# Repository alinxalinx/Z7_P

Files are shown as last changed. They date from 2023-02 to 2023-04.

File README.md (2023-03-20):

# Xilinx Zynq Ultrascale+ MPSoC Series Development Board Z7_P
## Introduction to Development Board
The entire structure of the development board is designed based on our consistent core board+extension board pattern. Core board and expansion board
High speed inter board connectors are used for connection. The backplane extends a variety of peripheral interfaces for the core board, including 1 channel FMC_ LPC, 1-way M.2 SSD interface, 1-way mini_ DP interface, 2-way SFP optical fiber interface, 4 USB 3.0 interfaces, 2-way Gigabit Ethernet interface, 1-way HDMI
Input, 1-way HDMI output, 2-way UART interface, 1-way PCIEX8 gold finger, 2-way CAN bus interface, 2-way
RS485 interface, 1-way MIPI interface, some key LEDs.
## Key Features
1. One PCIe 3.0 x8 (pl) with a rate of 8Gbps
2. 1-way M.2 interface, PCIEx1 (ps), speed 6Gbps
3. 1-channel DP output interface, mini DP (ps), maximum support 4kx2k@30fps Output
4. 4-way USB 3.0 interface, USB (ps), speed 5.0Gbps, flat USB interface (USB Type A)
5. One channel of HDMI2.0 input interface and one channel of HDMI2.0 output interface are both at the pl end, with the highest 4kx2k@60fps output
6. 2-way Gigabit Ethernet interface, jl2121, 1-way ps, 1-way pl, rgmii interface
7. 2-way SFP optical fiber interface (pl), with a speed of 12.5Gb/s
8. 1 Micro SD card holder (ps)
9. 1-way mipi interface (pl), 15PIN FPC connector, 2 lane data, 1 pair of clocks
10. 1 FMC LPC expansion port
11. 2-way CAN communication interface (ps)
12. 2-way 485 communication interface (PL)
13. One RTC real-time clock, 32.768KHz passive clock (ps)
14. EEPROM and temperature sensor, one EEROM 4Kbit (2x256x8bit) (ps), one LM75 temperature chip (ps), with an accuracy of 0.5 degrees
15. Four LED lights, one Done indicator light, one power supply, one PL control, and one PS control
16. One reset button reset, two user buttons
17. One 4-digit dial switch, and the board supports four startup modes
18. Size 200mm x 106.65mm
19. Power supply 12v/3A

# Z7_P Demo Project
## Description
This is vivado factory demo project for ALINX board.
## Requirement
* Vivado 2020.1
* Z7_P Development Board
## Create Vivado Project
* Download recent release ZIP archive.
* Create new project folder.
* Extract the download ZIP to the new project folder.

There are two methods to create vivado project as below:
### Create Vivado Project in Vivado tcl console
1. Open Vivado software and switch to "**auto_create_project**" path with **cd** command and **Enter**
```
cd \<archive extracted location\>/vivado/auto_create_project
```
2. Type **source ./create_project.tcl** and **Enter**
```
source ./create_project.tcl
```

### Create Vivado Project using bat
1. In "**auto_create_project**" folder, there is "**create_project.bat**", open it in edit mode, and change to your own vivado software installation path. Save and close.
```
CALL E:\XilinxVitis\Vivado\2020.1\bin\vivado.bat -mode batch -source create_project.tcl
PAUSE
```
2. Double click bat file in Windows environment

For more information, please post on the [ALINX Website] (https://www.alinx.com/en).

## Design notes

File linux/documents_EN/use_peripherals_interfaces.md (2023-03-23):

[Back to Home](../)
## Use the interfaces and peripherals on the development board in LINUX
---
-These interfaces and peripherals are available on the Z7-P development boards :\
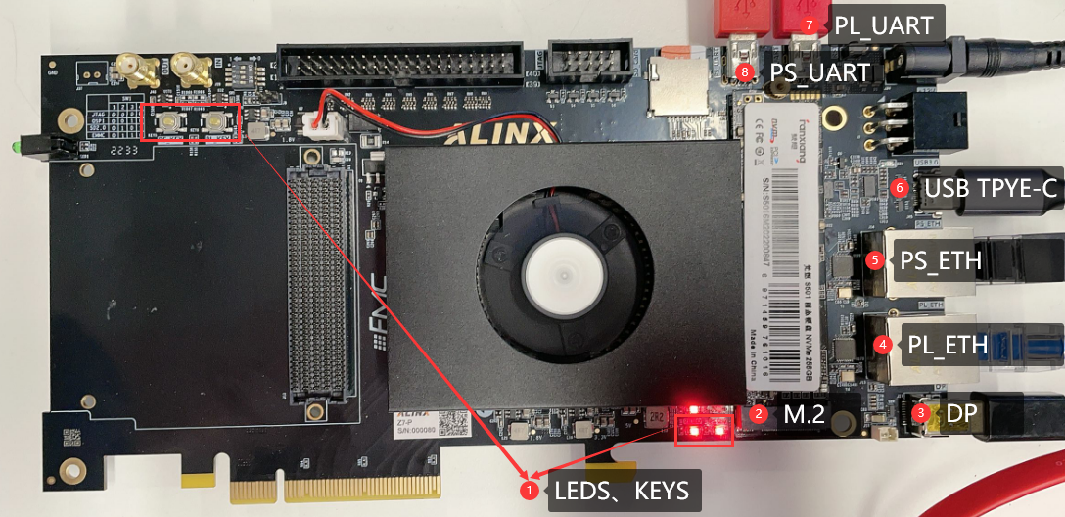
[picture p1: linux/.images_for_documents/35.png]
\
①LEDS、KEYS\
②M.2\
③DP\
④PL_ETH\
⑤PS_ETH\
⑥USB TYPE-C\
⑦PL_UART\
⑧PS_UART\
⑨EMMC(Not visible in the image)\
⑩EEPROM(Not visible in the image)\
⑪QSPI FLASH(Not visible in the image)\
⑫RTC(Not visible in the image)\
⑬LM75(Not visible in the image)\
PS : In the Linux system on the development board created earlier, I integrated some scripts in Path *~/shells_for_testing_peripheral_devices/* to test these interfaces and peripherals. You can also refer to these scripts to use these interfaces and peripherals :\
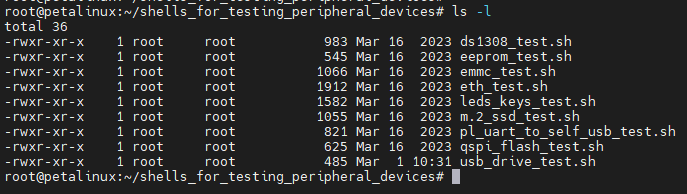
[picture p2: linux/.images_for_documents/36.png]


---
### ①LEDS、KEYS
#### 1.1LEDs and KEYs on the development board
In addition to the POWER light and the RESET button, there are two sets of LEDs and KEY on the development board, namely, the LED and KEY on the PS side and the LED and KEY on the PL side :\
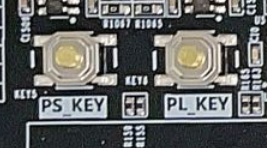
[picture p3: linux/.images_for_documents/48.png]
\
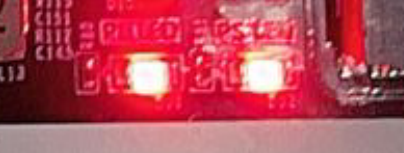
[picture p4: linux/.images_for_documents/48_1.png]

#### 1.2How to use LEDs and KEYs in Linux
Using LEDs and KEYs is actually configuring and using GPIO. In Linux, you only need to know the GPIO number to use the corresponding IO port. The GPIO number of PS_LED is 377, the GPIO number of PS_KEY is 373, the GPIO number of PL_LED is 507, and the GPIO number of PL_KEY is 510.\
The IO corresponding to an LED needs to be configured for output. Taking a PS_LED as an example, the steps to use GPIO output are as follows :
```
#Export the corresponding port
echo 377 >> /sys/class/gpio/export
#Set this port as output
echo out >> /sys/class/gpio/gpio377/direction
#Make this port output high level to turn on the LED
echo 1 >> /sys/class/gpio/gpio377/value
#Make this port output low level to turn off the LED
echo 0 >> /sys/class/gpio/gpio377/value
```
The IO corresponding to KEY needs to be configured as output. Taking PL_KEY as an example, the steps to use GPIO input are as follows :
```
#Export the corresponding port
echo 510 >> /sys/class/gpio/export
#Set this port as input
echo in >> /sys/class/gpio/gpio510/direction
#Read the current level state of this IO
cat /sys/class/gpio/gpio510/value
```

#### 1.3Use the built-in scripts to test LEDs and KEYs
Run the *~/shells_for_testing_peripheral_devices/* script in *leds_keys_test.sh* (*ps: Press **ctrl+c** to exit the script.*). Then you can use PS_KEY to control the turning on and off of the PS_LED, and PL_KEY to control the turning on and off of the PS_LED :\


---
### ②M.2
#### 2.1What is M.2
M.2 is a high-speed, low-power interface for connecting external devices, such as solid-state hard disk, NVMe devices, etc.\
M.2 Interface consists of PCI Express (PCIe) and SATA (Serial ATA) protocols, which can be used for data transmission, storage and communication. PCIe protocol provides faster transmission speed and more bandwidth, while SATA protocol is more suitable for low-power and high-capacity storage devices.
#### 2.2Use M.2 interface in the system
Take SSD equipment as an example, connect SSD on the M.2 interface of the development board (please do not operate with power) :\
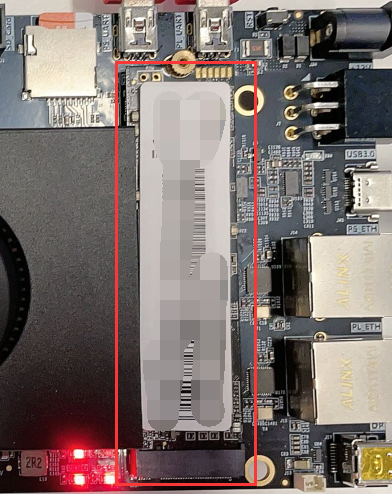
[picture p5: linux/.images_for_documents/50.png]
\
Then start the development board and log in to Linux. If you can find */dev/nvme0n1*, it means that the SSD has been successfully recognized.\
If this SSD has been partitioned, you can also find the device operation files corresponding to partitions like */dev/nvme0n1p1*, */dev/nvme0n1p2* and so on.\
If the SSD does not have a partition or the file system format of the partition is not supported by the Linux system, you can use the **fdisk** tool to allocate the partition, use the **mkfs** tool to set the file system formart, and use the **mount** command to mount it.
For example, the following command will delete the first partition of  */dev/nvme0n1*  and create a new partition, then format the partition into ext4 and mount it to */run/media/nvme0n1p1* :\
```
#Unmount partition
umount /dev/nvme0n1p1
#Delete a partition of /dev/nvme0n1 and create a new partition
echo "d

n
p
1

w
" | fdisk /dev/nvme0n1
#Format the /dev/nvme0n1p1 partition into ext4
echo "y

" | mkfs.ext4 /dev/nvme0n1p1
#mount /dev/nvme0n1p1 on /run/media/nvme0n1p1
mount /dev/nvme0n1p1 /run/media/nvme0n1p1
```
After mounting, you can operate on files in the mounted path, and these files will eventually be saved in the SSD.
#### 2.3Use the built-in script in Linux to test M.2 SSD
Run the *m.2_ssd_test.sh*  script in *~/shells_for_testing_peripheral_devices/* :\
\
Different information will be printed according to the usage of your SSD, but as long as the M.2 interface and SSD are intact, \"*ssd read write OK* \" will be output.

---
### ③DP
#### 3.1What is DP
DP (DisplayPort) interface is a digital video and audio interface standard used to connect computers, televisions, monitors, audio and other equipment. It is an open standard developed by Video Electronics Standards Association (VESA).\
There are two physical interfaces of DP interface, one is the standard DP interface in rectangular shape, and the other is the Mini DP interface in circular shape. The Mini DP interface is used on our development board.
#### 3.2Using DP in Linux
Connect DP to the display, and you can see the desktop of Macthbox after the system is started :\
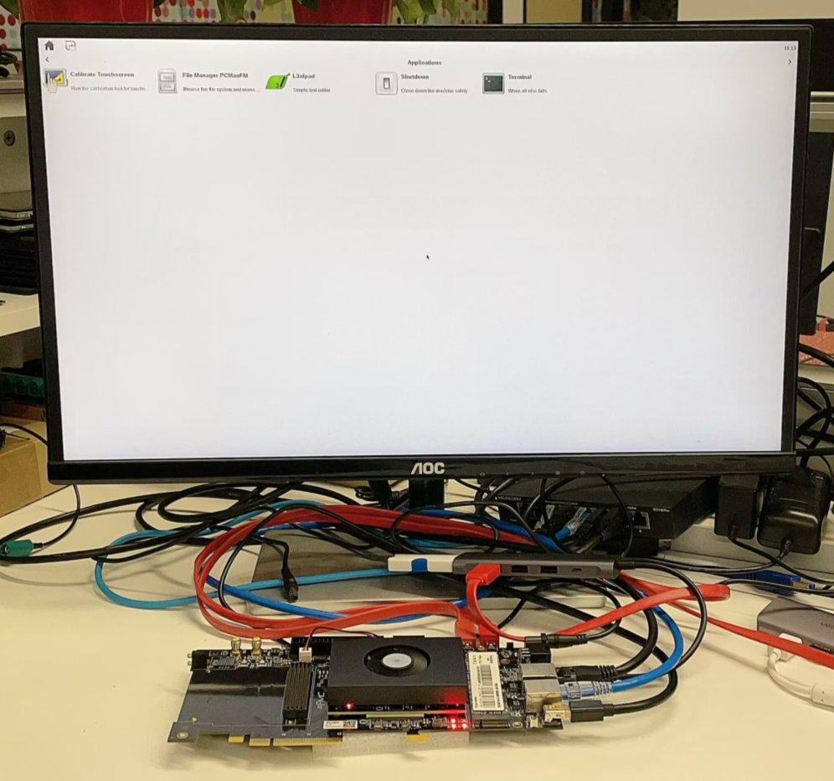
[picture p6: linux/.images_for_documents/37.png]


---
### ④PL_ETH
**See ⑤PS_ETH**。

---
### ⑤PS_ETH
#### 5.1What is ETH
In the Linux operating system, \"ETH\" usually refers to the network interface device, which is the hardware device used to communicate between the computer and the network. In Linux, you can use the *ifconfig* command to manage and configure network interface devices. The development board and other network devices can be connected in the same network through the ETH interface for data transmission.\
In the Ethernet protocol, each device is assigned a unique MAC address for identification and communication in the network. When computers send data through network interface devices, they will be encapsulated in Ethernet frames and routed and transmitted using MAC addresses.\
The PS_ETH on the development board is the ETH on the PS side, and the PS_ETH is the ETH on the PL side implemented by IP, but their use methods are the same in the system.
#### 5.2Using ETH in Linux
Connect PS_ETH and PL_ETH (such as through network router or network switch) to the LAN :\
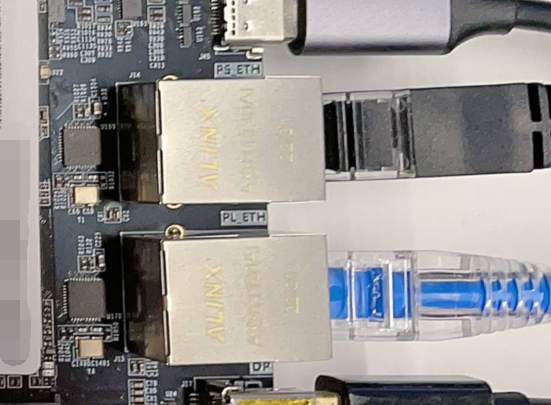
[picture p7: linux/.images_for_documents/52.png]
\
Then power on the development board, log in to the system, and use *ifconfig* to view the current ETH status :\
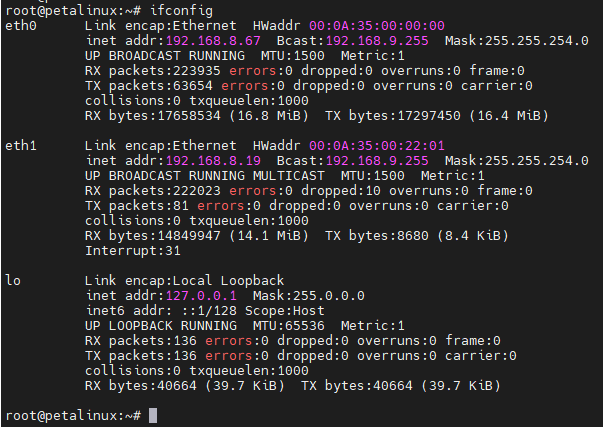
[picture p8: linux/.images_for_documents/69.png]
\
If your router or switch supports DHCP, both eth0 and eth1 will be automatically connected and be assigned an IP address.\
If no IP address is assigned, you need to use the following command to assign it manually, for example :\
`ifconfig eth0 192.168.8.67`\
The *ifconfig* command can also be used to set the subnet mask; If the MAC address needs to be modified, */etc/network/interfaces* needs to be modified; If you want to set the gateway, you need to use command **route**; If you need to modify DNS, you need to modify */etc/resolv.conf*. The relevant configuration will not be detailed, generally, as long as you connect to the LAN through the network cable, you can use eth0 directly after the system is powered on.\
If you want to use eth1, you need to set the default gateway of eth1. The address of the gateway depends on your LAN. If your eth1 and eth0 are connected to the same segment of the same LAN, you can refer to the settings of eth0, for example :
```
#Use route to view the gateway of eth0 first
route
#Set the default gateway of eth1 to be the same as eth0. For example the above route command shows that the default gateway of eth0 is 192.168.8.1
route add default gw 192.168.8.1 eth1
#Use the route command to check and confirm the default gateway of eth1
route
```
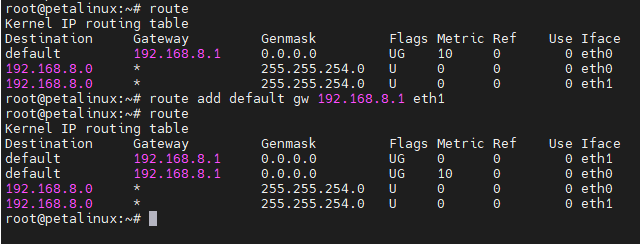
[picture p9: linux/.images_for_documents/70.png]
\
You can use the **ping** command to test the network connection and disconnection, set the number of pings through the **-c** parameter, and select the network interface through the **-I**(uppercase i) parameter :\
`ping -c 1 -I eth1 www.baidu.com`\
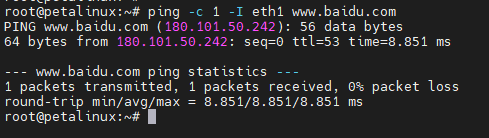
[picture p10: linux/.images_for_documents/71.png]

#### 5.3Use the built-in script in Linux to test ETH
Run the *eth_test.sh*  script in *~/shells_for_testing_peripheral_devices/*. This script can be followed by a parameter, that is, the address you want to ping. For example, here I ping www.baidu.com. If no parameter is added, the default is ping *www.google.com* :\
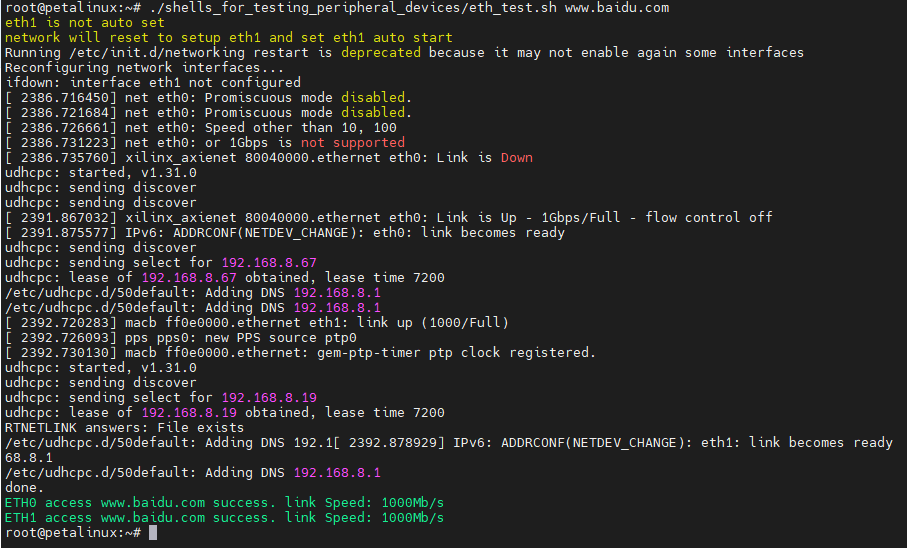
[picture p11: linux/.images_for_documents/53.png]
\
Finally, the result of the ping and the speed of the network interface link will be print.

---
### ⑥USB TYPE-C
#### 6.1What is USB
USB is the abbreviation of Universal Serial Bus. It is a universal data transmission standard used to connect computers or other devices with other devices, including printers, keyboards, mice, scanners, digital cameras, mobile devices and other external devices.\
With the continuous development of technology, the version of USB is also constantly updated. USB 1.0 is the earliest version and the transmission speed is very slow, but with the introduction of USB 2.0, the transmission speed has been significantly improved. USB 3.0 and USB 3.1 are faster versions, providing higher transmission speed and more power. At the same time, USB can also support different data transmission protocols, including HID (human interface device), audio, video and storage devices.\
Our development board has a USB TYPE-C interface that can be connected to a HUB with a TYPE-C interface. Of course, it also connects to other TYPE-C interface devices.\
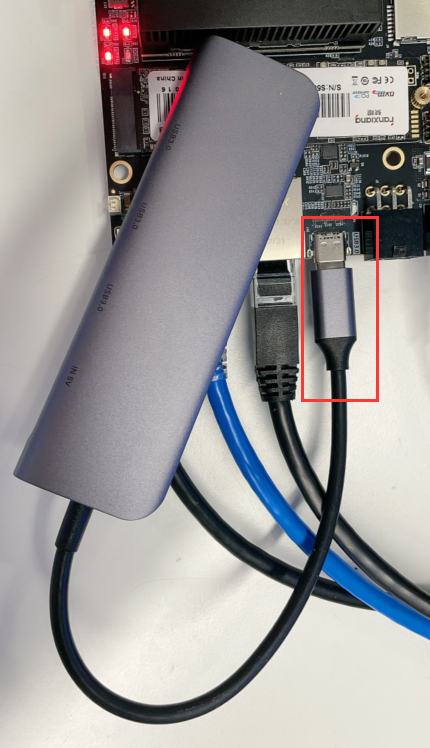
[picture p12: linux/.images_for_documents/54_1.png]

#### 6.2Using USB on Linux systems
In fact, common USB devices can be used directly on this system. For example, the mouse and keyboard can be used directly with the desktop. If you use the storage tools such as USB flash disk, you need to pay attention to the partition and file system format. You can refer to the partition and format method of SSD in **②M.2**. After the USB flash disk is connected to the system, the device operation files are generally */dev/sda1*, */dev/sda2*, etc.
#### 6.3Use the built-in script in Linux to test USB Drive
Run the *usb_drive_test.sh*  script in *~/shells_for_testing_peripheral_devices/* ( *ps：This system does not support the NTFS file system, so the USB flash drive of the NTFS partition cannot be used directly* ) :\


---
### ⑦PL_UART
#### 7.1What isPL_UART
PL_UART is different from PS_UART is the UART interface of the FPGA (also called PL) in the ZYNQMP chip.
#### 7.2Using PL_UART in Linux
Connect the PL_UART to the PC(***The driver of CP210x needs to be installed on the PC*** ).\
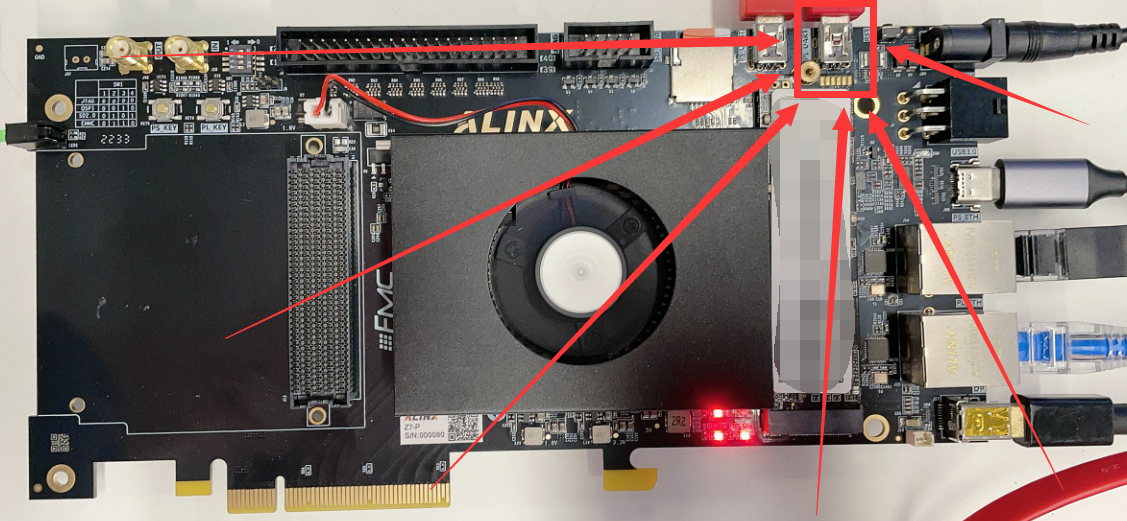
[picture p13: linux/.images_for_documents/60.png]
\
Open the serial port tool, select the corresponding COM, and set the baud rate to 115200 :\
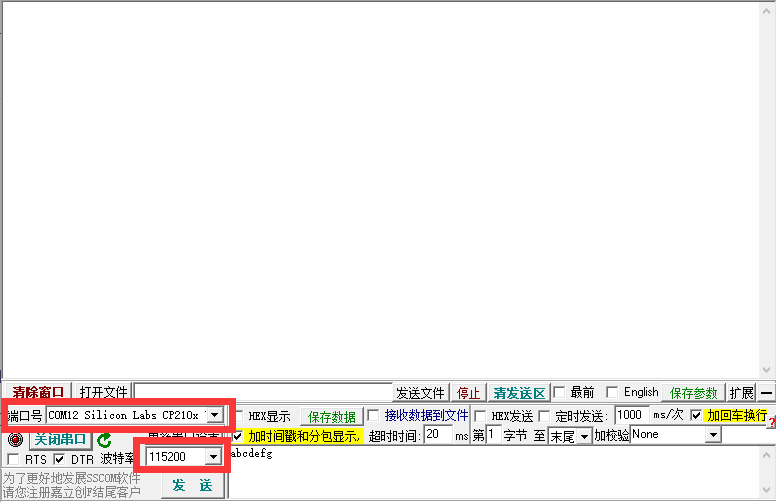
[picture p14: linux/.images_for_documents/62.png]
\
**The number of COM depends on your PC. If your PS_UART and PL_UART are all connected to PC, you can see at least two COM suffixes with *Silicon Labs CP210x USB to UART Bridge* :**\
\
In the Linux system of the development board, the PL_UART device is */dev/ttyPS3*, and the default baud rate is 9600. You can use this command to set the baud rate.\
`stty -F /dev/ttyPS3 ispeed 115200 ospeed 115200 cs8`\
We set it to 115200 corresponding to the setting of the serial port tool, and then use the following command to print the data received by UART :\
`cat /dev/ttyPS3`\
\
Then send some data in the serial port tool, and you can see that the system has received these data :\
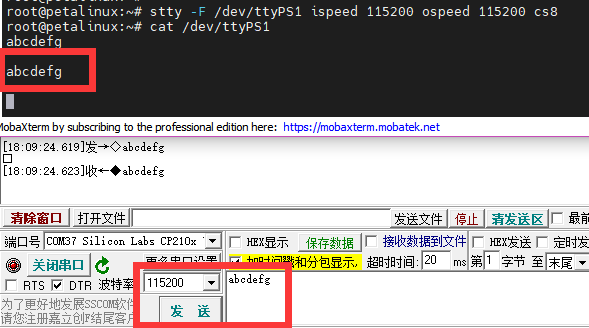
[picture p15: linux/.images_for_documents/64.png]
\
Press *ctrl c* on the keyboard to exit the *cat /dev/ttyPS3* command, and then use the following command to send data \"*PL_UART test*\" to the PC through PL_UART. The serial port tool can receive data:\
`echo "PL_UART test" > /dev/ttyPS3`\
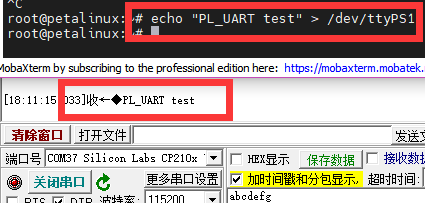
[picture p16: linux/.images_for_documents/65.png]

#### 7.3Use the built-in script in Linux to test PL_UART
Connect the PL_UART to any USB port on the development board :\
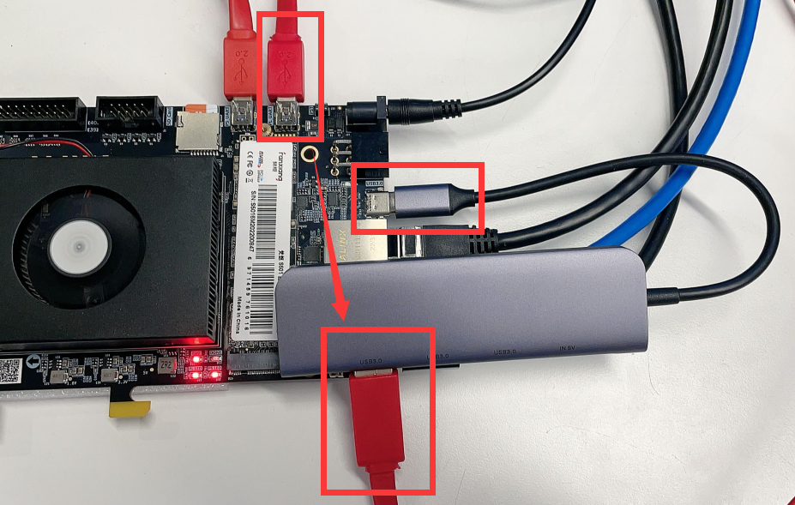
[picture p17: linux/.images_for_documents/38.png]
\
Run the *pl_uart_to_self_usb_test.sh*  script in *~/shells_for_testing_peripheral_devices/* :\
\
Output \"*pl uart to self usb test OK* \" indicates that the UART is intact(ps: this script also verifies that the USB interface is intact).

---
### ⑧PS_UART
#### 8.1What is PS_UART
UART is a communication protocol, which is called "Universal Asynchronous Receiver/Transmitter". It is a serial communication protocol that can be used to transmit data between microcontrollers, sensors, computer peripheral devices, communication devices, etc.\
UART uses two signal lines for data transmission: one is the data line (TX), which is responsible for sending data; The other is the receiving line (RX), which is responsible for receiving data. UART communication uses asynchronous transmission mode, that is, the clock signals of both sides of the communication are not synchronized, and the start bit, stop bit and parity bit need to be added in the data transmission to ensure the correctness of the data.\
The main advantages of UART are simple, flexible and widely used. Because it is a general protocol that can communicate between different devices, it is widely used in embedded systems and communication fields.\
PS_ UART is the UART interface of ARM end (also called PS end) in ZYNQMP chip.
#### 8.2Using PS_UART in Linux
PS_UART is used as the default terminal console for Linux in our system. Connect PS_UART to the PC(***The driver of CP210x needs to be installed on the PC***) :\
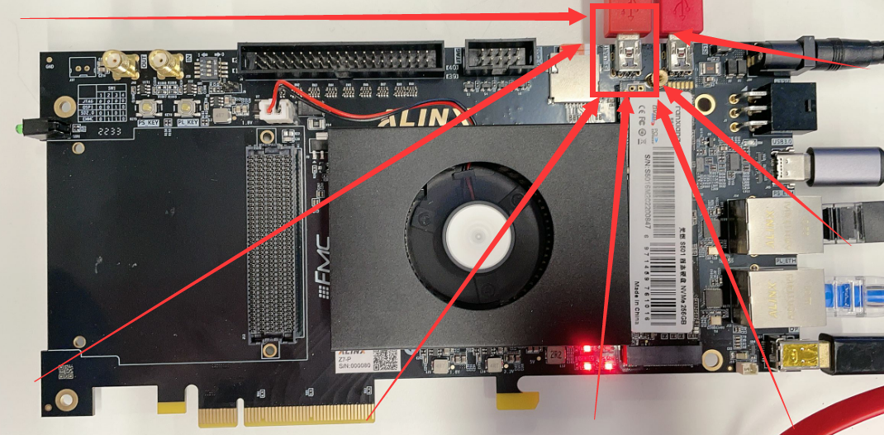
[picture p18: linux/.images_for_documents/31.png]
\
Open the corresponding COM with the serial port tool, set the baud rate to 115200, close the flow control, and click the OK button :\
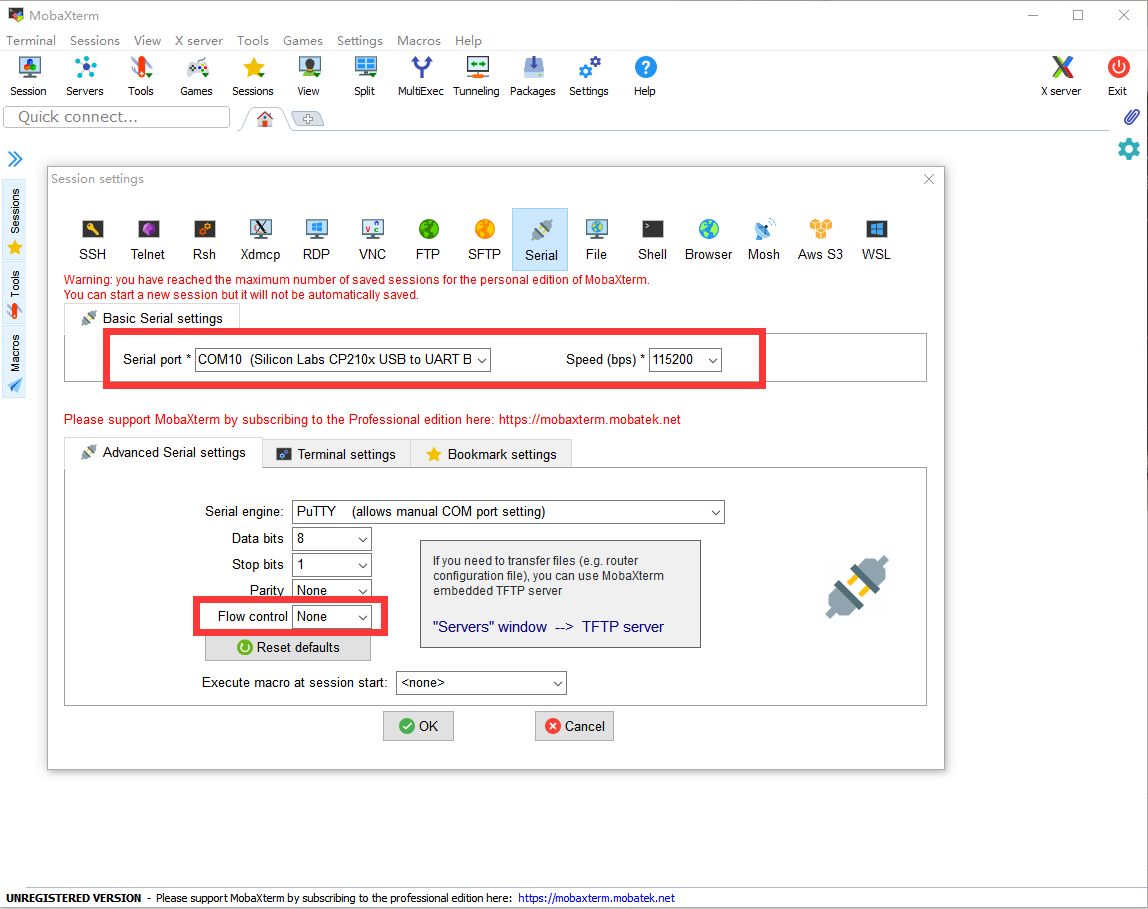
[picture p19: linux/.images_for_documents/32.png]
\
After starting the development board, you can see the print information in the serial port tool :\
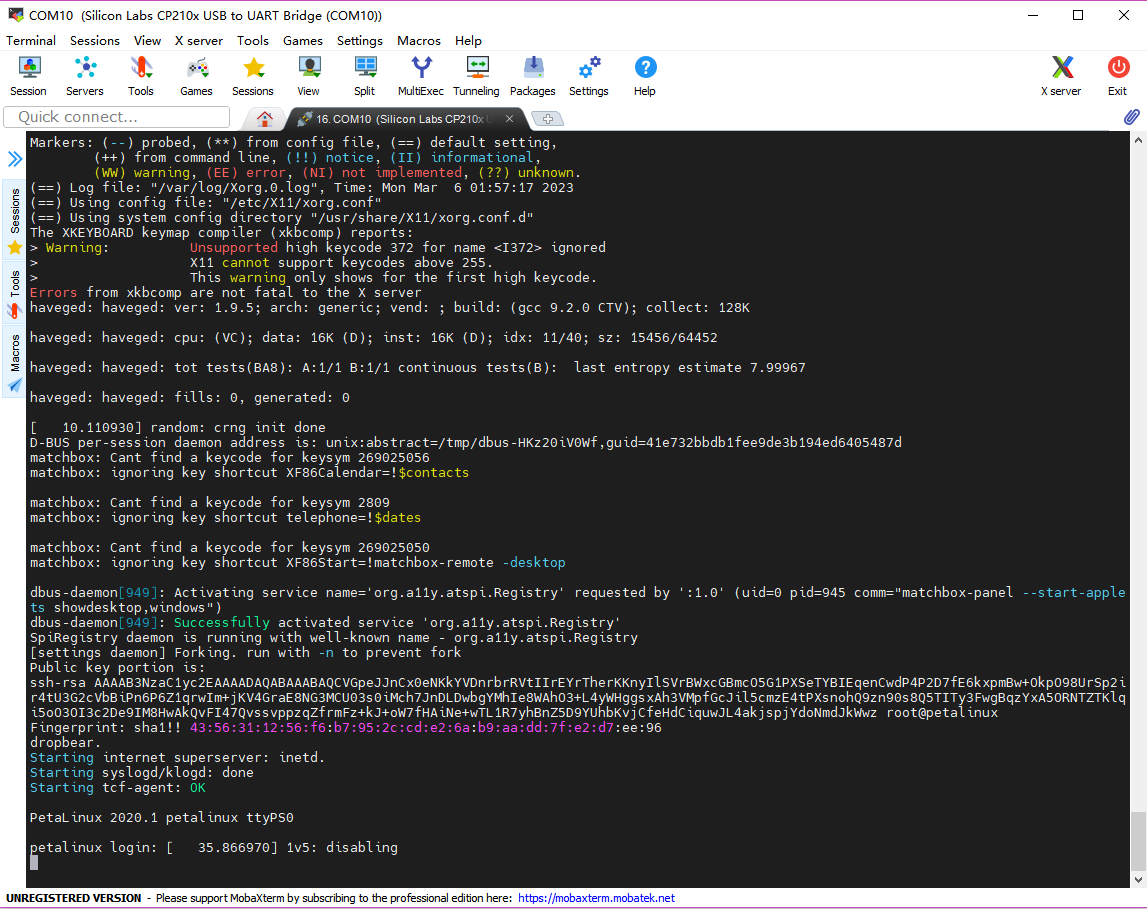
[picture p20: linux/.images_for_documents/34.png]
\
The device of PS_UART in our Linux system is */dev/ttyPS0*. You can use PS_UART interface transmits data by using the `echo "PS_UART test" > /dev/ttyPS0` command :\
\
You can see that the serial port has echo. But PS_UART is used for terminal console, so it is not recommended to operate */dev/ttyPS0*.

---
### ⑨EMMC
#### 9.1What is EMMC
EMMC (Embedded MultiMediaCard) is a storage device widely used by embedded devices. It integrates flash memory chip, controller, host interface and flash memory management software into a small package. With its small size, low power consumption and high cost performance, eMMC is a common choice in embedded device storage solutions.\
EMMC is mainly used in mobile devices (such as smart phones, tablets, digital cameras, etc.) and embedded devices in automotive, industrial control and other fields. It provides a high-speed and reliable storage solution, supports fast startup and data reading and writing, and can store operating system, application programs, media files and other data.\
An 8G EMMC is integrated on our development board.
#### 9.2Using EMMC on Linux
The operation file of EMMC in Linux system is */dev/mmcblk0*. The use method is similar to that of SSD in **⑧M.2** : set the partition, format the partition, and finally mount the partition. for example :
```
#Unmount partition
umount /dev/mmcblk0p1
#Delete a partition of /dev/mmcblk0 and create a new partition
echo "d

n
p
1

w
" | fdisk /dev/mmcblk0
#Format the /dev/mmcblk0p1 partition into ext4 format
echo "y

" | mkfs.ext4 /dev/mmcblk0p1
#mount /dev/mmcblk0p1 on /media/sd-mmcblk0p1
mount /dev/mmcblk0p1 /media/sd-mmcblk0p1
```
After mounting, you can operate on files in the mounted path, and these files will eventually be saved in EMMC.
#### 9.3Use the built-in script in Linux to test EMMC
Run the *emmc_test.sh* script in *~/shells_for_testing_peripheral_devices/*  :\


---
### ⑩EEPROM
#### 10.1What is EEPROM
EEPROM is a non-volatile memory (NVM), which is an improved version of the electrically erasable programmable read-only memory (EPROM). EEPROM can be erased and programmed by electronic signals.\
EEPROM is usually used to store a small amount of data, such as configuration information on the chip, product serial number, encryption key, etc. In some electronic devices, EEPROM can also be used to store user settings and personal data.\
Compared with flash memory, EEPROM has faster reading speed and higher durability, but smaller capacity. Compared with DRAM, EEPROM has longer data retention time, but slower write speed.
#### 10.2Using EEPROM on Linux
The operating file of eeprom in the system is */sys/bus/i2c/devices/1-0050/eeprom*.\
Use the following command to write data to eeprom :\
`echo -e "test e2prom\n" > /sys/bus/i2c/devices/1-0050/eeprom`\
Use the following command to view the contents of eeprom :\
`cat /sys/bus/i2c/devices/1-0050/eeprom`\

#### 10.3Use the built-in script in Linux to test EEPROM
Run the *eeprom_test.sh* script in *~/shells_for_testing_peripheral_devices/*  :\


---
### ⑪QSPI FLASH
#### 11.1What is QSPI FLASH
Flash is a kind of high-speed flash memory, which is often used in embedded systems and other applications to store program code, configuration data and other information.\
QSPI Flash is a flash chip based on SPI interface. It communicates through four parallel data lines (quad interfaces). Compared with traditional SPI Flash, it can achieve faster data transmission speed, usually up to tens of MHz. The capacity of QSPI Flash is usually between a few megabytes and tens of megabytes.\
QSPI Flash has many advantages, including fast read and write speed, low power consumption, erasability, easy integration and use, etc. In addition, it can be programmed and erased by software without any external equipment or signal line.
#### 11.2Using QSPI FLASH on Linux systems
In the current Linux system, QSPI FLASH is used to store the environment variables of u-boot. If you modify the environment variables of u-boot, you need to be careful when operating QSPI FLASH.
The operation file of QSPI FLASH in the system is */dev/mtd0*.
The FLASH device needs to be erased before writing. Use the following command to erase the first sector of QSPI FLASH :\
`flash_erase /dev/mtd0 0 1`\
*/dev/mtd0* is a block device. You can use the **dd** command to read or write files to */dev/mtd0*.\
Write the file to */dev/mtd0 with the following command* :
```
touch /home/root/.qspiflashwrite
echo "qspiflash test" > /home/root/.qspiflashwrite
dd of=/dev/mtd0 if=/home/root/.qspiflashwrite bs=4096 count=1
```
Use the following command to read data from */dev/mtd0* to a file :
```
touch /home/root/.qspiflashread
dd if=/dev/mtd0 of=/home/root/.qspiflashread  bs=4096 count=1
```
#### 11.3Use the built-in script in Linux to test QSPI FLASH
Run the *qspi_flash_test.sh* script in *~/shells_for_testing_peripheral_devices/*  :\


---
### ⑫RTC
#### 12.1What is RTC
The Real Time Clock (RTC) unit provides an accurate time reference for the entire system and application software.
#### 12.2Using RTC on Linux systems
In our Linux system, the device operation file of RTC is */dev/rtc0*. You can use the **hwclock** command to read and write */dev/rtc0*. For example:
```
#Set the system time to "2023-03-01 10:30:00"
date --set="2023-03-01 10:30:00"
#Write the system time to/dev/rtc0
hwclock -f /dev/rtc0 -w
#Update the system time with the time in /dev/rtc0
hwclock -f /dev/rtc0 -r
```

#### 12.3Use the built-in script in Linux to test RTC
Run the *ds1308_test.sh* script in *~/shells_for_testing_peripheral_devices/* :\


---
### ⑬LM75
#### 13.1What is LM75
LM75 is a digital temperature sensor chip produced by Texas Instruments. It can measure the ambient temperature and communicate with other devices through I2C bus. It is a digital temperature sensor chip with stable performance, high accuracy and good reliability.
#### 13.2Using LM75 on Linux systems
The temperature value collected by LM75 can be obtained by directly reading */sys/bus/i2c/devices/1-0048/hwmon/hwmon0/temp1_input* in Linux, **the unit of this data is m°C**:\
`cat /sys/bus/i2c/devices/1-0048/hwmon/hwmon0/temp1_input`\
\
The temperature read here is 30625m°C, equal to 30.625°C.

---
---
- Visit [ALINX official website](https://www.alinx.com) for more information.

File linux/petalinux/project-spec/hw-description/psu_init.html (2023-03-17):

- Zynq UltraScale+ PS Summary Viewer

Zynq UltraScale+ Summary Report

User Configurations

MIO Configurations

CLK Configurations

DDR Configurations

GT Configurations

This design is targeted for xczu7ev board (part number: xczu7ev-ffvc1156-2-i)

## Zynq UltraScale+ Design Summary

Device | xczu7ev
SpeedGrade | -2
Part | xczu7ev-ffvc1156-2-i
Description | Zynq UltraScale+ PS Configuration Report
Vendor | Xilinx

## MIO Table View

MIO Pin | Peripheral | Signal | IO Type | Speed | Pullup | Direction | Drive Strength(mA)
MIO 0 | Quad SPI Flash | sclk_out | cmos | fast | pullup | out | 12
MIO 1 | Quad SPI Flash | miso_mo1 | cmos | fast | pullup | inout | 12
MIO 2 | Quad SPI Flash | mo2 | cmos | fast | pullup | inout | 12
MIO 3 | Quad SPI Flash | mo3 | cmos | fast | pullup | inout | 12
MIO 4 | Quad SPI Flash | mosi_mi0 | cmos | fast | pullup | inout | 12
MIO 5 | Quad SPI Flash | n_ss_out | cmos | fast | pullup | out | 12
MIO 6 | Feedback Clk | clk_for_lpbk | cmos | fast | pullup | out | 12
MIO 7 | Quad SPI Flash | n_ss_out_upper | cmos | fast | pullup | out | 12
MIO 8 | Quad SPI Flash | mo_upper[0] | cmos | fast | pullup | inout | 12
MIO 9 | Quad SPI Flash | mo_upper[1] | cmos | fast | pullup | inout | 12
MIO 10 | Quad SPI Flash | mo_upper[2] | cmos | fast | pullup | inout | 12
MIO 11 | Quad SPI Flash | mo_upper[3] | cmos | fast | pullup | inout | 12
MIO 12 | Quad SPI Flash | sclk_out_upper | cmos | fast | pullup | out | 12
MIO 13 | SD 0 | sdio0_data_out[0] | cmos | fast | pullup | inout | 12
MIO 14 | SD 0 | sdio0_data_out[1] | cmos | fast | pullup | inout | 12
MIO 15 | SD 0 | sdio0_data_out[2] | cmos | fast | pullup | inout | 12
MIO 16 | SD 0 | sdio0_data_out[3] | cmos | fast | pullup | inout | 12
MIO 17 | SD 0 | sdio0_data_out[4] | cmos | fast | pullup | inout | 12
MIO 18 | SD 0 | sdio0_data_out[5] | cmos | fast | pullup | inout | 12
MIO 19 | SD 0 | sdio0_data_out[6] | cmos | fast | pullup | inout | 12
MIO 20 | SD 0 | sdio0_data_out[7] | cmos | fast | pullup | inout | 12
MIO 21 | SD 0 | sdio0_cmd_out | cmos | fast | pullup | inout | 12
MIO 22 | SD 0 | sdio0_clk_out | cmos | fast | pullup | out | 12
MIO 23 | SD 0 | sdio0_bus_pow | cmos | fast | pullup | out | 12
MIO 24 | | | cmos | fast | pullup | | 12
MIO 25 | | | cmos | fast | pullup | | 12
MIO 26 | GPIO1 MIO | gpio1[26] | cmos | fast | pullup | inout | 12
MIO 27 | DPAUX | dp_aux_data_out | cmos | fast | pullup | out | 12
MIO 28 | DPAUX | dp_hot_plug_detect | cmos | fast | pullup | in | 12
MIO 29 | DPAUX | dp_aux_data_oe | cmos | fast | pullup | out | 12
MIO 30 | DPAUX | dp_aux_data_in | cmos | fast | pullup | in | 12
MIO 31 | GPIO1 MIO | gpio1[31] | cmos | fast | pullup | inout | 12
MIO 32 | USB0 Reset | reset | cmos | fast | pullup | out | 12
MIO 33 | GPIO1 MIO | gpio1[33] | cmos | fast | pullup | inout | 12
MIO 34 | I2C 0 | scl_out | cmos | fast | pullup | inout | 12
MIO 35 | I2C 0 | sda_out | cmos | fast | pullup | inout | 12
MIO 36 | GPIO1 MIO | gpio1[36] | cmos | fast | pullup | inout | 12
MIO 37 | PCIE | reset_n | cmos | fast | pullup | out | 12
MIO 38 | GPIO1 MIO | gpio1[38] | cmos | fast | pullup | inout | 12
MIO 39 | GPIO1 MIO | gpio1[39] | cmos | fast | pullup | inout | 12
MIO 40 | GPIO1 MIO | gpio1[40] | cmos | fast | pullup | inout | 12
MIO 41 | GPIO1 MIO | gpio1[41] | cmos | fast | pullup | inout | 12
MIO 42 | UART 0 | rxd | cmos | fast | pullup | in | 12
MIO 43 | UART 0 | txd | cmos | fast | pullup | out | 12
MIO 44 | GPIO1 MIO | gpio1[44] | cmos | fast | pullup | inout | 12
MIO 45 | SD 1 | sdio1_cd_n | cmos | fast | pullup | in | 12
MIO 46 | SD 1 | sdio1_data_out[0] | cmos | fast | pullup | inout | 12
MIO 47 | SD 1 | sdio1_data_out[1] | cmos | fast | pullup | inout | 12
MIO 48 | SD 1 | sdio1_data_out[2] | cmos | fast | pullup | inout | 12
MIO 49 | SD 1 | sdio1_data_out[3] | cmos | fast | pullup | inout | 12
MIO 50 | SD 1 | sdio1_cmd_out | cmos | fast | pullup | inout | 12
MIO 51 | SD 1 | sdio1_clk_out | cmos | fast | pullup | out | 12
MIO 52 | USB 0 | ulpi_clk_in | cmos | fast | pullup | in | 12
MIO 53 | USB 0 | ulpi_dir | cmos | fast | pullup | in | 12
MIO 54 | USB 0 | ulpi_tx_data[2] | cmos | fast | pullup | inout | 12
MIO 55 | USB 0 | ulpi_nxt | cmos | fast | pullup | in | 12
MIO 56 | USB 0 | ulpi_tx_data[0] | cmos | fast | pullup | inout | 12
MIO 57 | USB 0 | ulpi_tx_data[1] | cmos | fast | pullup | inout | 12
MIO 58 | USB 0 | ulpi_stp | cmos | fast | pullup | out | 12
MIO 59 | USB 0 | ulpi_tx_data[3] | cmos | fast | pullup | inout | 12
MIO 60 | USB 0 | ulpi_tx_data[4] | cmos | fast | pullup | inout | 12
MIO 61 | USB 0 | ulpi_tx_data[5] | cmos | fast | pullup | inout | 12
MIO 62 | USB 0 | ulpi_tx_data[6] | cmos | fast | pullup | inout | 12
MIO 63 | USB 0 | ulpi_tx_data[7] | cmos | fast | pullup | inout | 12
MIO 64 | Gem 3 | rgmii_tx_clk | cmos | fast | pullup | out | 12
MIO 65 | Gem 3 | rgmii_txd[0] | cmos | fast | pullup | out | 12
MIO 66 | Gem 3 | rgmii_txd[1] | cmos | fast | pullup | out | 12
MIO 67 | Gem 3 | rgmii_txd[2] | cmos | fast | pullup | out | 12
MIO 68 | Gem 3 | rgmii_txd[3] | cmos | fast | pullup | out | 12
MIO 69 | Gem 3 | rgmii_tx_ctl | cmos | fast | pullup | out | 12
MIO 70 | Gem 3 | rgmii_rx_clk | cmos | fast | pullup | in | 12
MIO 71 | Gem 3 | rgmii_rxd[0] | cmos | fast | pullup | in | 12
MIO 72 | Gem 3 | rgmii_rxd[1] | cmos | fast | pullup | in | 12
MIO 73 | Gem 3 | rgmii_rxd[2] | cmos | fast | pullup | in | 12
MIO 74 | Gem 3 | rgmii_rxd[3] | cmos | fast | pullup | in | 12
MIO 75 | Gem 3 | rgmii_rx_ctl | cmos | fast | pullup | in | 12
MIO 76 | MDIO 3 | gem3_mdc | cmos | fast | pullup | out | 12
MIO 77 | MDIO 3 | gem3_mdio_out | cmos | fast | pullup | inout | 12

## PS Clocks information

PSS REF CLK : 33.333

Name | Source | Input Frequency (MHz)
APLL | PSS_REF_CLK | 2666.640
DPLL | PSS_REF_CLK | 2399.976
VPLL | PSS_REF_CLK | 2999.970
RPLL | PSS_REF_CLK | 2133.312
IOPLL | PSS_REF_CLK | 2999.970

Peripheral | Requested Frequency (MHz) | Source | Actual Frequency (MHz)
GEM0 freq (MHz) | 125 | IOPLL | 124.998749
GEM3 freq (MHz) | 125 | IOPLL | 124.998749
USB0 freq (MHz) | 250 | IOPLL | 249.997498
QSPI freq (MHz) | 300 | IOPLL | 299.997009
SDIO0 freq (MHz) | 200 | IOPLL | 187.498123
SDIO1 freq (MHz) | 200 | IOPLL | 187.498123
UART0 freq (MHz) | 100 | IOPLL | 99.999001
UART1 freq (MHz) | 100 | IOPLL | 99.999001
I2C0 freq (MHz) | 100 | IOPLL | 99.999001
CPU_R5 freq (MHz) | 533.333 | RPLL | 533.328003
IOU_SWITCH freq (MHz) | 267 | RPLL | 266.664001
LPD_SWITCH freq (MHz) | 533.333 | RPLL | 533.328003
LPD_LSBUS freq (MHz) | 100 | IOPLL | 99.999001
GEM_TSU freq (MHz) | 250 | IOPLL | 249.997498
TIMESTAMP freq (MHz) | 100 | PSS_REF_CLK | 33.333000
PSU__CRL_APB__USB3_REF_CTRL__freqmhz | 20 | IOPLL | 19.999800
PCAP freq (MHz) | 200 | IOPLL | 187.498123
DBG_LPD freq (MHz) | 250 | IOPLL | 249.997498
ADMA freq (MHz) | 533.333 | RPLL | 533.328003
PL0 freq (MHz) | 100 | RPLL | 96.968727
AMS freq (MHz) | 50 | IOPLL | 49.999500
ACPU freq (MHz) | 1333.333 | APLL | 1333.320068
DBG FPD freq (MHz) | 250 | IOPLL | 249.997498
DP VIDEO freq (MHz) | 300 | VPLL | 299.997009
DP AUDIO freq (MHz) | 25 | RPLL | 24.242182
DP STC freq (MHz) | 27 | RPLL | 26.666401
PCIE freq (MHz) | 250 | IOPLL | 249.997498
DDR_CTRL freq MHz) | 600.000 | DPLL | 599.994019
GPU freq (MHz) | 600 | DPLL | 599.994019
GDMA freq (MHz) | 600 | DPLL | 599.994019
DPDMA freq (MHz) | 600 | DPLL | 599.994019
TOPSW_MAIN freq (MHz) | 533.333 | APLL | 444.440033
TOPSW_LSBUS freq (MHz) | 100 | IOPLL | 99.999001
DBG TSTMP freq (MHz) | 250 | IOPLL | 249.997498

## DDR Memory information

Parameter name | Value | Description
ENABLE | 1 | Enable the PS DDR Controller
DDR Interface freq (MHz) | 1200 | --
MEMORY TYPE | DDR 4 | Type of memory interface
DM DBI | Components
BUS WIDTH | 64 Bit | Data width of DDR interface, not including ECC data width
ECC | Disabled | Enables error correction code support
SPEED BIN | DDR4_2400P | Speed Bin
CL | 16 | Column Access Strobe (CAS) latency in memory clock cycles. It refers to the amount of time it takes for data to appear on the pins of the memory module
CWL | 12 | CAS write latency setting in memory clock cycles
DDR AL | 0 | Additive Latency (ns). Increases the efficiency of the command and data bus for sustainable bandwidths
T RCD | 16 | tRCD. Row address to column address delay time. It is the time required between the memory controller asserting a row address strobe (RAS), and then asserting the column address strobe (CAS)
T RP | 16 | Precharge Time is the number of clock cycles needed to terminate access to an open row of memory and open access to the next row
T RC | 45.32 | Row cycle time (ns)
T RAS MIN | 32 | Minimum number of memory clock cycles required between an Active and Precharge command
T FAW | 30.0 | Determines the number of activates that can be performed within a certain window of time
DRAM WIDTH | 16 Bits | Width of individual DRAM components
DEVICE CAPACITY | 8192 MBits | Storage capacity of individual DRAM components
BG ADDR COUNT | 1 | Number of bank group address pins
RANK ADDR COUNT | 0 | Dual-rank or dual-DIMM configuration of DRAM. Addressed using two chip-select bits (CS_N)
BANK ADDR COUNT | 2 | Number of bank address pins
ROW ADDR COUNT | 16 | Number of row address pins
COL ADDR COUNT | 10 | Number of column address bits
C_DDR_RAM_HIGHADDR | 0xFFFFFFFF | --

## GT lanes information

Protocol | GT lane# | Ref Clk Sel | Ref freq (MHz)
PCIe | GT Lane0 | Ref Clk0 | 100
USB0 | GT Lane1 | Ref Clk1 | 26
DP | GT Lane2 | Ref Clk2 | 27

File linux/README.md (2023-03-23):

# Run Linux on Development Boards : Z7-P / 在开发板Z7-P上使用Linux
---
---
## Content in this path / 本路径中的内容 
	│
	└─── linux
		│
		├── hardware
		│	│
		│	└──── Z7-P 
		│		│	
		│	 	└─ design_1_wrapper.xsa	
		│
		├── petalinux
		│
		├── documents_EN
		│	│
		│	├──  make_sd_for_runnging_linux.md	
		│	│
		│	├──  use_petalinux_to_make_linux.md	
		│	│
		│	└──  use_peripherals_interfaces.md
		│
		├── documents_CN
		│	│
		│	├──  make_sd_for_runnging_linux.md	
		│	│
		│	├──  use_petalinux_to_make_linux.md
		│	│
		│	└──  use_peripherals_interfaces.md
		│
		├── auto_config_petalinux_hardware.sh
		│
		├── set_offline_sstate_and_downloads.sh
		│
		└── README.md
---
---
## Documentation Guidelines
- If you want to quickly start a Linux on the development board, please refer to [make_sd_for_runnging_linux.md](./documents_EN/make_sd_for_runnging_linux.md).
- If you want to use Petalinux tool to configure the petalinux project we provide, please refer to [use_petalinux_to_make_linux.md](./documents_EN/use_petalinux_to_make_linux.md).
- If you have successfully started Linux on the development board, and now want to know what interfaces are on the development board and how to use them, please refer to [use_peripherals_interfaces.md](./documents_EN/use_peripherals_interfaces.md).
## 文档指引
- 如果你想快速在开发板上启动Linux，请参考[make_sd_for_runnging_linux.md](./documents_CN/make_sd_for_runnging_linux.md)。
- 如果你想用Petalinux工具来配置我们提供的petalinux工程，请参考[use_petalinux_to_make_linux.md](./documents_CN/use_petalinux_to_make_linux.md)。
- 如果你已经成功在开发板上启动了Linux，现在想知道开发板上有哪些接口以及如何使用，请参考[use_peripherals_interfaces.md](./documents_CN/use_peripherals_interfaces.md)。
---
---
- Visit [ALINX Official Website](https://www.alinx.com) for more information.
- 访问[ALINX官方网站](https://www.alinx.com)以获取更多信息。

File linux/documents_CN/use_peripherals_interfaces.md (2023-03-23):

[返回首页](../)
## 在LINUX中使用开发板上的接口和外设

---
- Z7-P开发板上有这些接口和外设：\
\
①LEDS、KEYS\
②M.2\
③DP\
④PL_ETH\
⑤PS_ETH\
⑥USB TYPE-C\
⑦PL_UART\
⑧PS_UART\
⑨EMMC(图中不可见)\
⑩EEPROM(图中不可见)\
⑪QSPI FLASH(图中不可见)\
⑫RTC(图中不可见)\
⑬LM75(图中不可见)\
PS：在前面制作的开发板上的Linux系统中，我集成了一些脚本在 *~/shells_for_testing_peripheral_devices/* 路径中用于测试这些接口和外设，你也可以参考这些脚本来使用这些接口和外设：\


---
### ①LEDS、KEYS
#### 1.1开发板上的LEDs和KEYs
除POWER灯和RESET按钮外，开发板上有两组LED和KEY，分别是PS端的LED和KEY以及PL端的LED和KEY：\
\

#### 1.2在Linux中使用LEDs和KEYs
使用LEDs和KEYs实际上就是配置和使用GPIO，在Linux中只需要知道GPIO号就可以使用对应的IO口。PS_LED的GPIO号为377，PS_KEY的GPIO号为373，PL_LED的GPIO号为507，PL_KEY的GPIO号为510。\
LED对应的IO需要配置成输出，以PS_LED为例，使用GPIO输出的步骤如下：
```
#导出对应的端口
echo 377 >> /sys/class/gpio/export
#设置这个端口为输出
echo out >> /sys/class/gpio/gpio377/direction
#使这个端口输出高电平，点亮LED
echo 1 >> /sys/class/gpio/gpio377/value
#使这个端口输出低电平，熄灭LED
echo 0 >> /sys/class/gpio/gpio377/value
```
KEY对应的IO需要配置成输出，以PL_KEY为例，使用GPIO输入的步骤如下：
```
#导出对应的端口
echo 510 >> /sys/class/gpio/export
#设置这个端口为输入
echo in >> /sys/class/gpio/gpio510/direction
#读取这个IO当前的电平状态
cat /sys/class/gpio/gpio510/value
```

#### 1.3使用系统内置的脚本测试LEDs和KEYs
运行 *~/shells_for_testing_peripheral_devices/* 中的 *leds_keys_test.sh* 脚本(*ps：按**ctrl+c**组合键退出该脚本。*)。然后可以用PS_KEY控制PS_LED点亮和熄灭，PL_KEY控制PS_LED点亮和熄灭：\


---
### ②M.2
#### 2.1什么是M.2
M.2是一种高速、低功耗的接口，用于连接外部设备，如固态硬盘、NVMe设备等等。\
M.2接口由PCI Express（PCIe）和SATA（串行ATA）两种协议组成，可用于数据传输、存储和通信。PCIe协议提供了更快的传输速度和更多的带宽，而SATA协议则更适合于低功耗和高容量的存储设备。
#### 2.2在系统中使用M.2接口
以SSD设备为例，在开发板的M.2接口上接上SSD(请不要带电操作)：\
\
然后启动开发板，登录Linux，如果能找到 */dev/nvme0n1* 说明SSD已经成功被识别到了。\
如果这个SSD已经被分过区了，那么还能找到 */dev/nvme0n1p1*, */dev/nvme0n1p2* 等分区对应的设备操作文件。\
如果SSD没有分区或者分区的文件系统格式Linux系统不支持，可以使用**fdisk**工具来分配分区，使用**mkfs**命令制作文件系统以及使用mount命令挂载。\
例如下面的命令将会删除 */dev/nvme0n1* 的第一个分区并新建一个分区，再把这个分格式化成ext4并挂载到 */run/media/nvme0n1p1* ：
```
#解挂分区
umount /dev/nvme0n1p1
#删除/dev/nvme0n1的一个分区并新建一个分区
echo "d

n
p
1

w
" | fdisk /dev/nvme0n1
#把/dev/nvme0n1p1分区格式化成ext4格式
echo "y

" | mkfs.ext4 /dev/nvme0n1p1
#挂载/dev/nvme0n1p1到/run/media/nvme0n1p1
mount /dev/nvme0n1p1 /run/media/nvme0n1p1
```
挂载之后，就可以在挂载的路径中操作文件了，而这些文件最终都会被保存在SSD中。
#### 2.3使用系统内置的脚本测试M.2 SSD
运行 *~/shells_for_testing_peripheral_devices/* 中的 *m.2_ssd_test.sh* 脚本：\
\
根据你的SSD的使用情况会用不同打印信息，但只要M.2接口和SSD是完好的最终肯定会输出\"*ssd read write OK* \"。

---
### ③DP
#### 3.1什么是DP
DP (DisplayPort) 接口是一种数字视频和音频接口标准，用于连接计算机、电视、显示器、音响等设备。它是一种开放标准，由 Video Electronics Standards Association (VESA) 组织制定。\
DP 接口的物理接口有两种，一种是矩形形状的标准 DP 接口，另一种是圆形形状的 Mini DP 接口。我们的开发板上使用的就是Mini DP接口。
#### 3.2在Linux中使用DP
把DP连接到显示器上即可，系统启动后可以看到Macthbox的桌面：\


---
### ④PL_ETH
**见⑤PS_ETH**。

---
### ⑤PS_ETH
#### 5.1什么是ETH
在Linux操作系统中，\"ETH\" 通常指的是网络接口设备，它是用于在计算机与网络之间进行通信的硬件设备。在Linux中，可以使用 *ifconfig* 命令来管理和配置网络接口设备。可以通过ETH接口把开发板和其他网络设备连接在同一网络中，以便进行数据传输。\
在以太网协议中，每个设备都被分配一个唯一的MAC地址，以便在网络中进行识别和通信。当计算机通过网络接口设备发送数据时，它们将被封装在以太网帧中，并使用MAC地址进行路由和传输。\
开发板上的PS_ETH是PS端的ETH，PS_ETH则是PL端用IP实现的ETH，但是在系统中他们的使用方法都是一样的。
#### 5.2在Linux中使用ETH
连接PS_ETH和PL_ETH(比如通过路由器或交换机)到局域网：\
\
然后开发板上电，登陆系统，使用 *ifconfig* 可以查看当前ETH的状态：\
\
如果你的路由器或交换机支持DHCP，eth0和eth1都会自动连接并分配到ip。\
如果没有被分配ip则需要用下面的命令来手动分配，例如：\
`ifconfig eth0 192.168.8.67`\
*ifconfig* 命令还可以用来设置子网掩码；如果需要修改MAC地址则需要修改 */etc/network/interfaces* ；如果要设置网关则需要用到**route**命令；如果需要修改DNS则需要修改 */etc/resolv.conf* ，相关的配置就不详细讲了，一般来说只要通过网线连接到局域网，系统上电之后就可以直接使用eth0了。\
如果要使用eth1的话，还需要设置一下eth1的默认网关，网关的ip地址取决于你的局域网，**如果你的eth1和eth0接在同一个局域网的同一个网段则可以参考eth0的设置**，例如：
```
#先用route查看eth0的网关
route
#设置eth1的默认网关和eth0相同，假如上面route命令查看到eth0的默认网关为192.168.8.1
route add default gw 192.168.8.1 eth1
#再用route命令查看确认一下eth1的默认网关
route
```
\
可以使用**ping**命令来测试网络通断，通过 **-c** 参数设置ping的次数，通过 **-I** (大写的i)参数选择网口：\
`ping -c 1 -I eth1 www.baidu.com`\

#### 5.3使用系统内置的脚本设置并测试ETH
运行 *~/shells_for_testing_peripheral_devices/* 中的 *eth_test.sh* 脚本，这个脚本后可以带一个参数，即你想ping的地址，比如这里我ping了一下百度，如果不加参数则默认ping *www.google.com* ：\
\
最后会显示ping的结果和网口link的速度。

---
### ⑥USB TYPE-C
#### 6.1什么是USB
USB是Universal Serial Bus的缩写，它是一种通用的数据传输标准，用于将计算机或其他设备与其他设备连接，包括打印机、键盘、鼠标、扫描仪、数字相机、移动设备和其他各种外部设备。\
随着技术的不断发展，USB的版本也在不断更新。USB 1.0是最早的版本，传输速度很慢，但是随着USB 2.0的推出，传输速度得到了显著提高。USB 3.0和USB 3.1是更快的版本，提供更高的传输速度和更多的功率。同时，USB还可以支持不同的数据传输协议，包括HID（人体接口设备）、音频、视频和存储设备等。\
我们的开发板上有一个USB TYPE-C接口，可以接入TYPE-C接口的HUB。\

#### 6.2在Linux系统上使用USB
实际上常用USB设备都可以直接在这个系统上使用。比如鼠标键盘，都可以直接配合桌面来使用。使用U盘这些存储工具的话则需要注意分区和文件系统格式，可以参考**②M.2**中SSD的分区和格式化方法。U盘接入到系统之后，设备操作文件一般是 */dev/sda1* 、  */dev/sda2* 等等。
#### 6.3使用系统内置的脚本测试U盘
使用 *~/shells_for_testing_peripheral_devices/* 中的 *usb_drive_test.sh* 脚本( *ps：这个系统是不支持NTFS文件系统的，所以NTFS分区的U盘无法直接使用* )：\


---
### ⑦PL_UART
#### 7.1什么是PL_UART
PL_UART区别于PS_UART，是ZYNQMP芯片中FPGA端(也叫做PL端)的UART接口。
#### 7.2在Linux中使用PL_UART
把PL_UART连接到PC(***PC上需要安装CP210x的驱动***)：\
\
打开串口工具，选择对应COM，波特率设置为115200：\
\
**COM的编号取决于你的PC，如果此时你的PS_UART和PL_UART都接在PC上，那么至少能看到两个后缀是*Silicon Labs CP210x USB to UART Bridge* 的COM：**\
\
在开发板的Linux系统中PL_UART设备是 */dev/ttyPS1*，默认波特率是9600，可以用这个命令来设置波特率：\
`stty -F /dev/ttyPS1 ispeed 115200 ospeed 115200 cs8`\
我们把它设置成115200和串口工具的设置对应，然后使用命令：\
`cat /dev/ttyPS1`\
来显示PL_UART收到的数据：\
\
在串口工具中发送一些数据，可以看到系统中收到了这些数据：\
\
在键盘上按*ctrl c*退出*cat /dev/ttyPS1*命令，然后用命令：\
`echo "PL_UART test" > /dev/ttyPS1`\
通过PL_UART发送数据*PL_UART test* 到PC，PC上串口工具可以收到数据：\

#### 7.3使用系统内置的脚本测试PL_UART
把PL_UART连接到USB HUB上：\
\
运行 *~/shells_for_testing_peripheral_devices/* 中的 *pl_uart_to_self_usb_test.sh* 脚本：\
\
输出\"*pl uart to self usb test OK* \"说明PL_UART完好(ps：这个脚本同时也验证了USB接口完好)。

---
### ⑧PS_UART
#### 8.1什么是PS_UART
UART是一种通信协议，全称为“通用异步收发传输器”（Universal Asynchronous Receiver/Transmitter）。它是一种串行通信协议，可以用于在微控制器、传感器、电脑周边设备、通信设备等之间传输数据。\
UART使用两根信号线来进行数据传输：一根是数据线（TX），负责发送数据；另一根是接收线（RX），负责接收数据。UART通信使用异步传输方式，也就是说，通信双方的时钟信号不同步，需要在数据传输中加入起始位、停止位和奇偶校验位来保证数据的正确性。\
UART的主要优点是简单、灵活和广泛使用。由于它是一种通用协议，可以在各种不同的设备之间进行通信，因此在嵌入式系统和通信领域中应用广泛。\
PS_UART是ZYNQMP芯片中ARM端(也叫做PS端)的UART接口。
#### 8.2在Linux中使用PS_UART
PS_UART在我们制作的系统中用于Linux的默认终端窗口，把PS_UART连接到PC(***PC上需要安装CP210x的驱动***)：\
\
用串口工具打开对应的COM，设置波特率设置为115200，关闭流控制，点击OK按钮：\
\
启动开发板后可以看到串口工具中打印信息：\
\
PS_UART在我们制作的Linux系统中的设备是 */dev/ttyPS0* ，使用`echo "PS_UART test" > /dev/ttyPS0`命令可以通过PS_UART接口传输数据：\
\
可以看到串口有回显，但是PS_UART被用于终端窗口，因此不建议对 */dev/ttyPS0* 进行操作。

---
### ⑨EMMC
#### 9.1什么是EMMC
eMMC（Embedded MultiMediaCard）是一种被嵌入式设备广泛采用的存储器件，它将闪存芯片、控制器、主机接口和闪存管理软件集成在一个小型封装中。eMMC的体积小、功耗低、性价比高，是嵌入式设备存储方案中的一种常见选择。\
eMMC主要应用于移动设备（例如智能手机、平板电脑、数字相机等）以及汽车、工业控制等领域的嵌入式设备中。它提供了一种高速、可靠的存储解决方案，支持快速启动和数据读写，可以存储操作系统、应用程序、媒体文件等数据。\
在我们的开发板上集成了一个8G的EMMC。
#### 9.2在Linux系统上使用EMMC
EMMC在Linux系统中的操作文件是 */dev/mmcblk0* ，使用方法和**②M.2**中SSD的使用方法类似：设置分区并格式化分区最后挂载分区。例如：
```
#解挂分区
umount /dev/mmcblk0p1
#删除/dev/mmcblk0的一个分区并新建一个分区
echo "d

n
p
1

w
" | fdisk /dev/mmcblk0
#把/dev/mmcblk0p1分区格式化成ext4格式
echo "y

" | mkfs.ext4 /dev/mmcblk0p1
#挂载/dev/mmcblk0p1到/media/sd-mmcblk0p1
mount /dev/mmcblk0p1 /media/sd-mmcblk0p1
```
挂载之后，就可以在挂载的路径中操作文件了，而这些文件最终都会被保存在EMMC中。
#### 9.3使用系统内置的脚本测试EMMC
运行 *~/shells_for_testing_peripheral_devices/* 中的 *emmc_test.sh* 脚本：\


---
### ⑩EEPROM
#### 10.1什么是EEPROM
EEPROM是一种非易失性存储器（NVM），它是电可擦可编程只读存储器（EPROM）的改进版本。EEPROM可以通过电子信号进行擦除和编程。\
EEPROM通常用于存储小量的数据，例如芯片上的配置信息、产品序列号、加密密钥等。在一些电子设备中，EEPROM还可以用来存储用户设置和个人资料等数据。\
与闪存相比，EEPROM具有更快的读取速度和更高的耐用性，但容量较小。与DRAM相比，EEPROM具有更长的数据保持时间，但写入速度较慢。
#### 10.2在Linux系统上使用EEPROM
eeprom在系统中的操作文件是 */sys/bus/i2c/devices/0-0050/eeprom* 。\
使用命令：\
`echo -e "test e2prom\n" > /sys/bus/i2c/devices/0-0050/eeprom`\
可以往eeprom中写入引号中的数据。\
使用命令：\
`cat /sys/bus/i2c/devices/0-0050/eeprom`\
可以查看eeprom中的内容。\

#### 10.3使用系统内置的脚本测试EEPROM
运行 *~/shells_for_testing_peripheral_devices/* 中的 *eeprom_test.sh* 脚本：\


---
### ⑪QSPI FLASH
#### 11.1什么是QSPI FLASH
Flash是一种高速闪存存储器，常用于嵌入式系统和其他应用中，用于存储程序代码、配置数据和其他信息。\
QSPI Flash是一种基于SPI接口的闪存芯片，它通过四个并行数据线（quad interface）进行通信，与传统的SPI Flash相比，可以实现更快的数据传输速度，通常达到几十MHz的传输速度。QSPI Flash的容量通常在几兆字节到几十兆字节之间。\
QSPI Flash具有许多优点，包括快速读写速度、低功耗、可擦写性、易于集成和使用等。此外，它还可以通过软件进行编程和擦除，而无需任何外部设备或信号线。
#### 11.2在Linux系统上使用QSPI FLASH
在当前的Linux系统中QSPI FLASH被用于存储u-boot的环境变量，如果修改了u-boot的环境变量那么操作QSPI FLASH就需要小心了。\
QSPI FLASH在系统中的操作文件是 */dev/mtd0*。\
FLASH设备在写之前需要先擦，使用下面的命令可以擦除QSPI FLASH的第一个扇区：\
`flash_erase /dev/mtd0 0 1`\
*/dev/mtd0* 是块设备，可以用**dd**命令来读写文件到 */dev/mtd0*。\
用下面的命令写文件到 */dev/mtd0* ：
```
touch /home/root/.qspiflashwrite
echo "qspiflash test" > /home/root/.qspiflashwrite
dd of=/dev/mtd0 if=/home/root/.qspiflashwrite bs=4096 count=1
```
用下面的命令从 */dev/mtd0* 读取数据到文件：
```
touch /home/root/.qspiflashread
dd if=/dev/mtd0 of=/home/root/.qspiflashread  bs=4096 count=1
```
#### 11.3使用系统内置的脚本测试QSPI FLASH
运行 *~/shells_for_testing_peripheral_devices/* 中的 *qspi_flash_test.sh* 脚本：\


---
### ⑫RTC
#### 12.1什么是RTC
实时时钟(RTC)单元为整个系统和应用软件提供了一个精确的时间基准。
#### 12.2在Linux系统上使用RTC
在我们的Linux系统中，RTC的设备操作文件是 */dev/rtc0*。可以用**hwclock**命令来读写 */dev/rtc0*。例如：
```
#设置系统时间为"2023-03-01 10:30:00"
date --set="2023-03-01 10:30:00"
#把系统时间写入到/dev/rtc0
hwclock -f /dev/rtc0 -w
#用/dev/rtc0中的时间更新系统时间
hwclock -f /dev/rtc0 -r
```

#### 12.3使用系统内置的脚本测试RTC
运行 *~/shells_for_testing_peripheral_devices/* 中的 *ds1308_test.sh* 脚本：\


---
### ⑬LM75
#### 13.1什么是LM75
LM75是一种数字温度传感器芯片，由德州仪器（Texas Instruments）公司生产。它可以测量环境温度，并通过I2C总线与其他设备进行通信。是一个性能稳定、精度高、可靠性好的数字温度传感器芯片。
#### 13.2在Linux系统上使用LM75
在Linux中直接读取 */sys/bus/i2c/devices/0-0048/hwmon/hwmon0/temp1_input* 就可以获取到LM75采集的温度值，**单位是m°C**：\
`cat /sys/bus/i2c/devices/0-0048/hwmon/hwmon0/temp1_input`\
\
这里读到的温度是30625m°C，也就是30.625°C。

---
---
- 访问[ALINX官方网站](https://www.alinx.com)以获取更多信息。

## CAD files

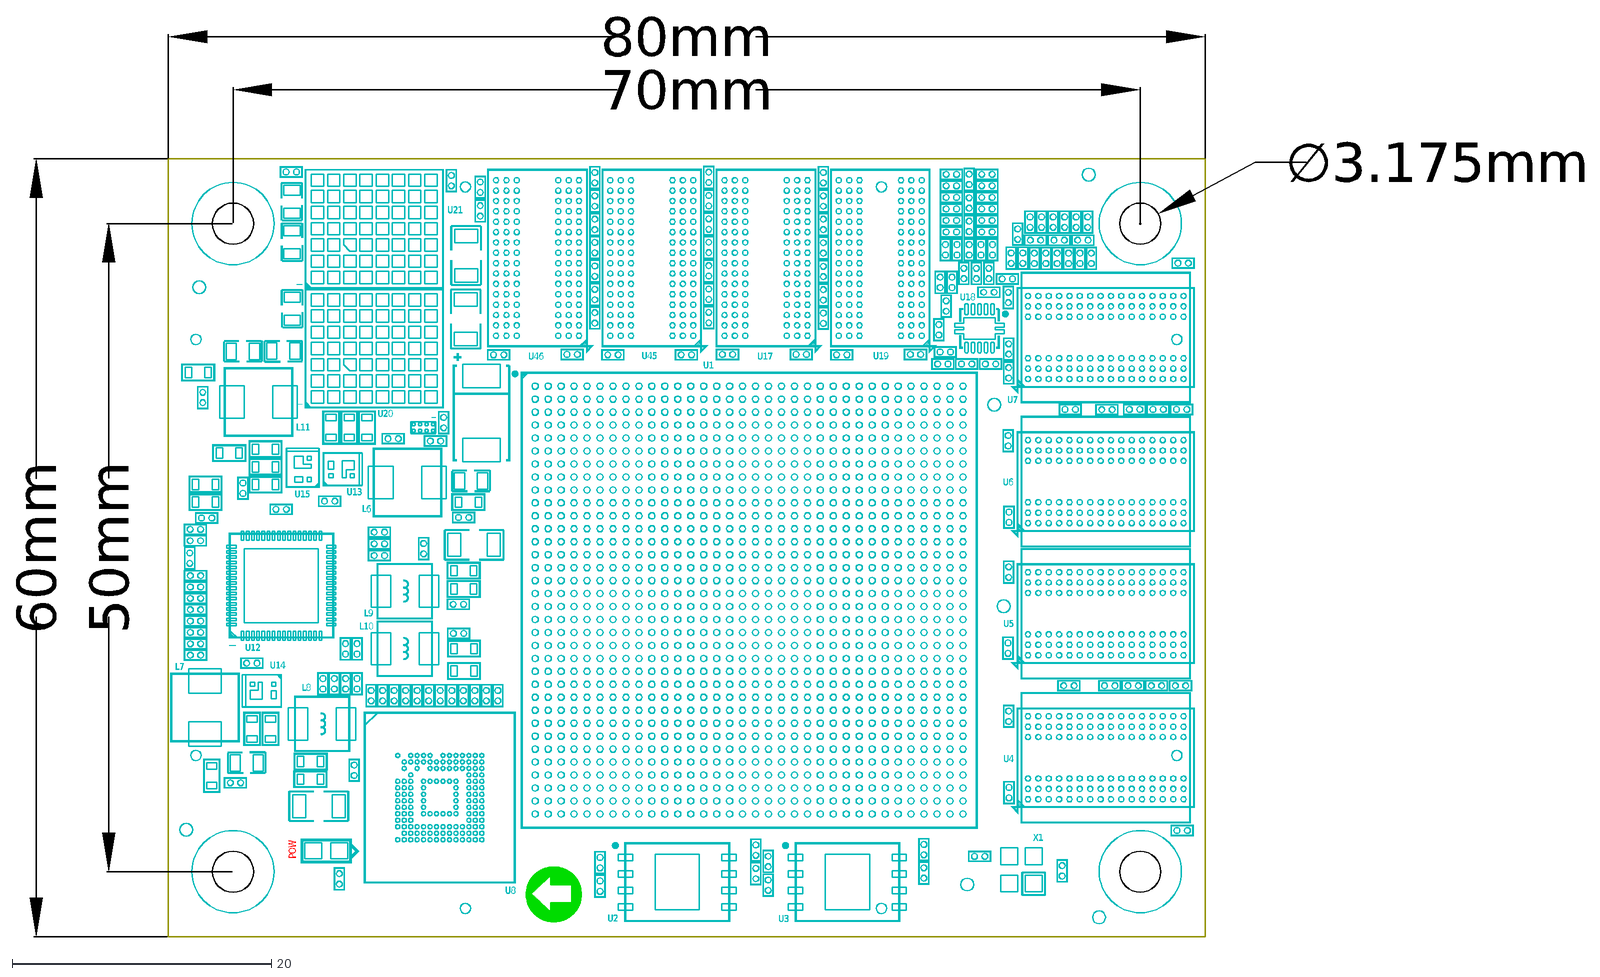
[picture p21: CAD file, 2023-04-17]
hardware/STEP_Models/ACU7EV_size_structure.dxf
U4
U5
U6
U7
U12
U18
U17
U19
U45
U46
U1
U14
U15
U13
U21
U20
L9
L8
L10
U8
L11
L6
L7
U2
U3
X1
POW
70mm
80mm
60mm
50mm
∅3.175mm

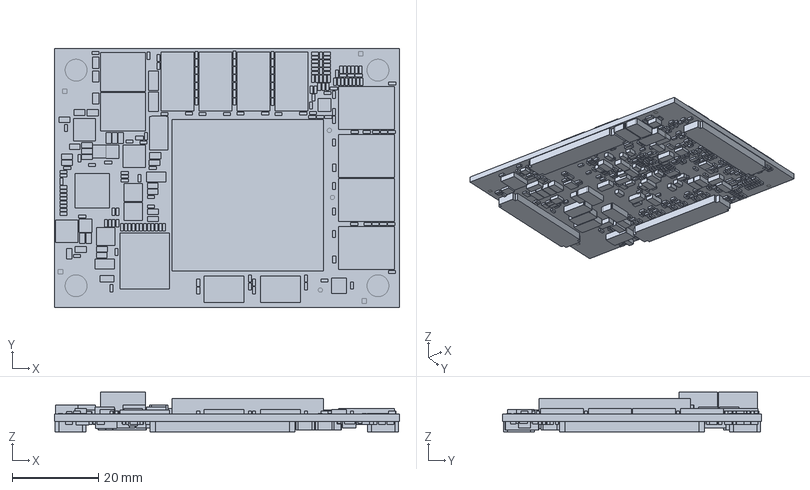
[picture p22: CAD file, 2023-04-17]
hardware/STEP_Models/ACU7EV.stp
80.0 x 60.0 x 9.16 mm
BOARD_OUTLINE
D7343 x 10
DCU_PDSO-G8
USIL-8
FFVC1156
L5_2X5_2 x 3
LED_0805
OSC3_2X2_5
MLP8 x 2
MT40A256M16GE-075E x 4
MT40A1G16RC-062E x 4
CC0805 x 23
SOT23-3
TP x 3
R0402 x 3
VQFN64
VSON-10 x 2
TPS51200DRCR
L0603 x 3
AXK5A2137YG x 4
CSD87381P x 3
8S1_SOIC8
MARK x 8
MH_250H125 x 4
SOT23-5
RR0402 x 166
CC0402 x 289
MYMGM1R824ELA5RP x 2
C1206
OSC6-3225
6-TDFN-EP
DSBGA8
SX2-3215
L4_2X4_2 x 3
VFBGA_13X11_5
CC1206 x 28
CC0603 x 41
LL0603 x 3

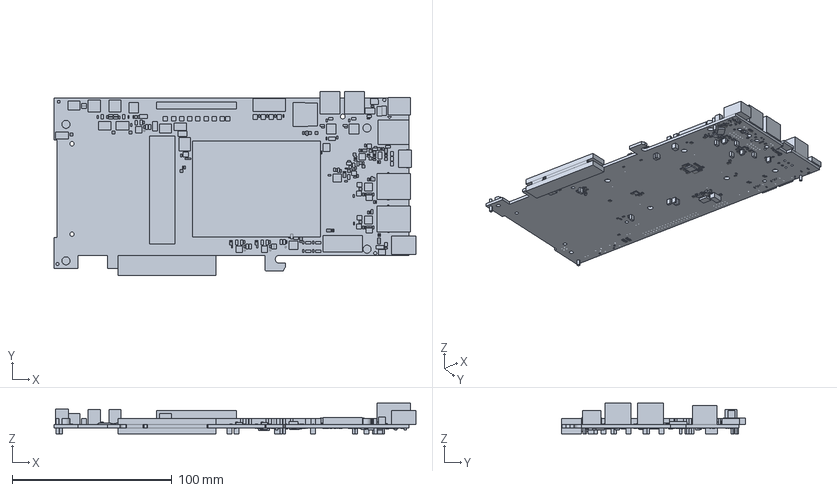
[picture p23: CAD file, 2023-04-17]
hardware/STEP_Models/Z7-P.stp
226.5 x 115.4 x 19.3 mm
BOARD
WTB-2P_1_25
R0603 x 4
SMA_P x 2
KEY_4X4X1_5 x 2
LVS303010 x 2
QFN40-5X5 x 2
OSC3225 x 3
WLCSP12
QFN24-050-4X4-H2R7
TYPE-C-24P-0_5
WQFN30
MARK1_5
L0603 x 15
OSC6-3225
C0603 x 13
C0805 x 33
DRL4_22X6_2 x 2
4P4_1_27MM
FCTSOT23-6
MARK x 4
L5_4X5_2
R1210
D7343
L4_4X4_2 x 3
XH2-2_54_WHITE x 2
SOT-223
TS-026-3_3D8
LED_D3_WX2
RN-8P x 11
IDC-40J
CON_MOL_5569_6P
H2X1
ASP_134486_MAIN_FEMALE_S
JTAG-10
PVQFN-N16
QFN-28 x 2
BAS16XV2T1G x 2
MDT420M02001_PCIE
C0402 x 168
LED_0805 x 6
R0402 x 174
QFN24_RTW
GE_RJ45 x 2
MH_250H125 x 2
MICRO_SD
MICRO8
SOT23-6 x 9
8S1_SOIC8
SON10 x 4
TSSOP8 x 2
R0805 x 3
SOT23-3 x 6
MINI_USB_DIP x 2
AXK6A2337YG x 4
DO-214AC x 5
QFN40
USB3320C
MINI_DP_LC
TSSOP_14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

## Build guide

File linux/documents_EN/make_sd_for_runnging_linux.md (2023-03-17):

[Back to Home](../)
## Start the linux on the development board from the SD card

---
### 1.Adjust the dial switch
Adjust the dial switch on the development board to the state of starting from the SD card, as shown below:\
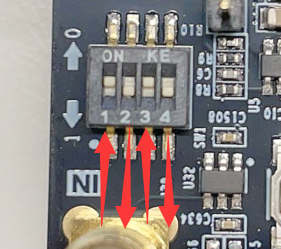
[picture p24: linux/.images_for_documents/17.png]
\
This position of the dial -dial switch is in the development board:\
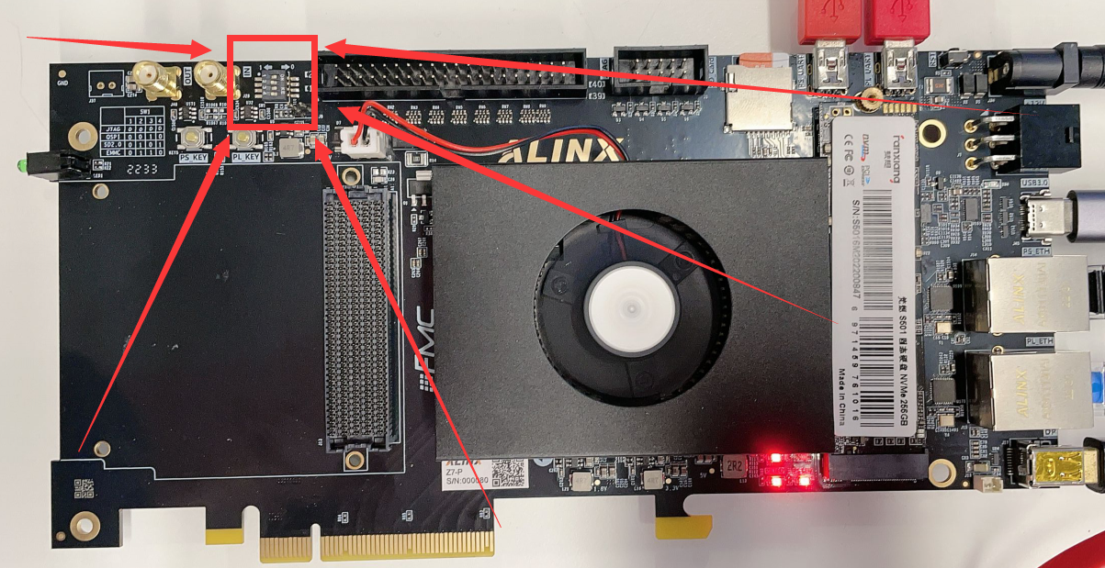
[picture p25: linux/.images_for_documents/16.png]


---
### 2.Set SD card partition
Next, you need to make the SD card for launching Linux. Connect the SD card (such as a card reader) to the Ubuntu system, and then open the DISKS tool in the Ubuntu system:\
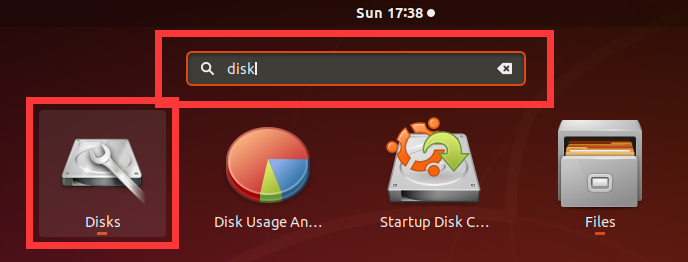
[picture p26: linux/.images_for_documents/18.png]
\
My SD card is the **31 GB Drive** here. Select it, you can see that there are three areas in the SD card:\
a. FAT type partition named **BOOT**\
b. Ext4 type partition named **ROOTFS**\
c. Free Space\
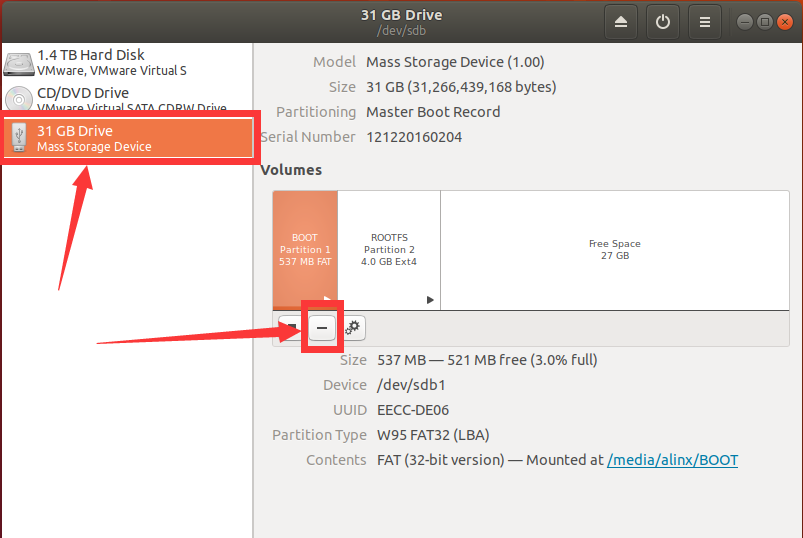
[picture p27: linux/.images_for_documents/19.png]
\
This is the state we need. If your SD card is in the same state (there is no strict requirement on the size of the partition), just skip step [2]. However, in order to demonstrate a complete process, I will restore the SD to the state without partition, select the corresponding partition, click the \" **-** \" icon to delete the current partition, and finally change to the state as shown below:\
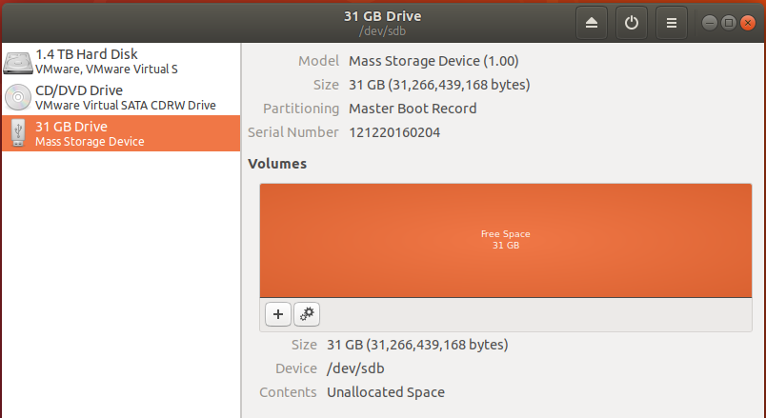
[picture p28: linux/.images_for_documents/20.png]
\
Click the \" **+** \" icon to create a new partition. The first partition needs to be in the format of **FAT**, with a size of 2G and a name of **BOOT**:\
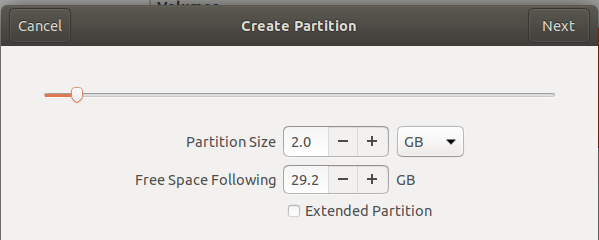
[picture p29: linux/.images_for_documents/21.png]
\
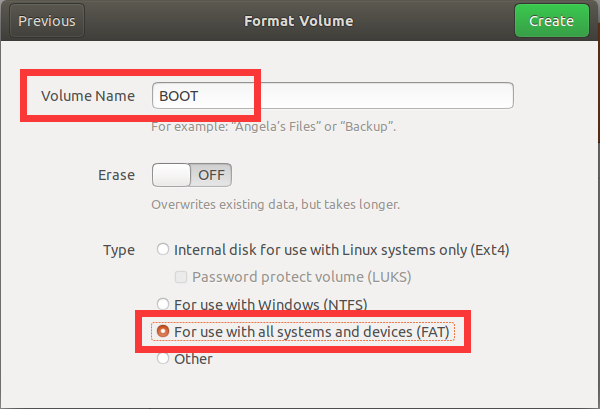
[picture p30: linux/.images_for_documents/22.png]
\
Click the **Create** button to complete the partition creation, and click \" **▶** \" button mount partition:\
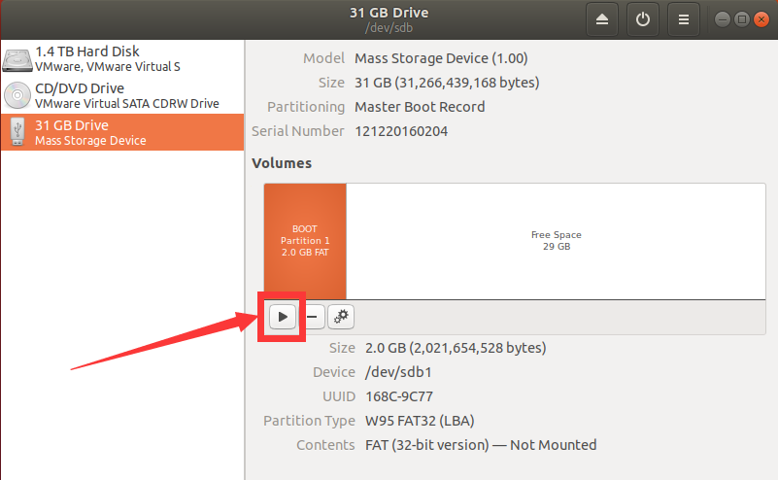
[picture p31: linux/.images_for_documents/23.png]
\
Click **Free Space** to create a second partition using similar steps. Select **Ext4** as the format. The size allocation is 20G (adjusted according to your actual needs and restrictions). The name is **ROOTFS**:\
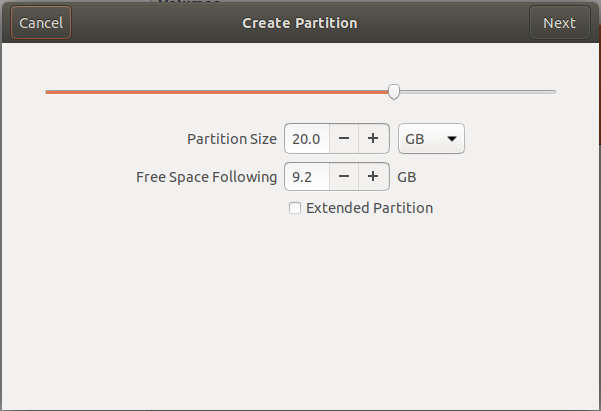
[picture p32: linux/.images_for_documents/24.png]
\
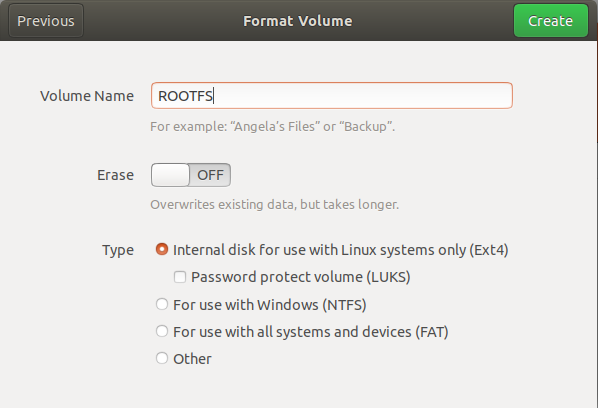
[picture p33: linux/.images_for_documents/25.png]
\
The final status is shown in the following figure. Note that you need to mount both partitions:\
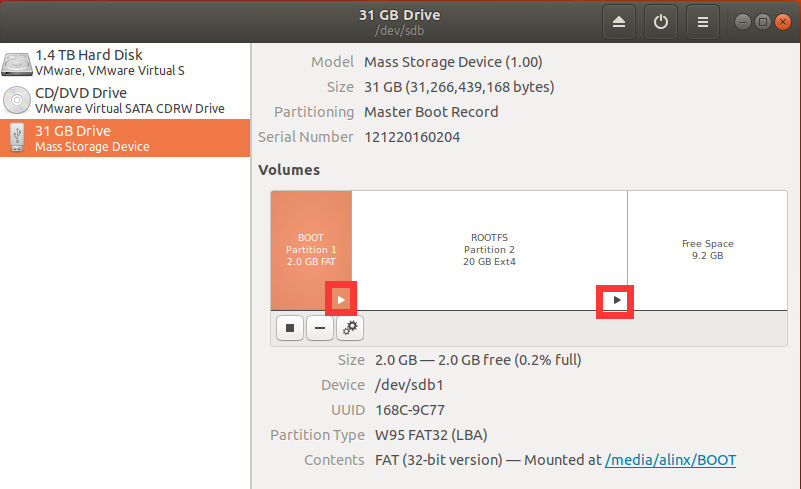
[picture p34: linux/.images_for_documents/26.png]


---
### 3.Populate SD card partitions
After the partition of the SD card is completed, copy the files needed to start the system to the corresponding partition.\
Ps: You can find *boot. scr*, *BOOT. bin*, *image. ub*, *rootfs. tar. gz*  in the release version. You can also compile the petalinux project to obtain these files.\
Copy the *boot.scr*, *BOOT.bin*, and *image.ub* files to the **BOOT** partition:\
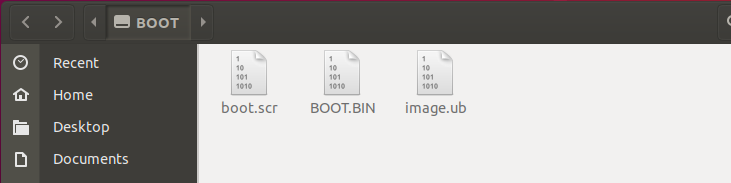
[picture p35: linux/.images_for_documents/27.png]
\
Extract *rootfs.tar.gz* to the **ROOTFS** partition with root privileges, open the terminal in the path of *rootfs.tar.gz*, and enter the following command:\
`sudo tar zxvf ./rootfs.tar.gz -C /media/alinx/ROOTFS/ && sync`\
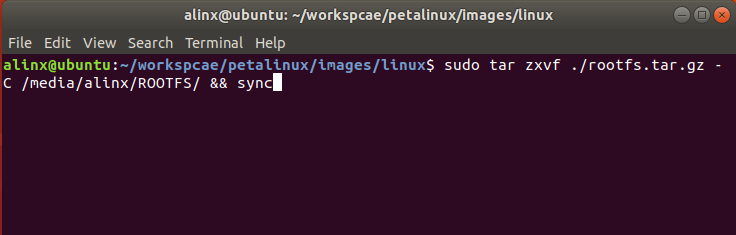
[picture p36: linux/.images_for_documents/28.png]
\
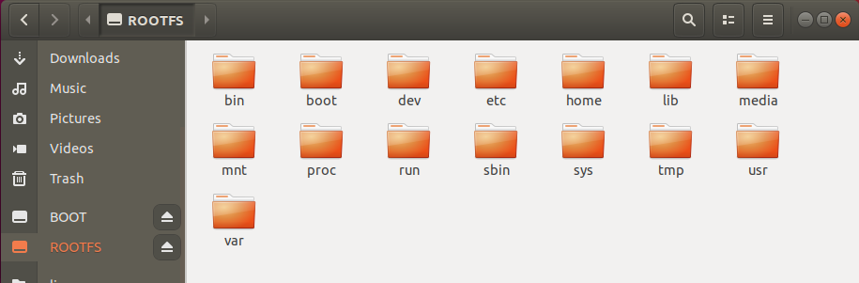
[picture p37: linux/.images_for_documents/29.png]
\
Then eject the SD card from Ubuntu.

---
### 4.Start Linux
Insert the SD card just made into the SD card slot of the development board:\
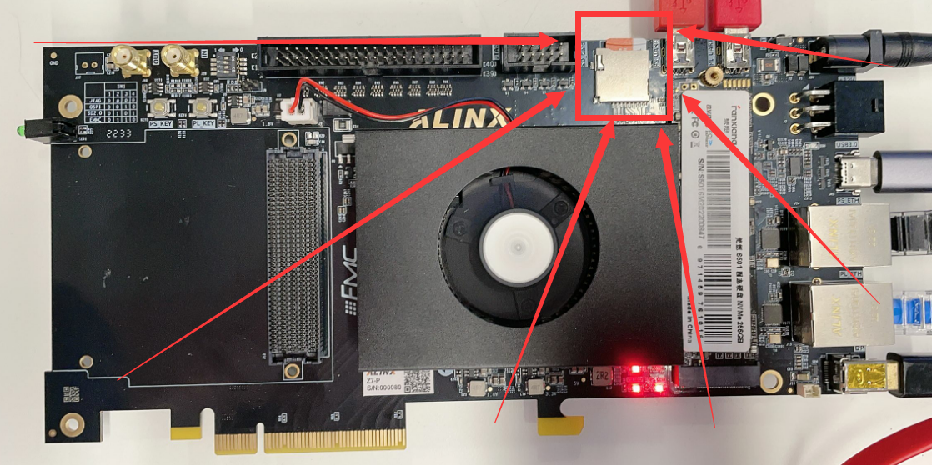
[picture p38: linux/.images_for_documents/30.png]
\
Connect PS_UART to PC (***The driver of CP210x needs to be installed on the PC*** ):\
\
Open the serial port tool, select the COM port we just connected, set the baud rate to 115200, close the flow control, and click the OK button:\
\
Connect 12V power supply:\
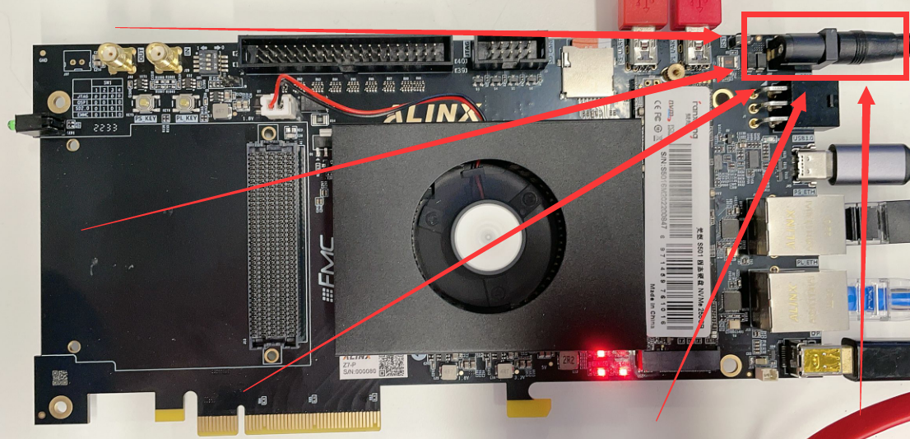
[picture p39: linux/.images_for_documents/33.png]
\
You can see the output information in the serial port tool:\
\
The system has been started successfully. Enter the user name **root** and password **root** to log in to the system.

---
---
- Visit [ALINX official website](https://www.alinx.com) for more information.

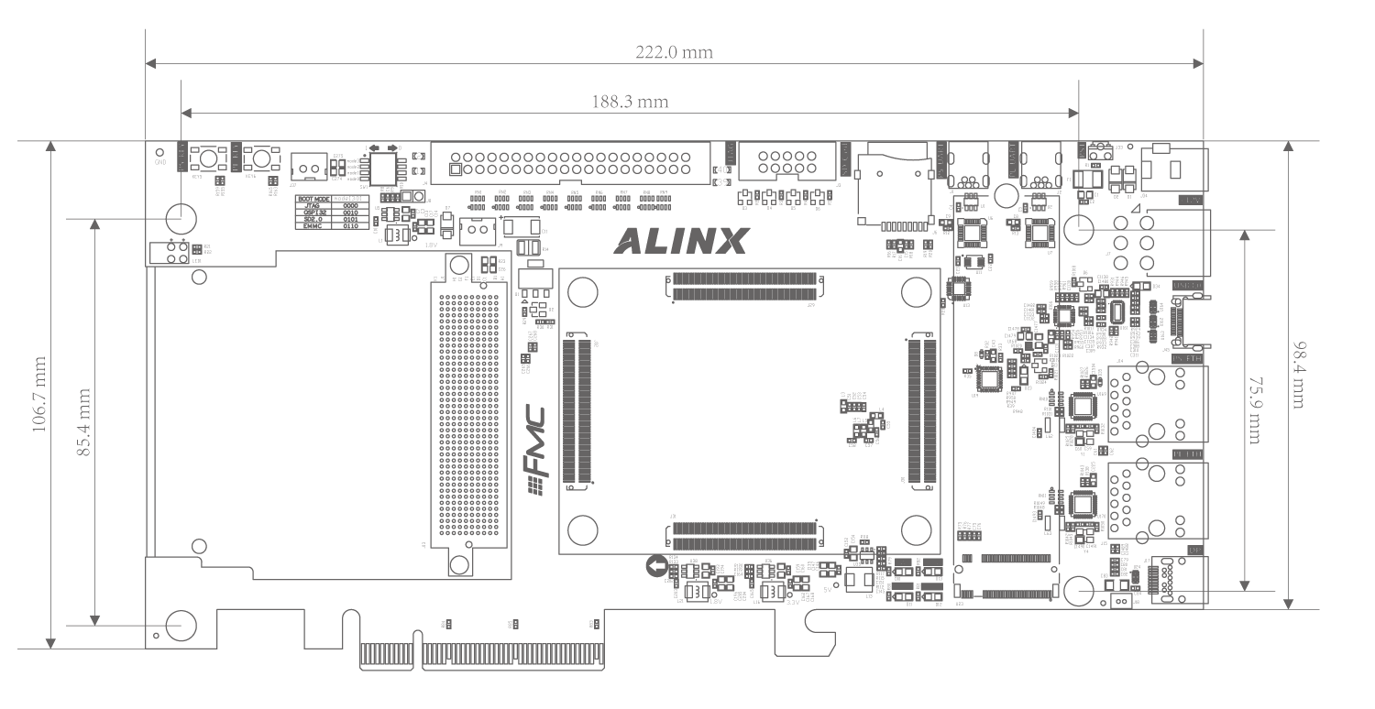
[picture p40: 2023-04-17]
hardware/STEP_Models/Z7-P_size_structure.png

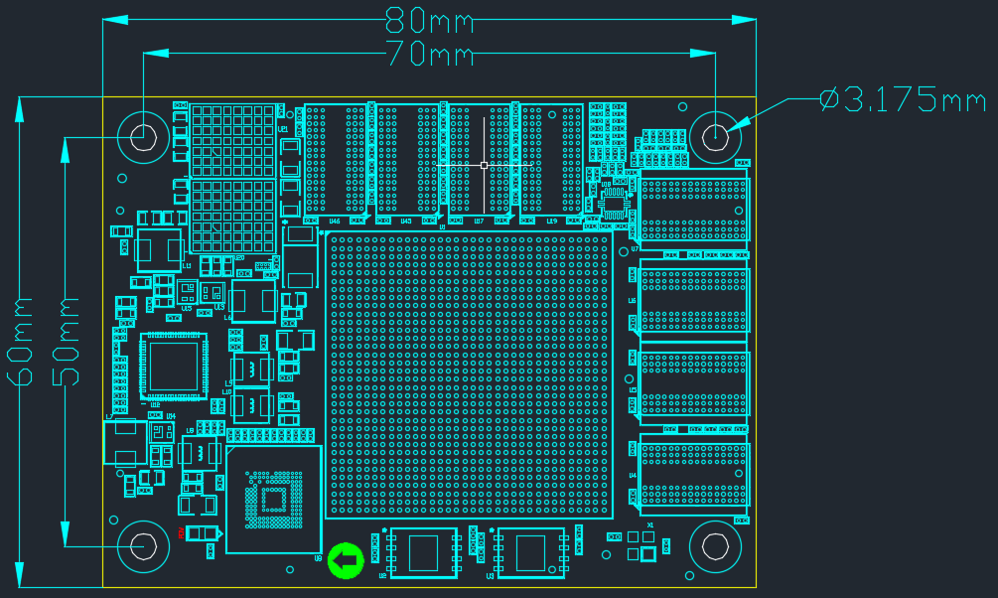
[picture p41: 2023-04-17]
hardware/STEP_Models/ACU7EV_size_structure.png

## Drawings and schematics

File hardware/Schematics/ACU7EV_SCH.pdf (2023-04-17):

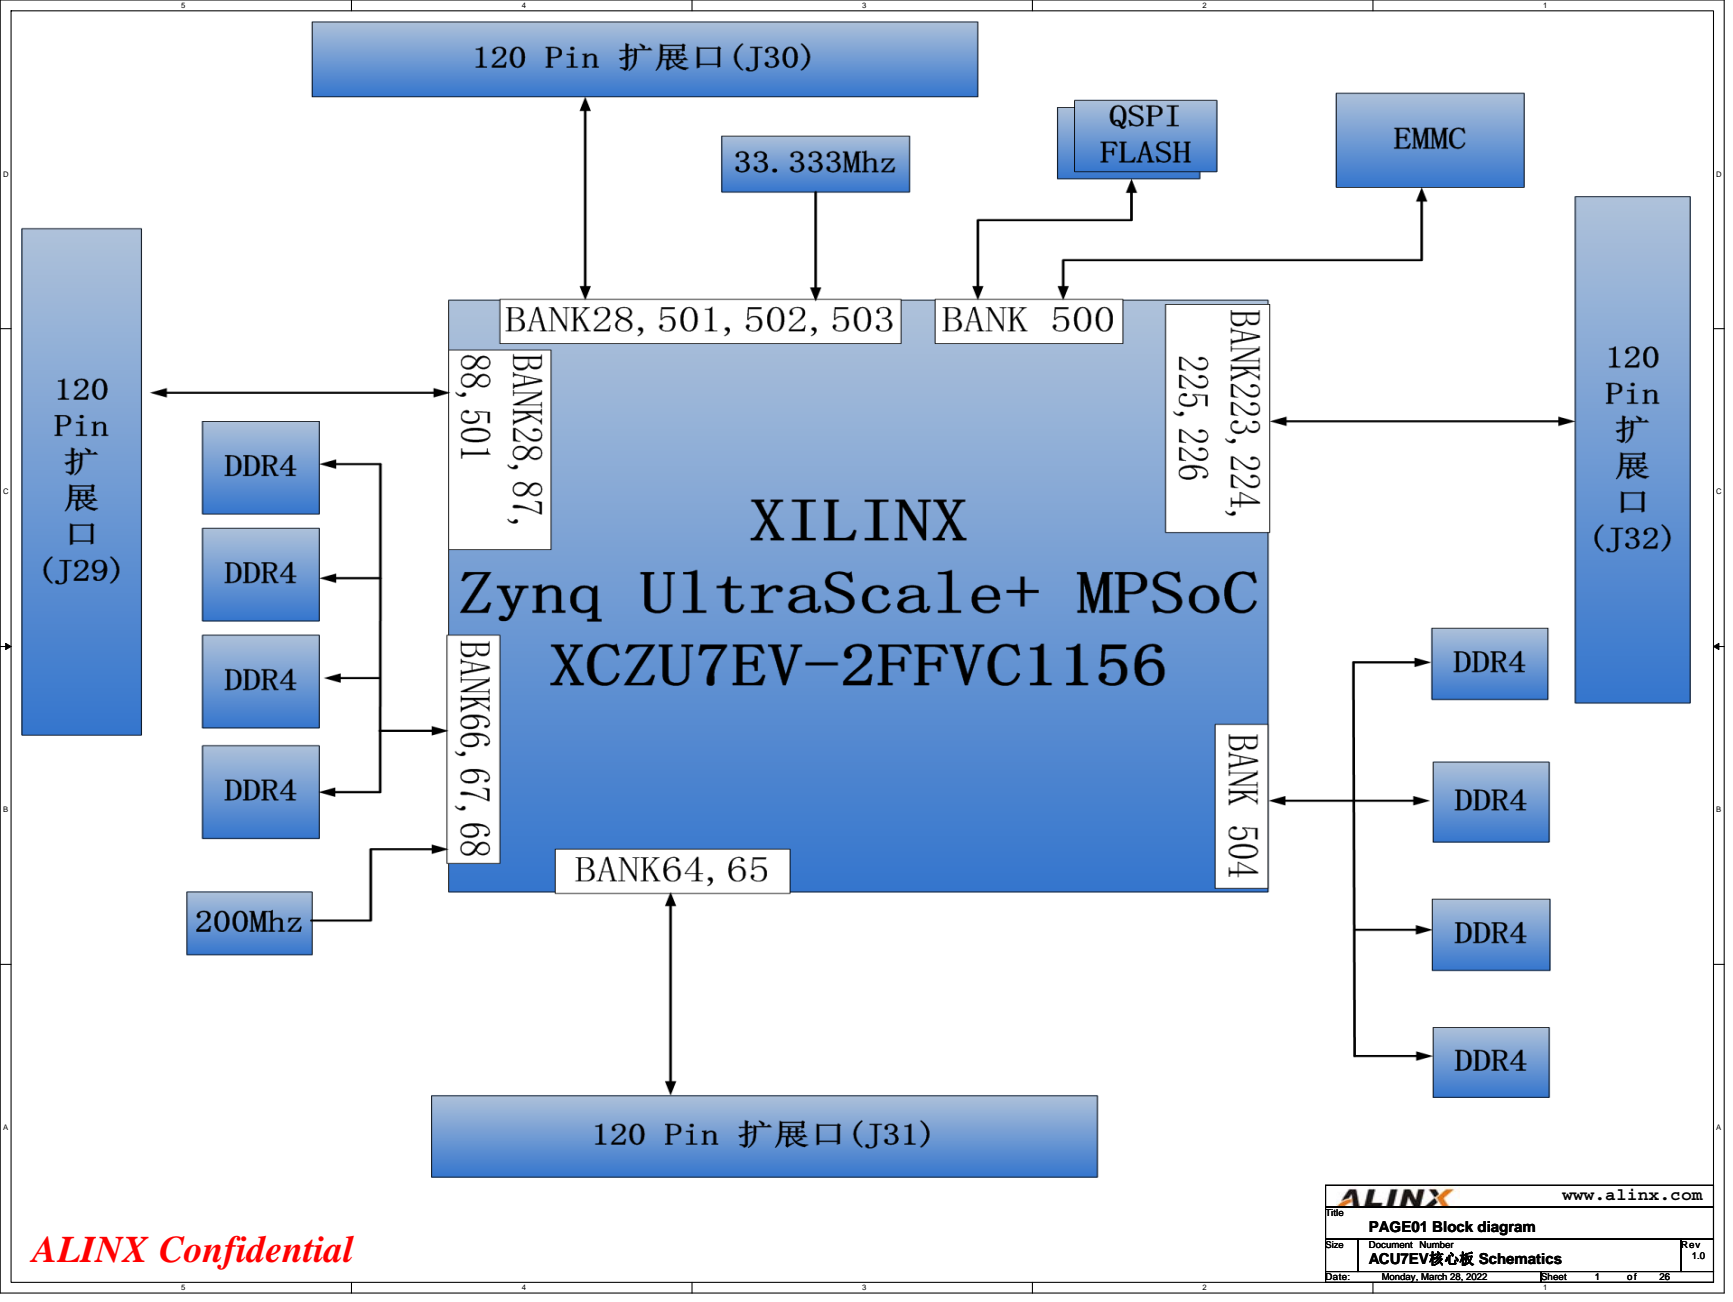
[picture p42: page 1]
ALINX Confidential; Title; PAGE01 Block diagram

www.alinx.com

Size | Document Number ACU7EV核心板 Schematics | Rev 1.0

Date: Monday, March 28, 2022 Monday, March 28, 2022 Monday, March 28, 2022 | Sheet 1 1 1 of 26 26 26

# MODE[3:0]

0000 | PS JTAG | PS JTAG Interface

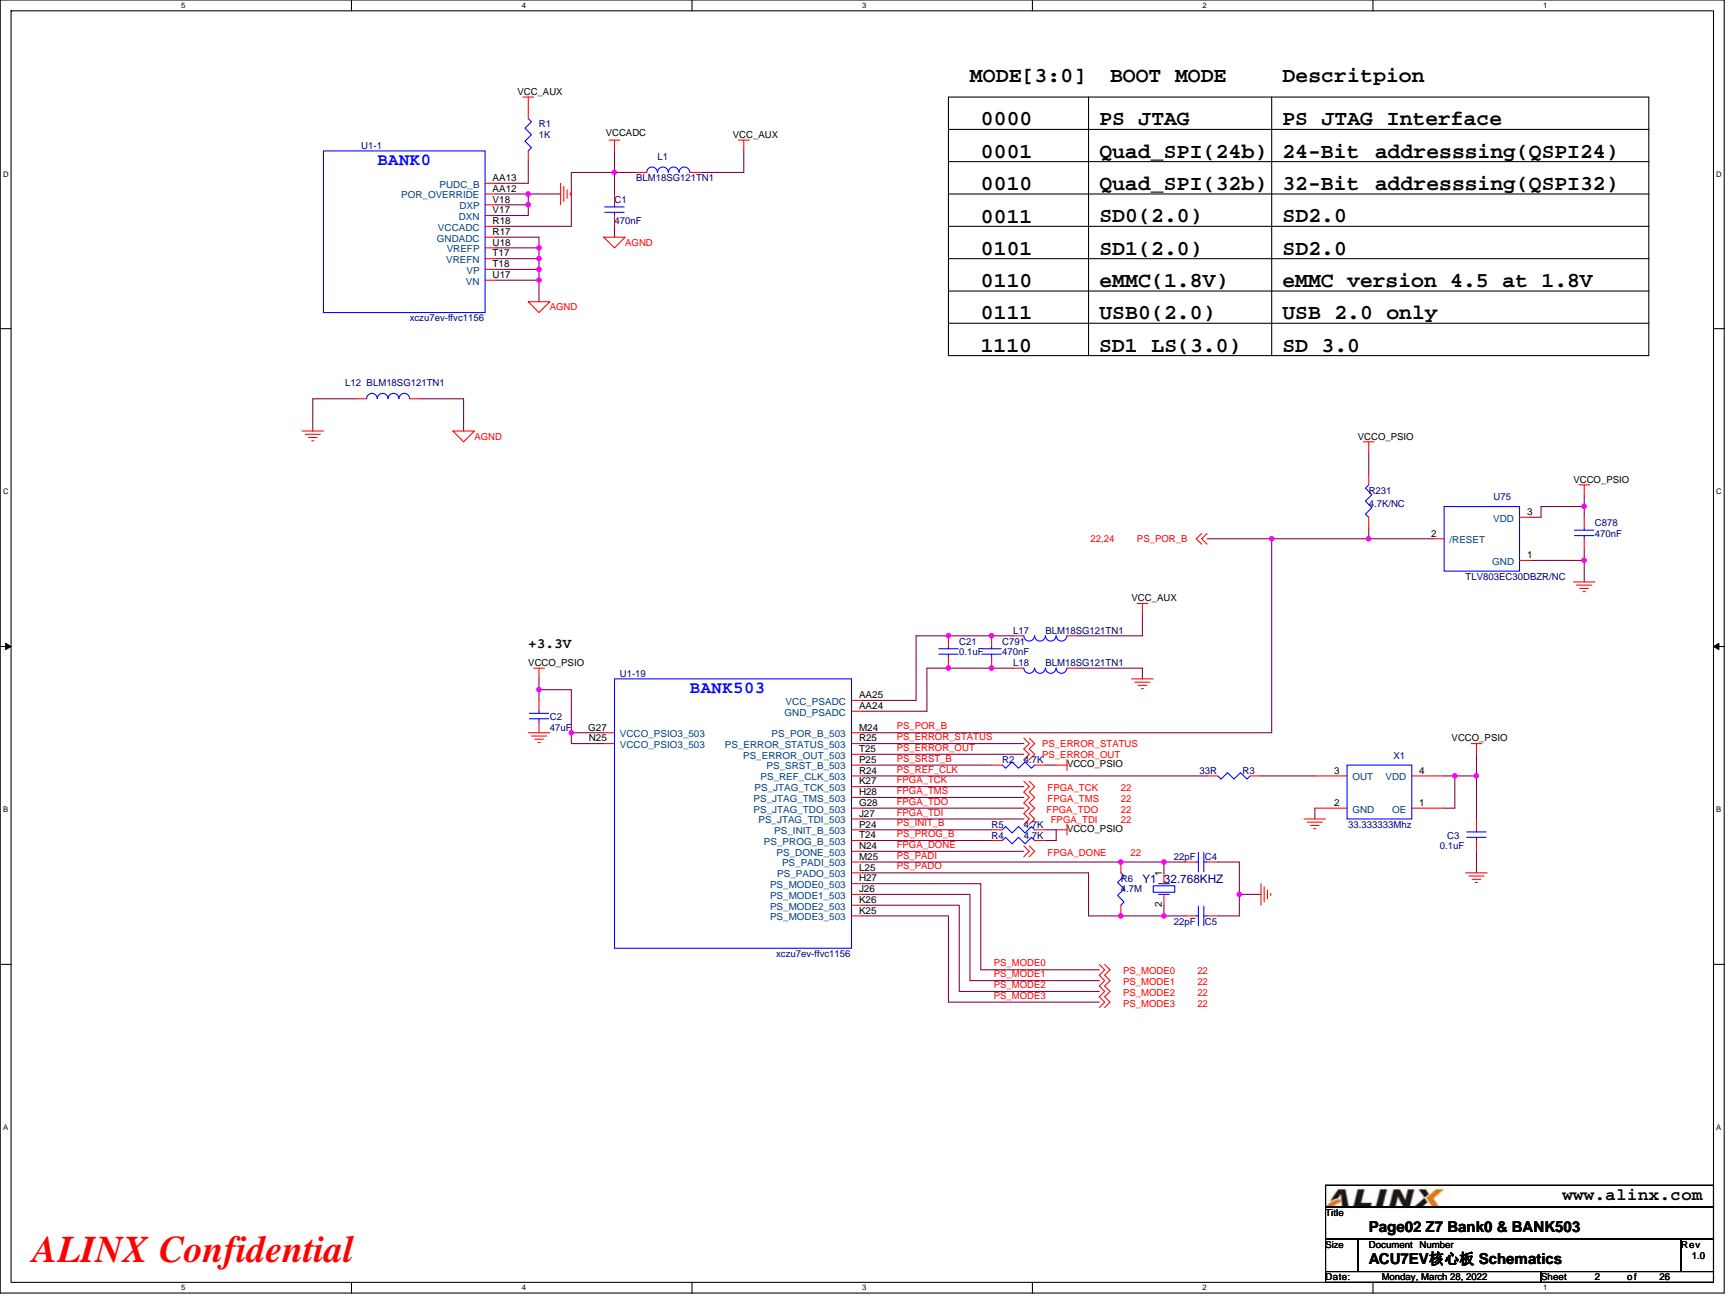
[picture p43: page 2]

0001 | Quad_SPI(24b) | 24-Bit addresssing(QSPI24)
0010 | Quad_SPI(32b) | 32-Bit addresssing(QSPI32)

0101 | SD1(2.0) | SD2.0
0110 | eMMC(1.8V) | eMMC version 4.5 at 1.8V
0111 | USB0(2.0) | USB 2.0 only
1110 | SD1 LS(3.0) | SD 3.0

100uF | BANK500

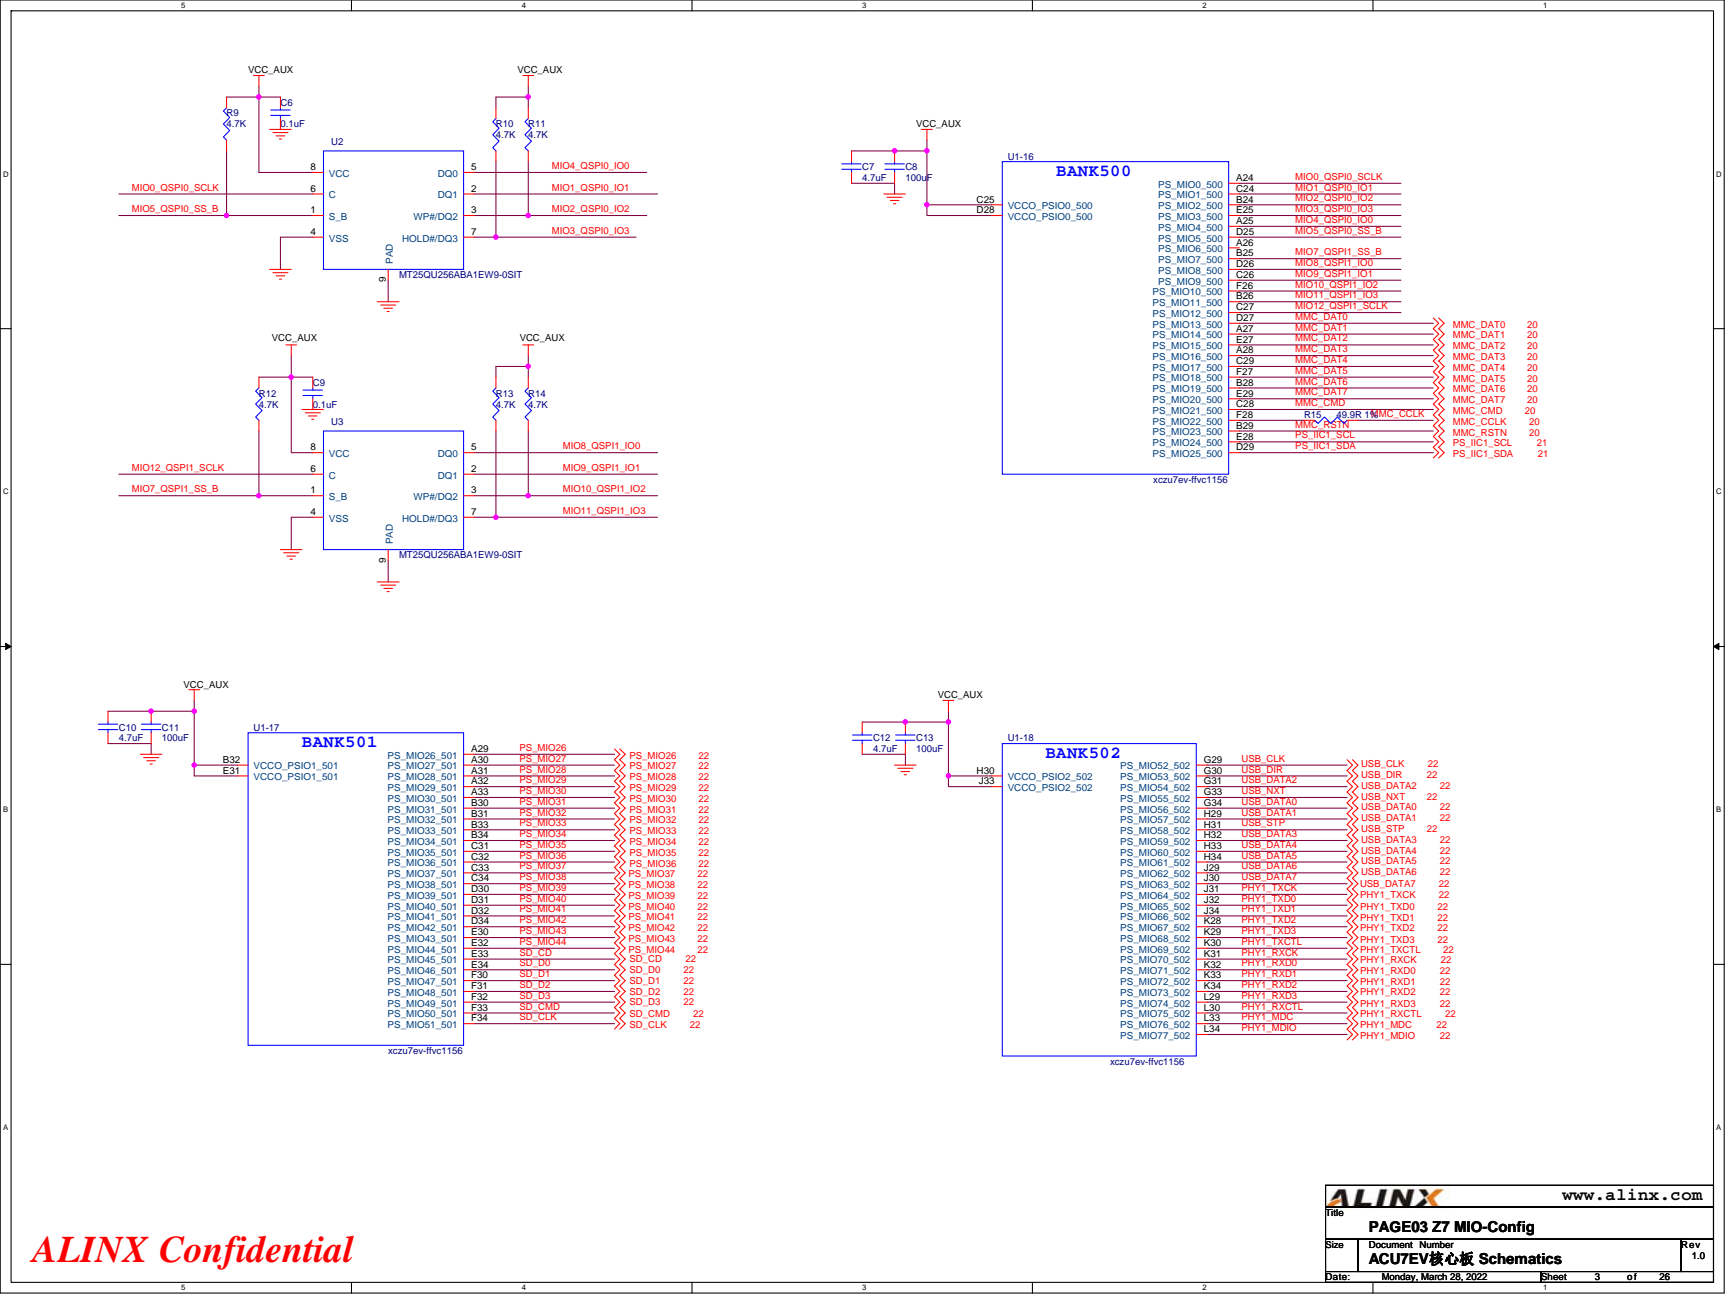
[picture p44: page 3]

# BANK88

# BANK87

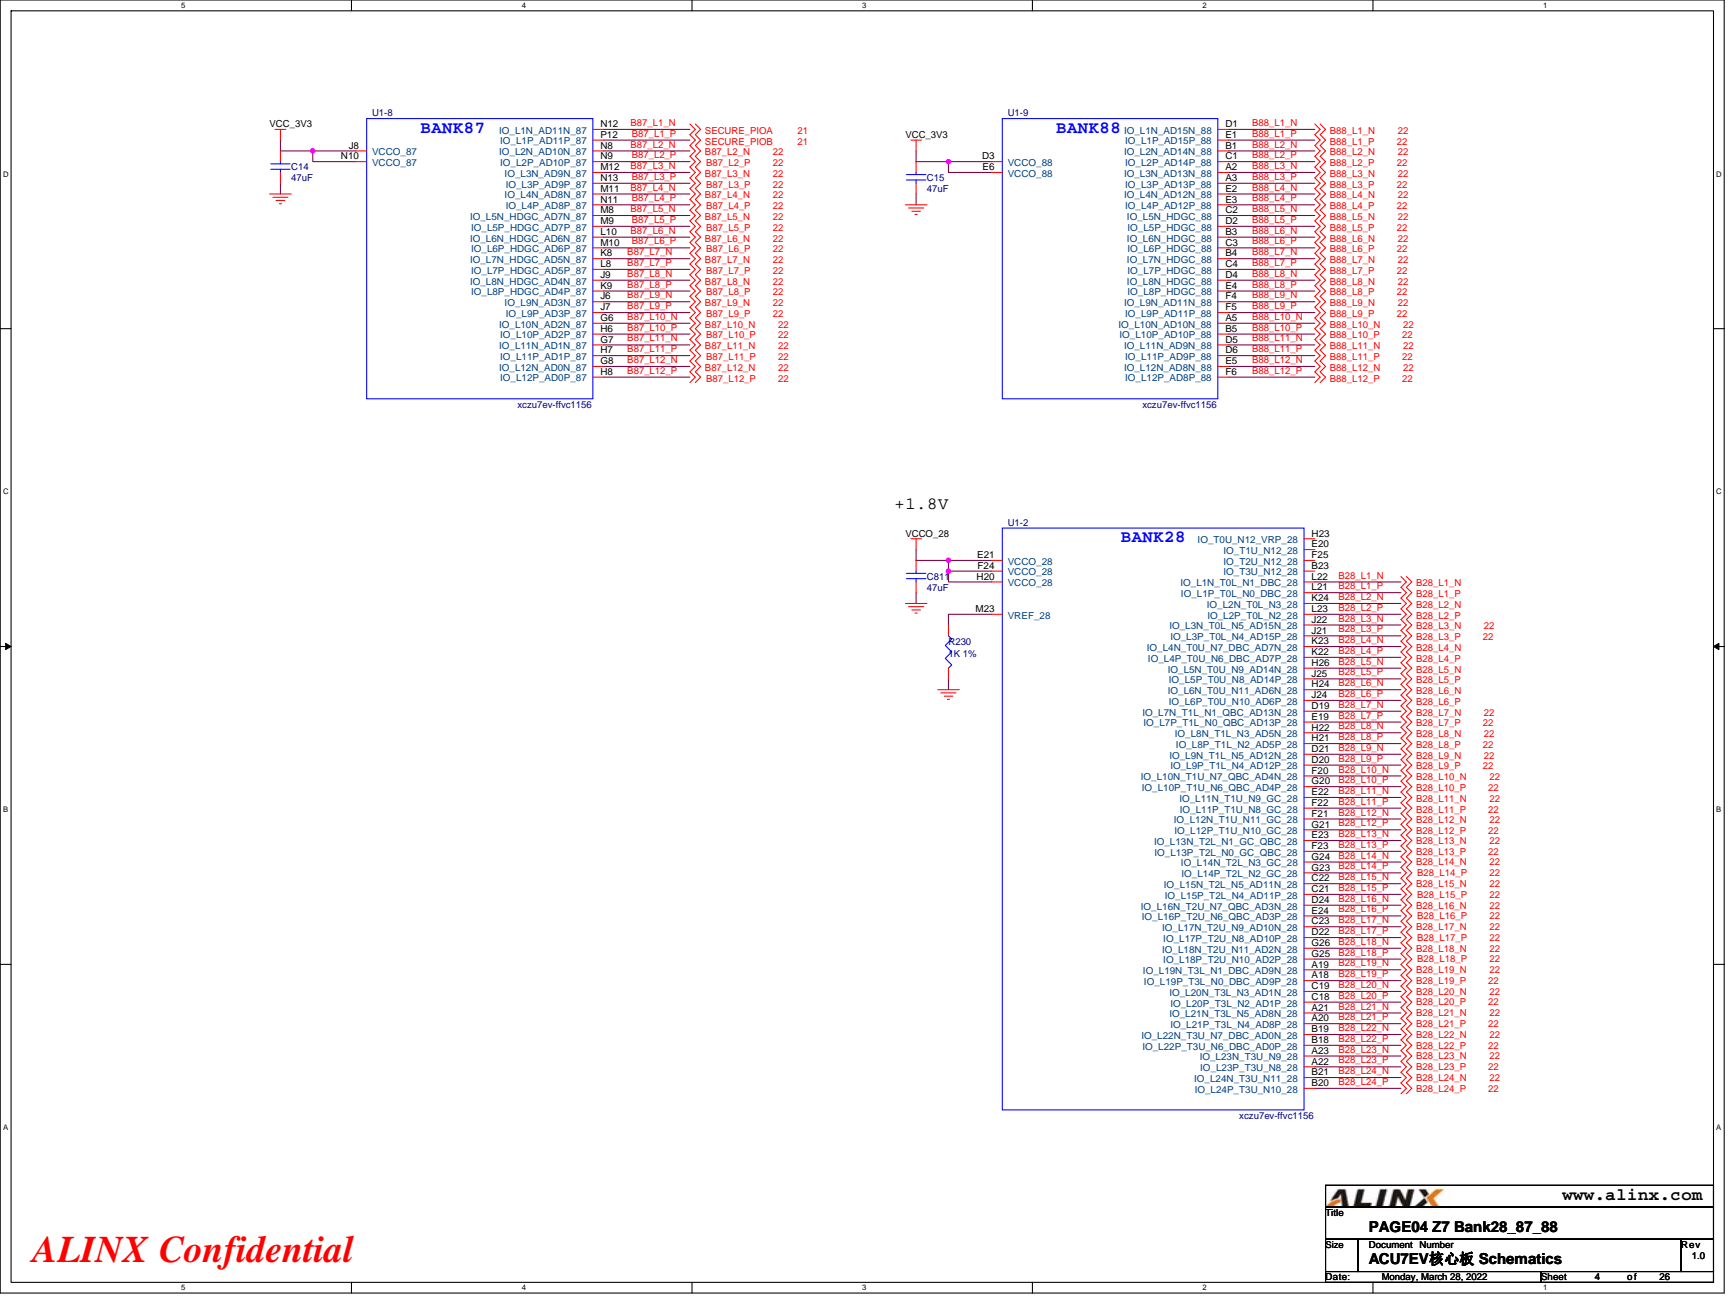
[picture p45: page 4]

# BANK68

# BANK67

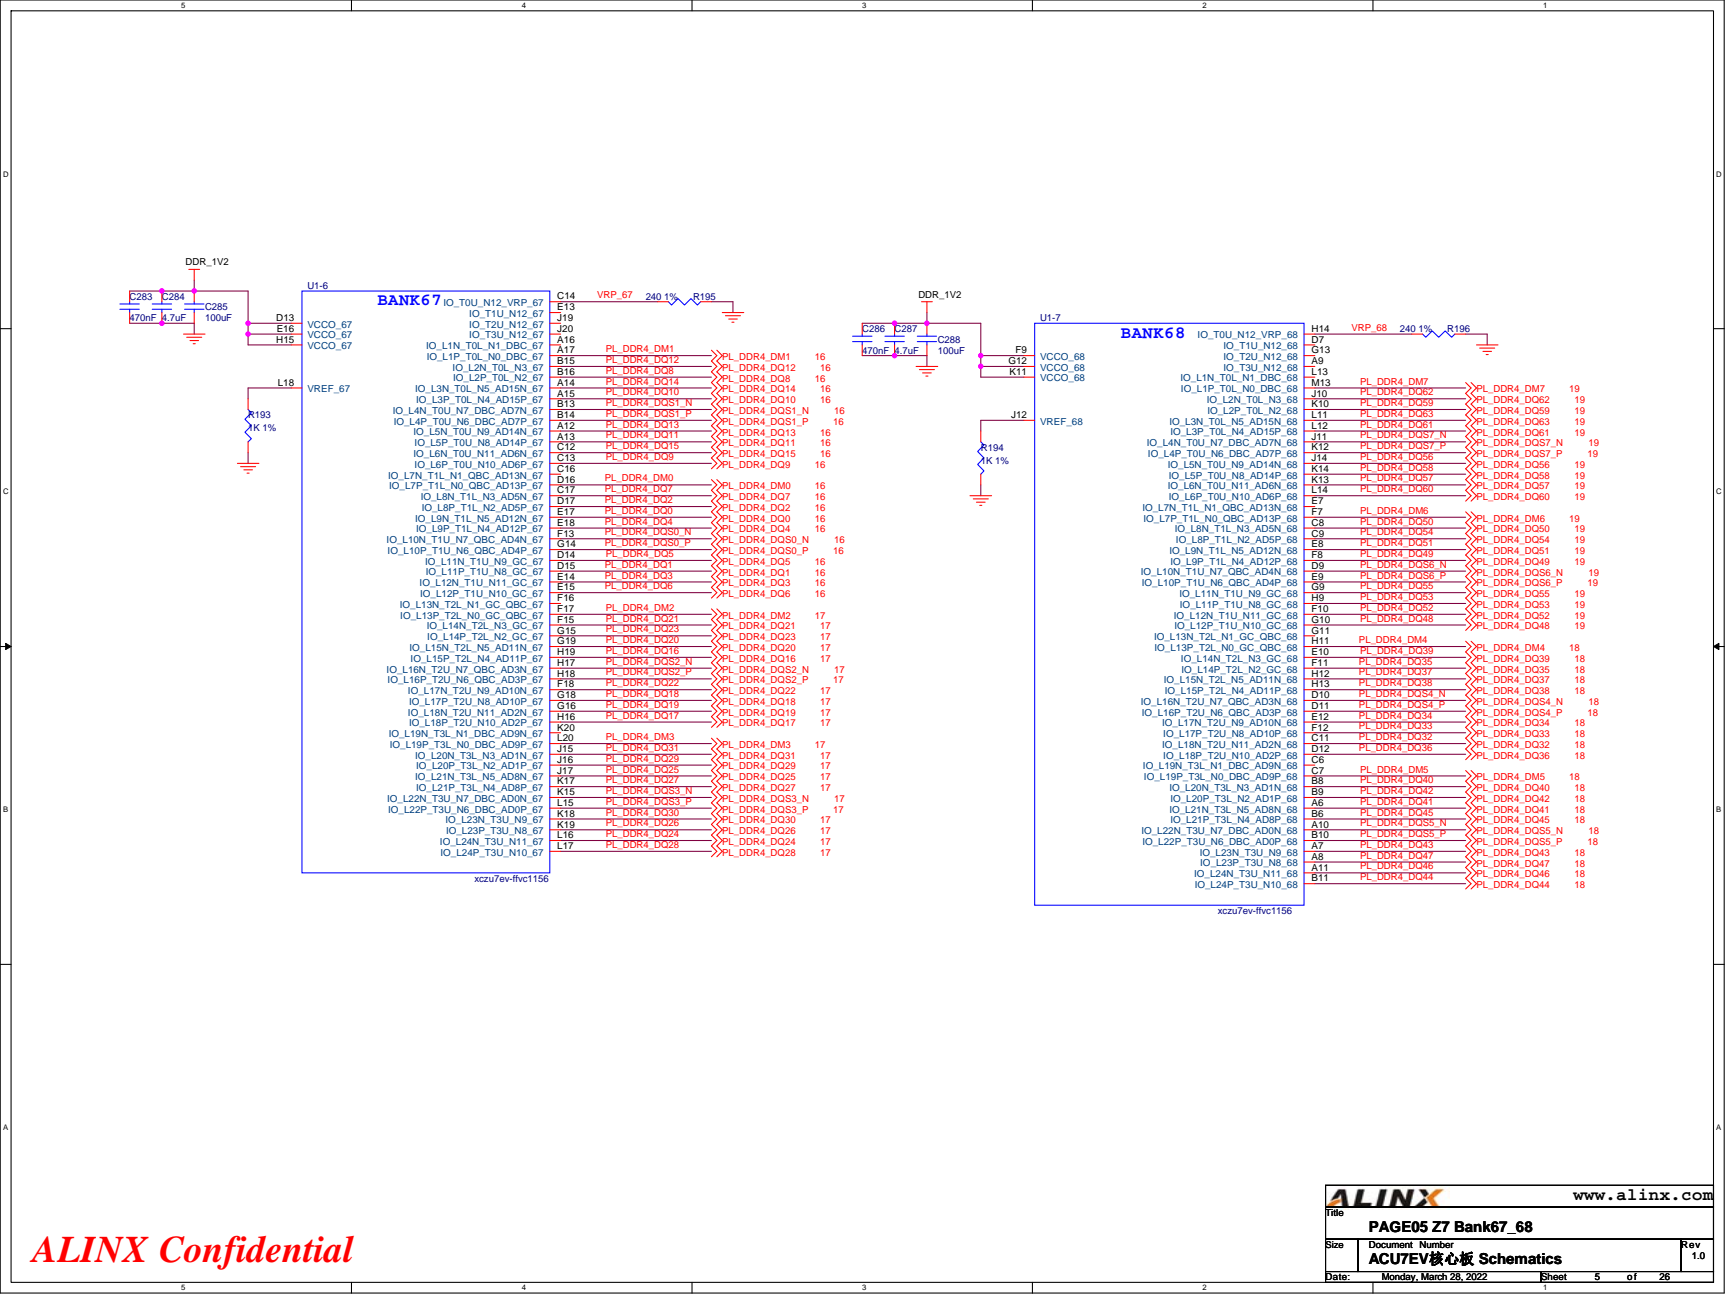
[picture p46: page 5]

+1.8V | +1.8V

# BANK64

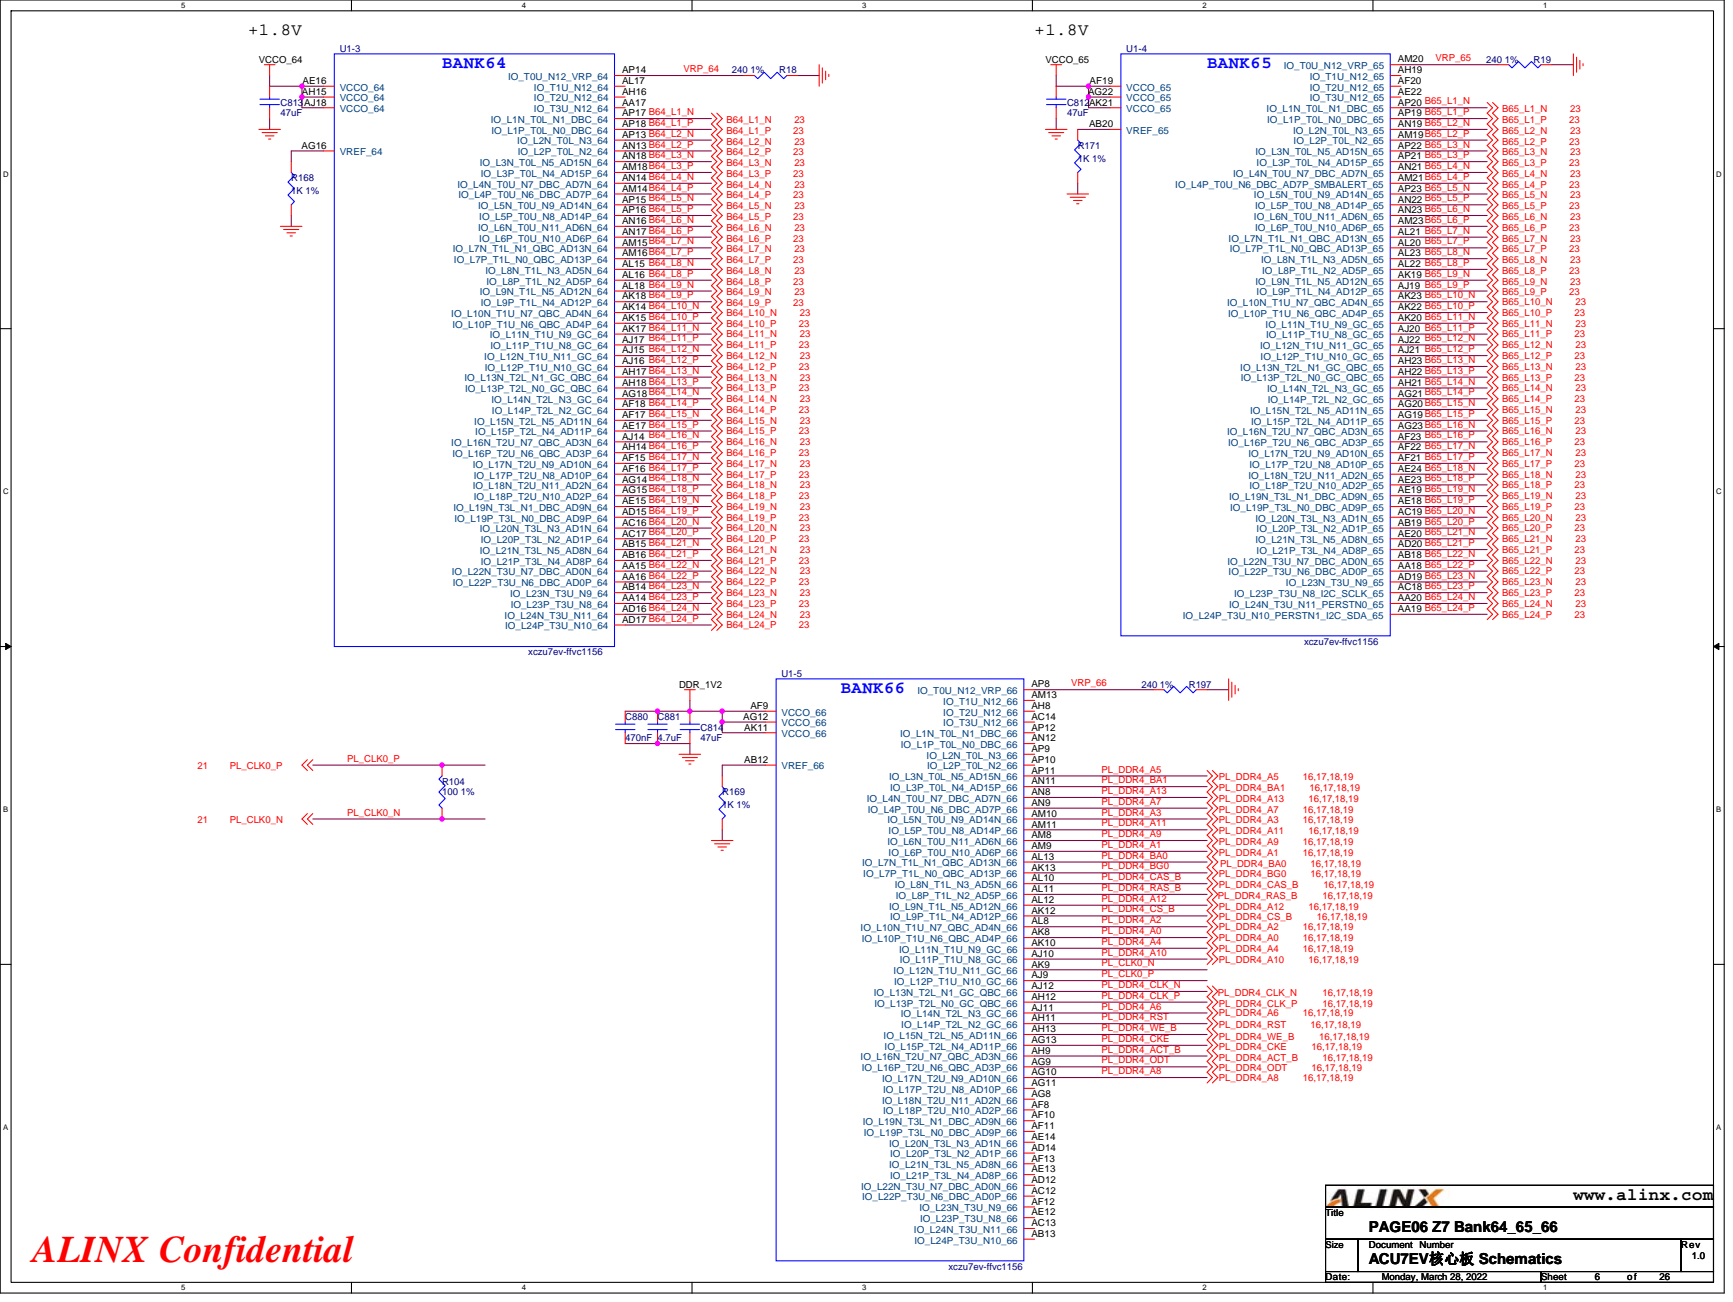
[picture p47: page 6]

# BANK224

# BANK225

1.8V

0.85V

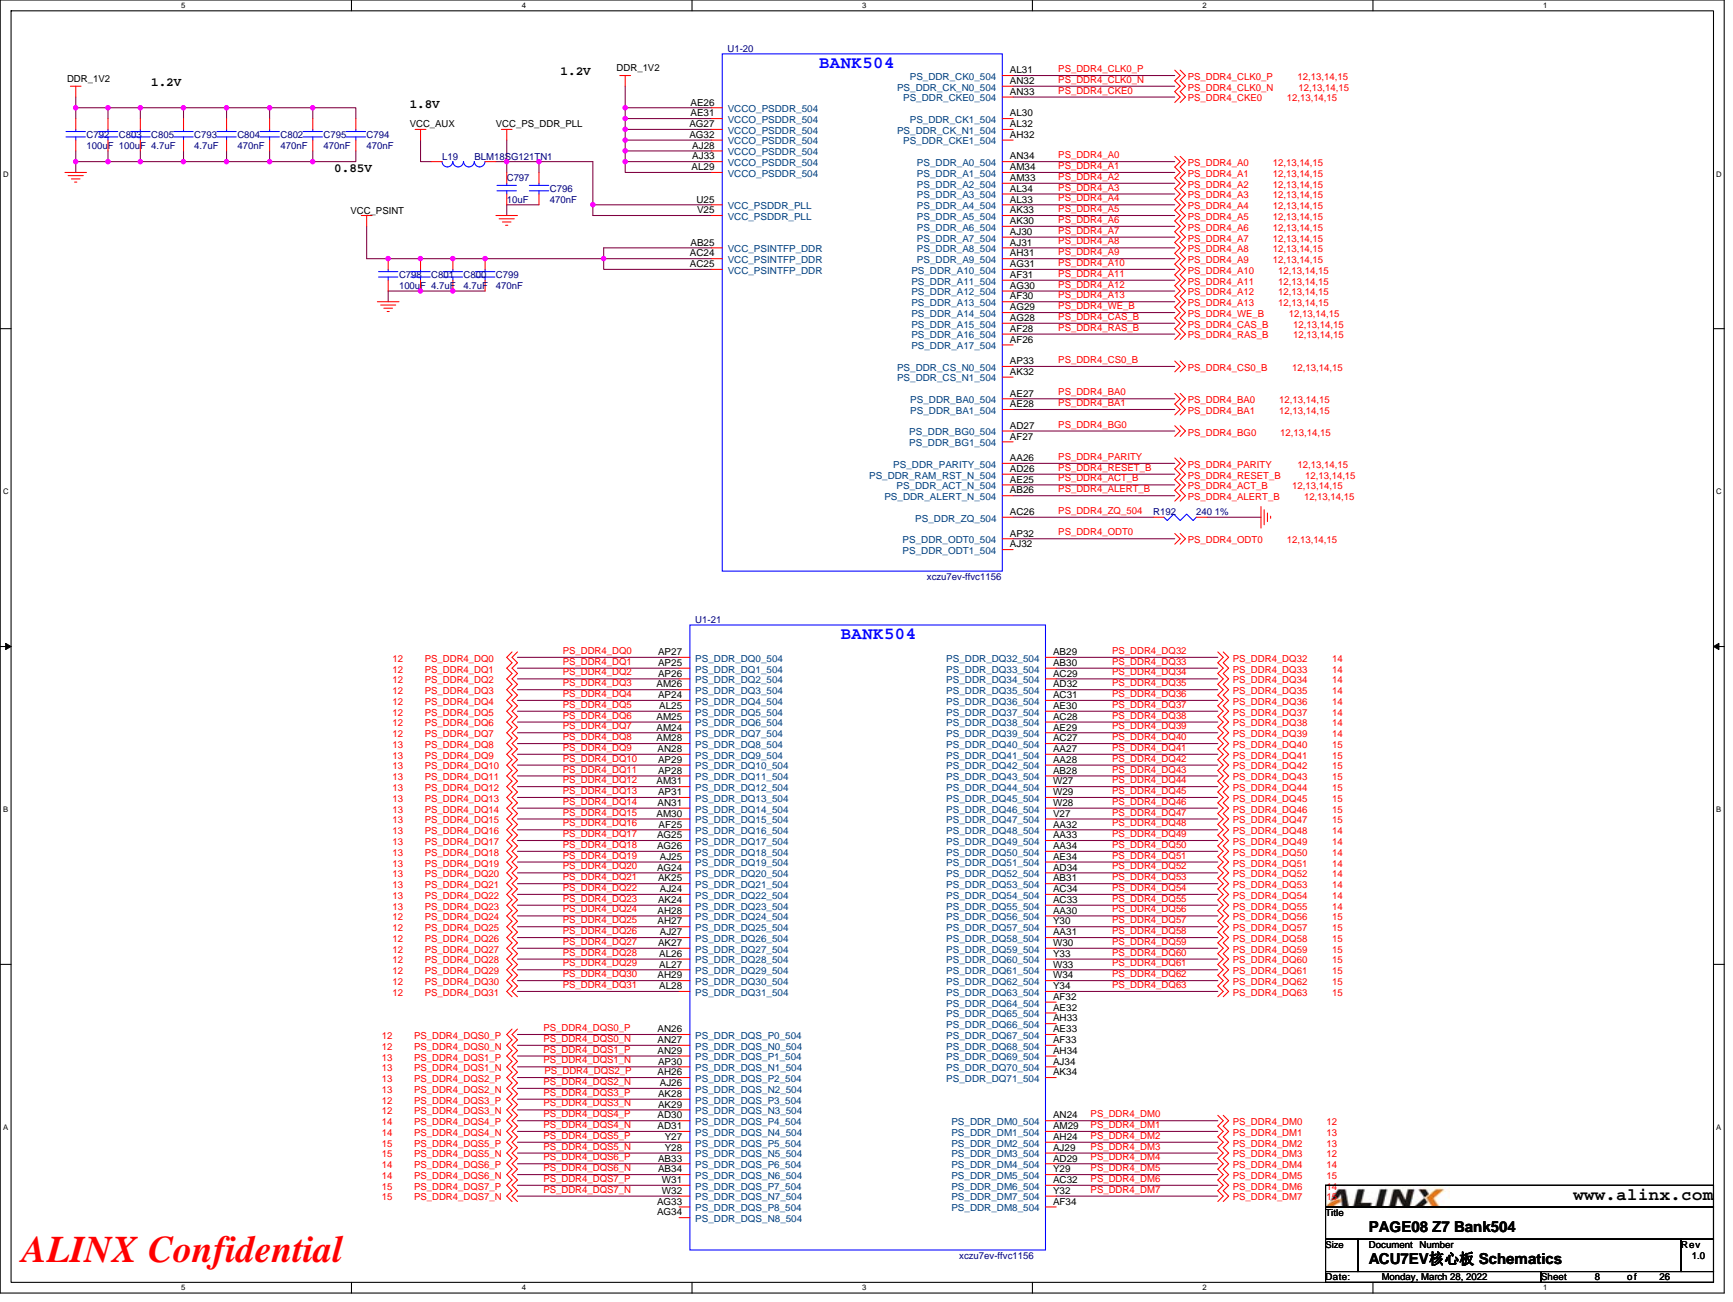
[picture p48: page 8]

# POWER ON: VCCINT/VCCINT_IO/VCCBRAM(+0.85V)->VCCAUX/VCCAUX_IO(+1.8V)->VCCO(+3.3V, +1.8V)

0.9V

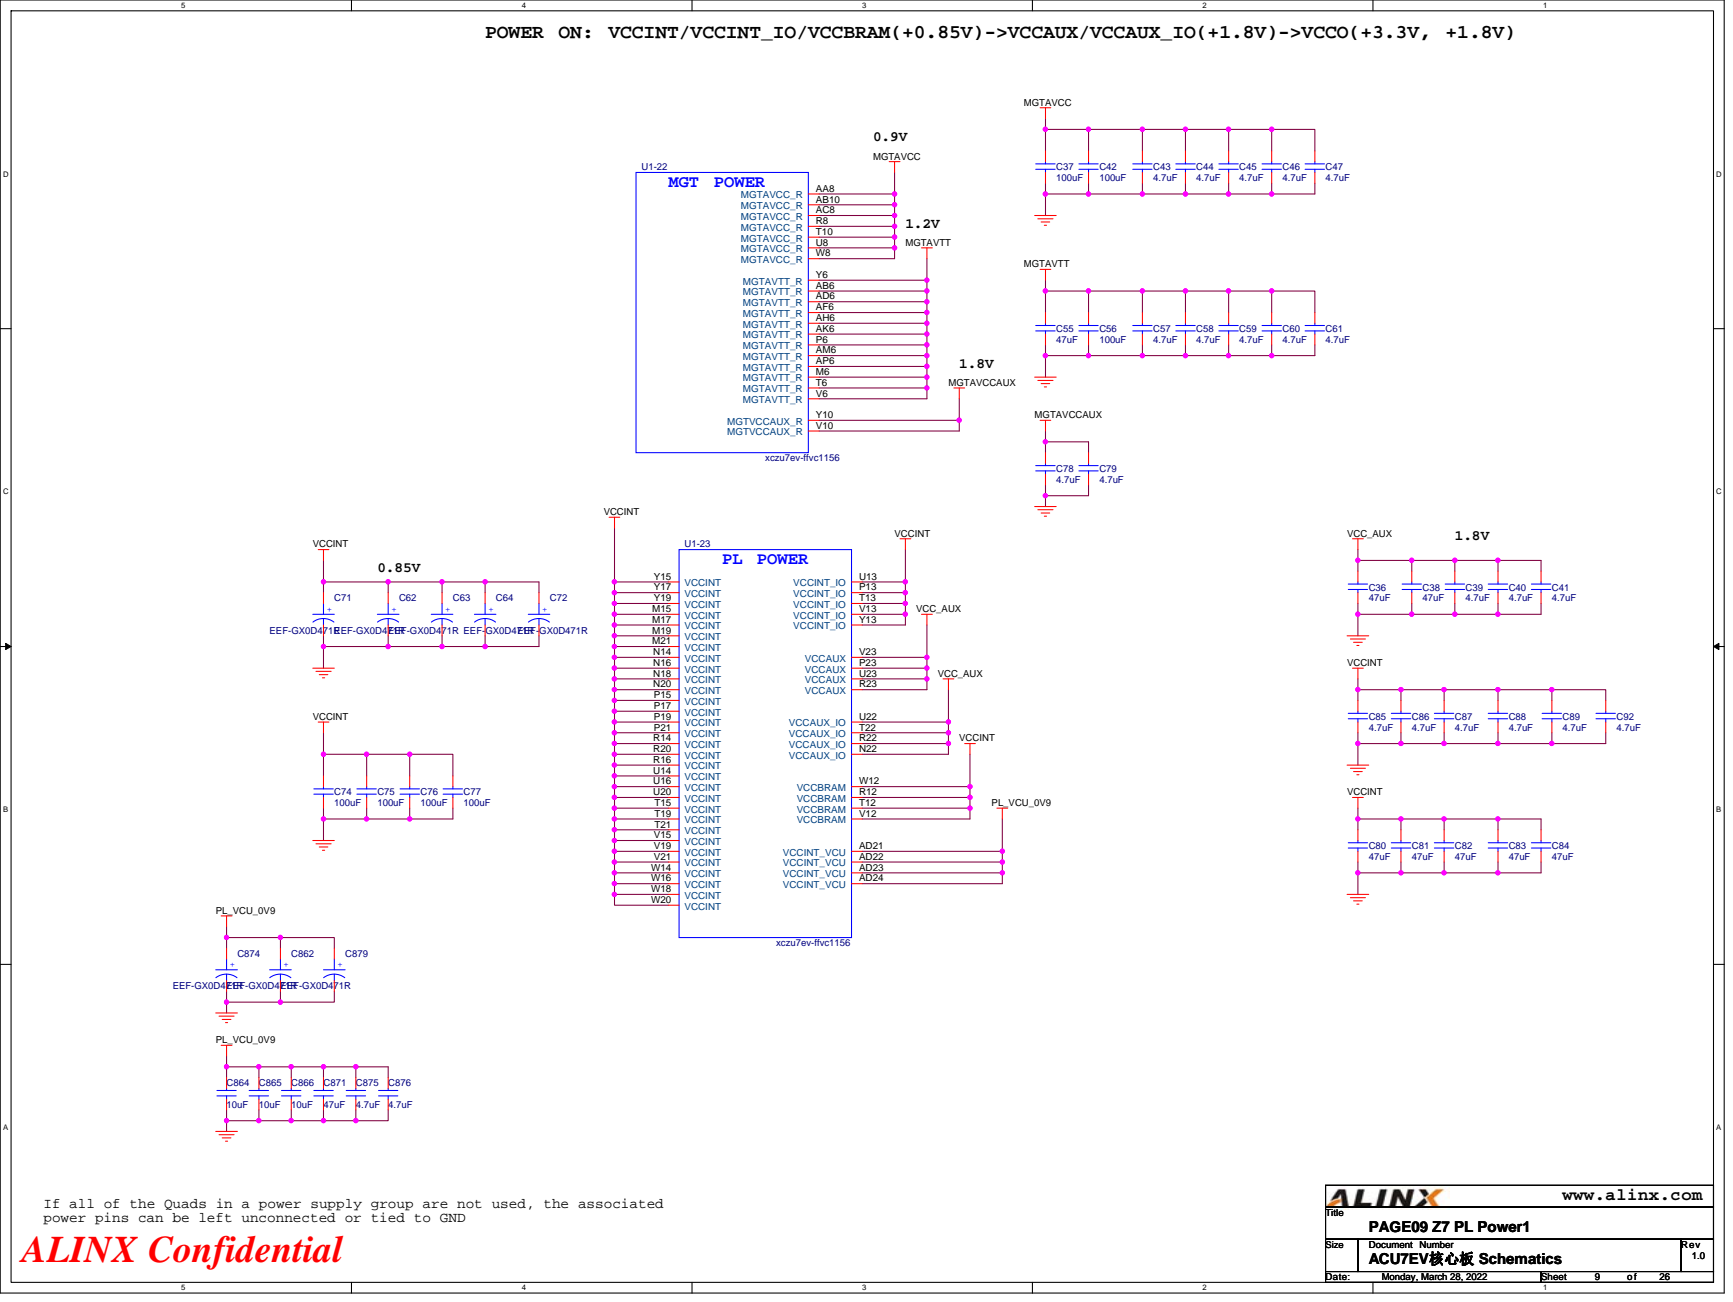
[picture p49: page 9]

www.alinx.com If all of the Quads in a power supply group are not used, the associated
power pins can be left unconnected or tied to GND

POWER ON: VCC_PSINTFP/VCC_PSINTFP_DDR(+0.85V)->VPS_MGTRAVCC(+0.9V),VCC_PSDDR_PLL(+1.8V)->VPS_MGTRAVTT(+1.8V),VCCO_PSDDR() POWER ON: VCC_PSINTLP(+0.85V)->VCC_PSAUX(+1.8V),VCC_PSADC(+1.8V),VCC_PSPLL(+1.2V)->VCCO_PSIO(+1.8V)

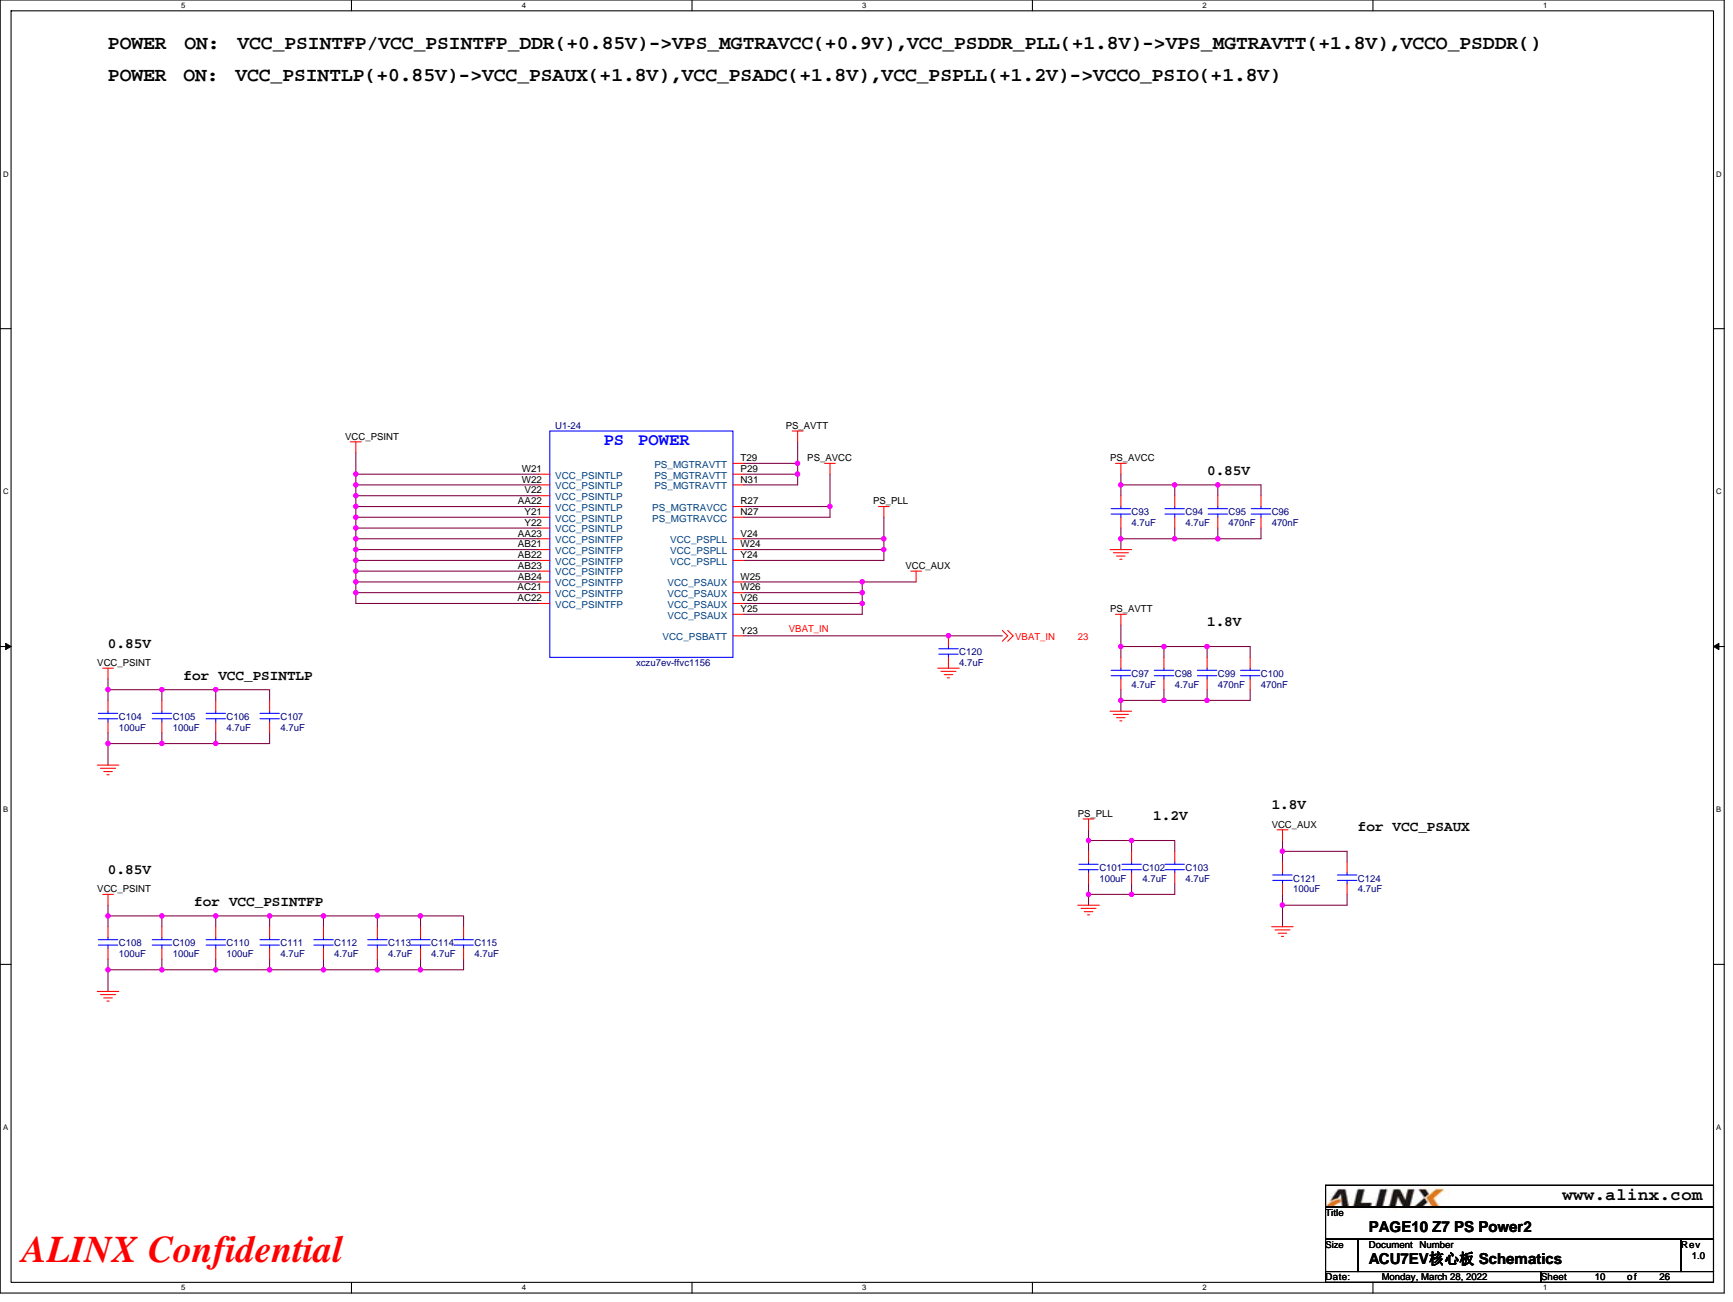
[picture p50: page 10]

# GND2

# GND1

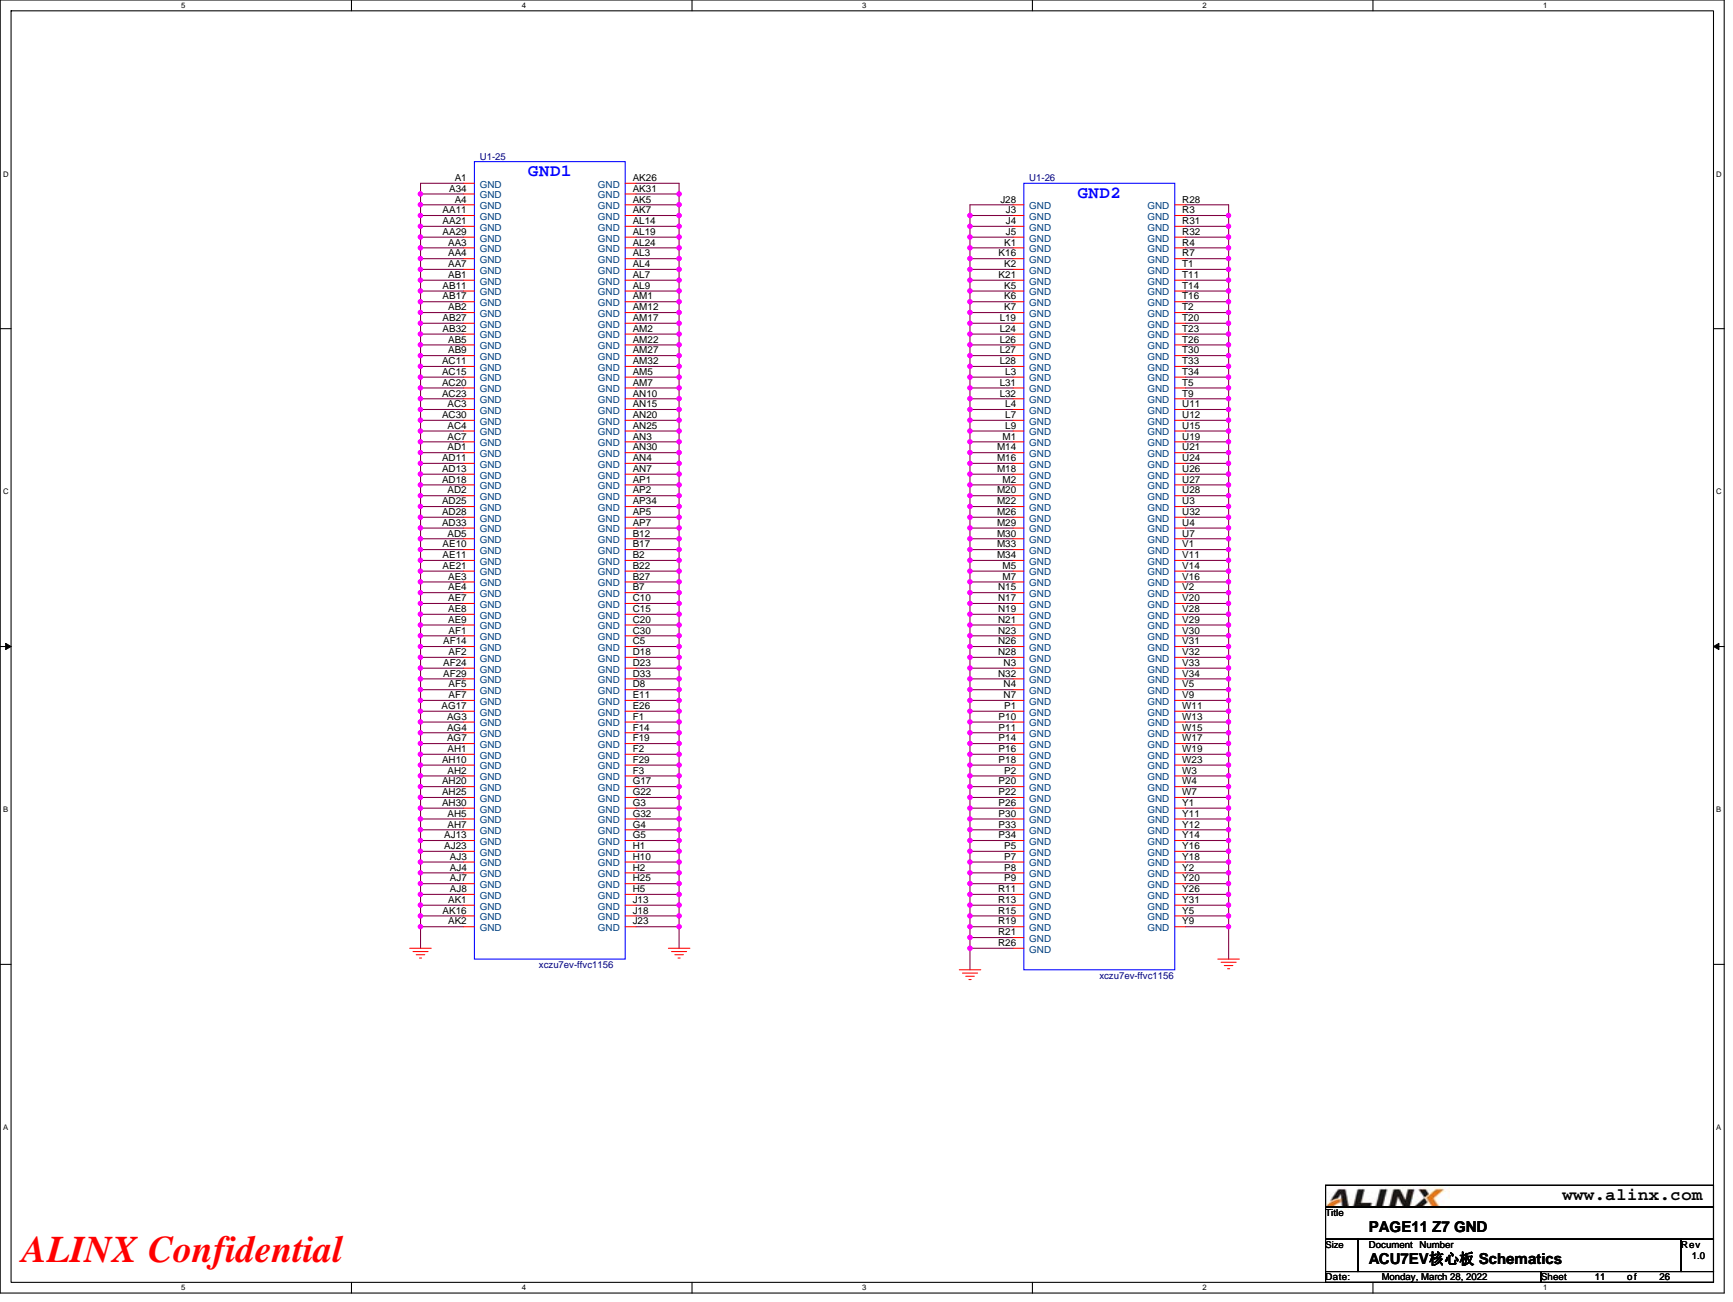
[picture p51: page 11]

1.2V

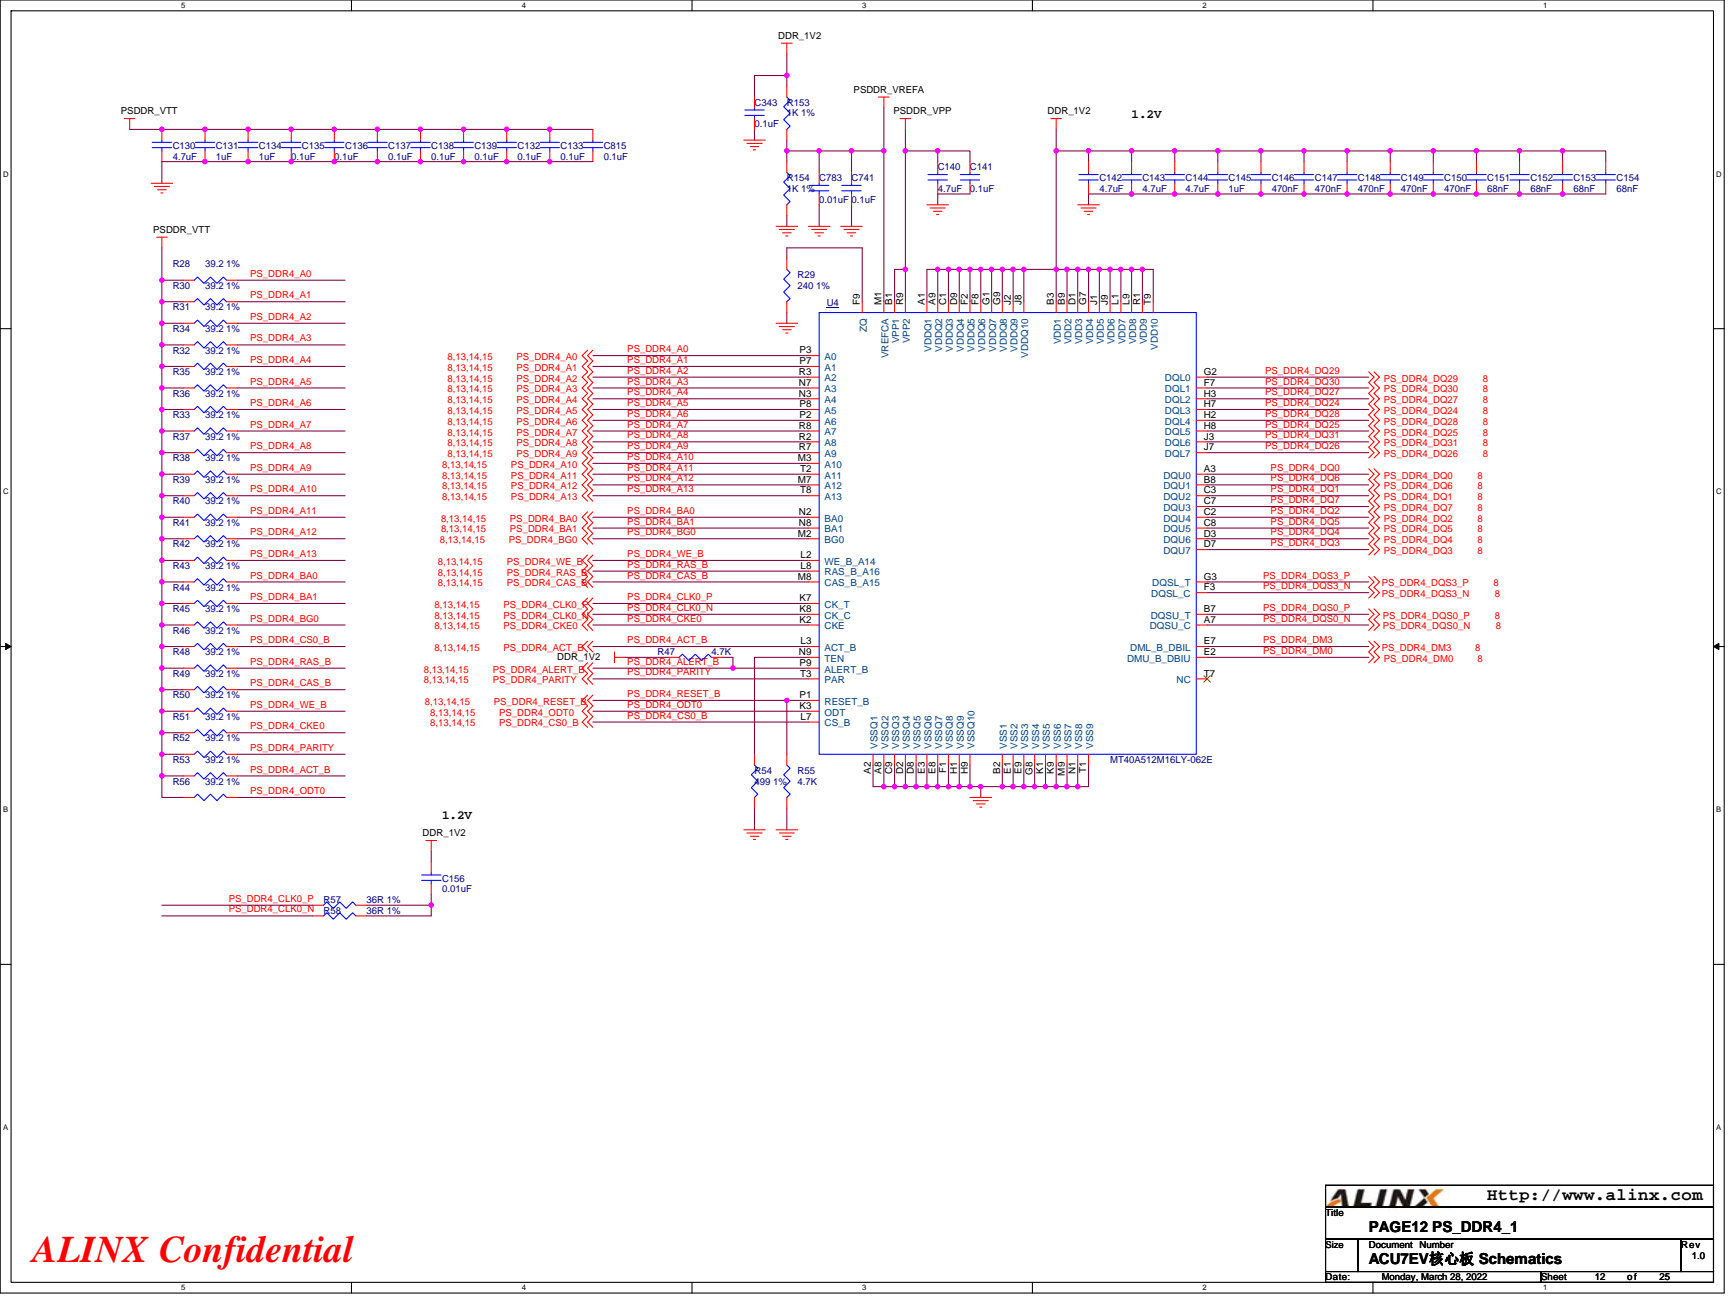
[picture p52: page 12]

Http://www.alinx.com

1.2V

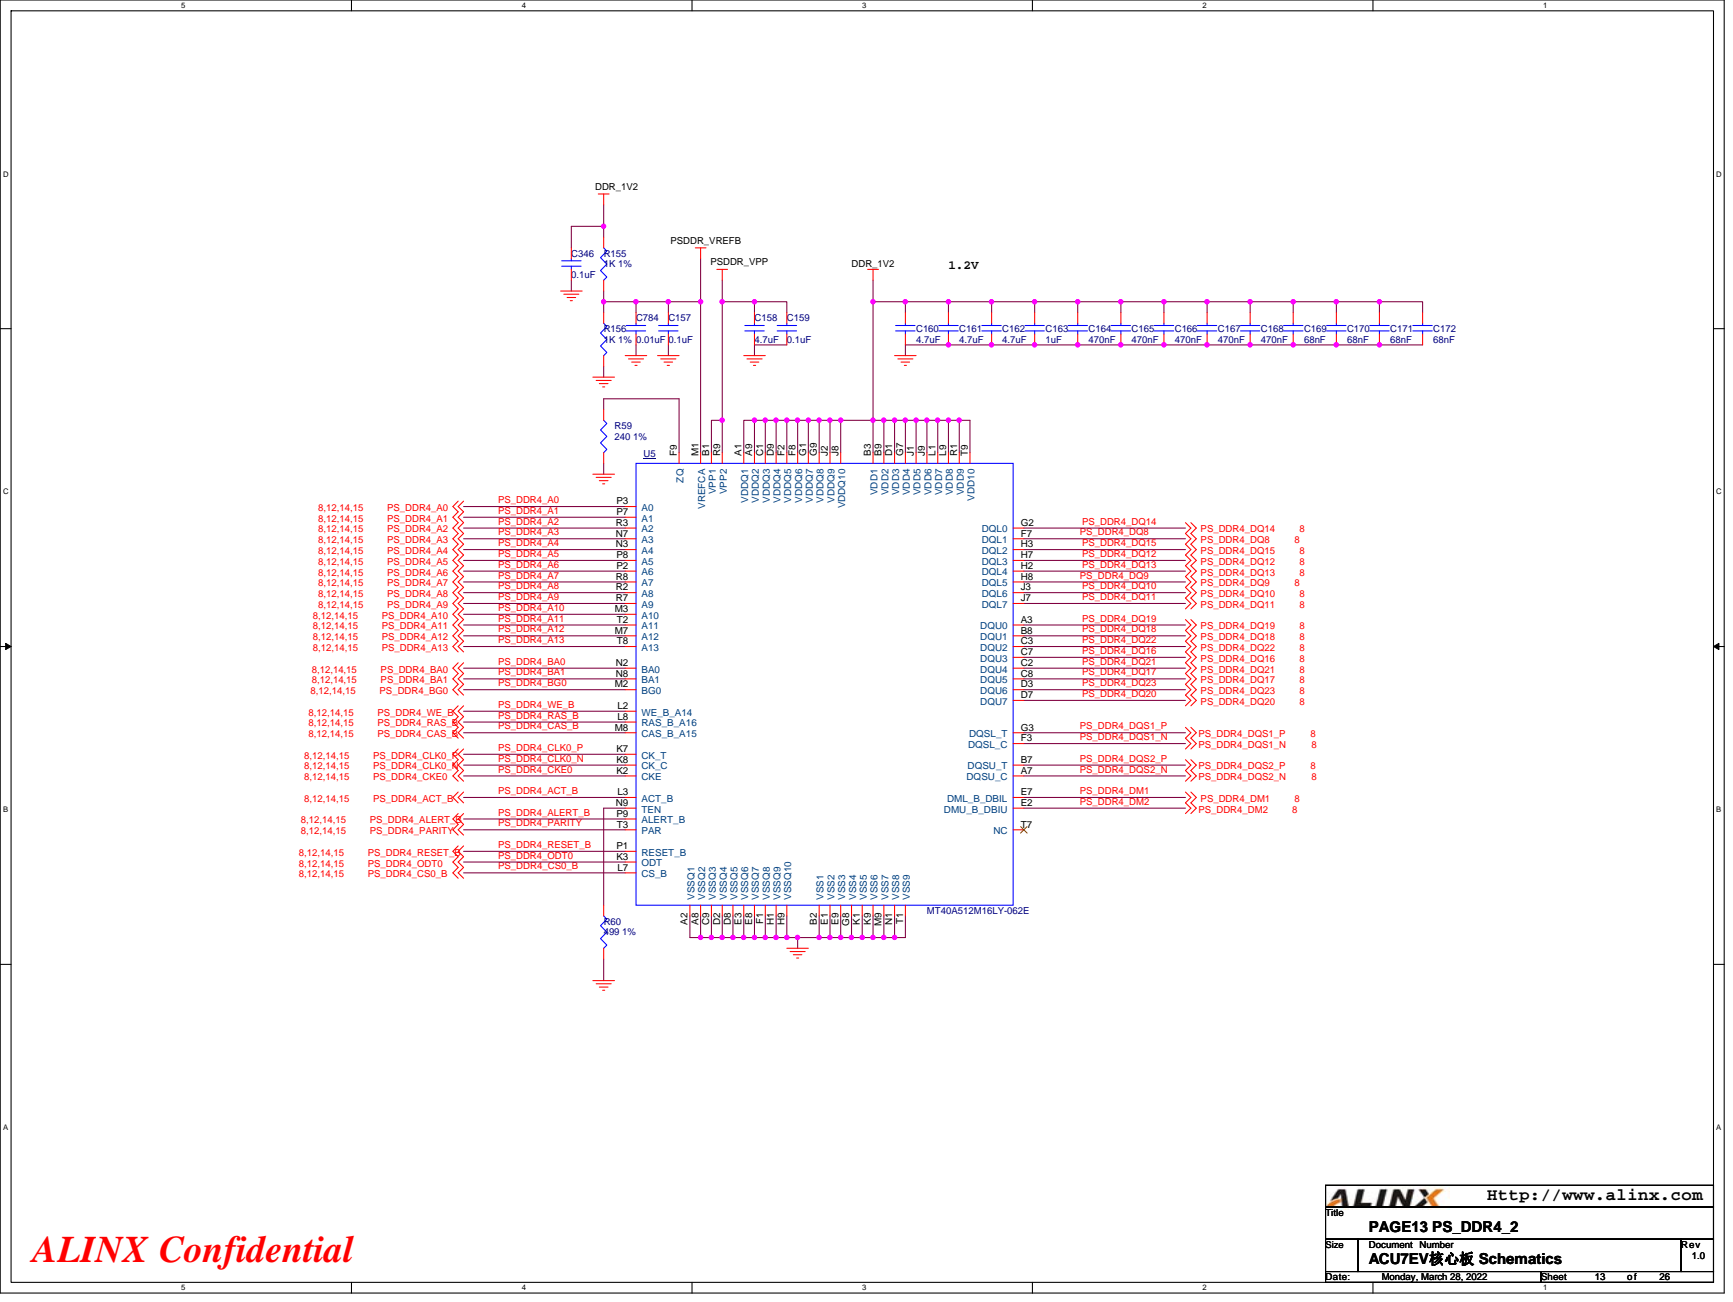
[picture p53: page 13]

Http://www.alinx.com

1.2V


Http://www.alinx.com

1.2V


Http://www.alinx.com


Http://www.alinx.com


Http://www.alinx.com


Http://www.alinx.com

Http://www.alinx.com


# 200MHz

# PL SYSTEM CLOCK


# BANK28 IO Voltage is 1.8V Stardard BANK87,88 IO Voltage is 3.3V Stardard

PS_POR_B FPGA_DONE; SD_CMD; SD_CLK; PHY1_RXD3; PHY1_TXD2; PHY1_TXD0; PHY1_TXD3 PHY1_TXCK; PHY1_RXD2 PHY1_RXD1; PHY1_TXD1; PHY1_TXCTL; PHY1_RXD0; PHY1_RXCK; PHY1_RXCTL; PHY1_MDC PHY1_MDIO; USB_STP USB_DIR; USB_CLK USB_NXT USB_DATA0 USB_DATA1; USB_DATA2 USB_DATA3 USB_DATA4 USB_DATA5; USB_DATA6 USB_DATA7; PS_MIO28; PS_MIO30; PS_MIO27; PS_MIO43; PS_MIO31; PS_MIO26; PS_MIO35; PS_MIO40 PS_MIO44 PS_MIO39; PS_MIO32; PS_MIO38; PS_MIO29; PS_MIO34 PS_MIO42; PS_MIO33; PS_MIO37; PS_MIO41; PS_MIO36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

MIO/SD/USB/ETH IO Voltage is 1.8V Stardard

Http://www.alinx.com

# BANK64,65 IO Voltage is 1.8V Stardard

VBAT_IN; 223_CLK1_N; 223_CLK1_P; 224_CLK1_N; 224_CLK1_P; 224_CLK0_N; 224_CLK0_P; 225_CLK0_N; 225_CLK1_P; 225_CLK0_P; 225_CLK1_N; 226_CLK1_P 226_CLK1_N; 223_CLK0_P 223_CLK0_N; POWER_SW; 226_CLK0_P 226_CLK0_N; 226_CLK1_P; 226_CLK1_N; 223_CLK0_P; 223_CLK0_N; 226_CLK0_P; 226_CLK0_N; PAGE23 Connector_2; Tuesday, January 31, 2023; AXK5A2137YG

Http://www.alinx.com

# GPO1-----BUCK2_PG GPO4-----BUCK4_PG


PSDDR_VPP | | LDOA1 9

VTT 47 | | 0.1uF | 10uF

VCCO_HDIO | LDOA2 51

VCCO_HPIO | LDOA3 49

VREF 53

PMIC_3V3_LDO | | LDO3P3 54

LDO5P0 56 | R99 11K 1%

+0.85V 25A


PASS A6 TAKE A7 Vout A8 GND B1 GND B2 GND B3 GND B4 GND B5 GND B6 Vout B7 Vout B8 GND C1 GND C2 GND C3 GND C4 GND C5 GND C6 Vout C7 Vout C8 Vin D1 Vin D2 GND D3 GND D4 GND D5 GND D6 Vout D7 Vout D8 Vin E1 Vin E2 GND E3 GND E4 GND E5 GND E6 GND E7 GND E8 Vin F1 Vin F2 GND F3 GND F4 GND F5 GND F6 GND F7 GND F8 VCC G1 -Sense G2 Trim G3 +Sense G4 ISUM G5 ADDR G6 NC G7 SET G8

1.5A | 1.5A | 1.8V 0.85V


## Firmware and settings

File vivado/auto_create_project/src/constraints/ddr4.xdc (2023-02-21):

set_property PACKAGE_PIN AK8	[ get_ports "c0_ddr4_adr[0]" ]
set_property PACKAGE_PIN AM9	[ get_ports "c0_ddr4_adr[1]" ]
set_property PACKAGE_PIN AL8	[ get_ports "c0_ddr4_adr[2]" ]
set_property PACKAGE_PIN AM10 [ get_ports "c0_ddr4_adr[3]" ]
set_property PACKAGE_PIN AK10 [ get_ports "c0_ddr4_adr[4]" ]
set_property PACKAGE_PIN AP11 [ get_ports "c0_ddr4_adr[5]" ]
set_property PACKAGE_PIN AJ11 [ get_ports "c0_ddr4_adr[6]" ]
set_property PACKAGE_PIN AN9	[ get_ports "c0_ddr4_adr[7]" ]
set_property PACKAGE_PIN AG10 [ get_ports "c0_ddr4_adr[8]" ]
set_property PACKAGE_PIN AM8	[ get_ports "c0_ddr4_adr[9]" ]
set_property PACKAGE_PIN AJ10 [ get_ports "c0_ddr4_adr[10]" ]
set_property PACKAGE_PIN AM11 [ get_ports "c0_ddr4_adr[11]" ]
set_property PACKAGE_PIN AL12 [ get_ports "c0_ddr4_adr[12]" ]
set_property PACKAGE_PIN AN8	[ get_ports "c0_ddr4_adr[13]" ]
set_property PACKAGE_PIN AH13 [ get_ports "c0_ddr4_adr[14]" ]
set_property PACKAGE_PIN AL10 [ get_ports "c0_ddr4_adr[15]" ]
set_property PACKAGE_PIN AL11 [ get_ports "c0_ddr4_adr[16]" ]

set_property PACKAGE_PIN AL13 [ get_ports "c0_ddr4_ba[0]" ]
set_property PACKAGE_PIN AN11 [ get_ports "c0_ddr4_ba[1]" ]
set_property PACKAGE_PIN AK13 [ get_ports "c0_ddr4_bg[0]" ]

set_property PACKAGE_PIN AH12 [ get_ports "c0_ddr4_ck_t[0]" ]
set_property PACKAGE_PIN AJ12 [ get_ports "c0_ddr4_ck_c[0]" ]
set_property PACKAGE_PIN AG13 [ get_ports "c0_ddr4_cke[0]" ]

set_property PACKAGE_PIN AH9 [ get_ports "c0_ddr4_act_n" ]

set_property PACKAGE_PIN AH11 [ get_ports "c0_ddr4_reset_n" ]
set_property PACKAGE_PIN AG9 [ get_ports "c0_ddr4_odt[0]" ]
set_property PACKAGE_PIN AK12 [ get_ports "c0_ddr4_cs_n[0]" ]

set_property PACKAGE_PIN G14 [ get_ports "c0_ddr4_dqs_t[0]" ]
set_property PACKAGE_PIN F13 [ get_ports "c0_ddr4_dqs_c[0]" ]
set_property PACKAGE_PIN D16 [ get_ports "c0_ddr4_dm_n[0]" ]
set_property PACKAGE_PIN E17 [ get_ports "c0_ddr4_dq[0]" ]
set_property PACKAGE_PIN D15 [ get_ports "c0_ddr4_dq[1]" ]
set_property PACKAGE_PIN D17 [ get_ports "c0_ddr4_dq[2]" ]
set_property PACKAGE_PIN E14 [ get_ports "c0_ddr4_dq[3]" ]
set_property PACKAGE_PIN E18 [ get_ports "c0_ddr4_dq[4]" ]
set_property PACKAGE_PIN D14 [ get_ports "c0_ddr4_dq[5]" ]
set_property PACKAGE_PIN E15 [ get_ports "c0_ddr4_dq[6]" ]
set_property PACKAGE_PIN C17 [ get_ports "c0_ddr4_dq[7]" ]

set_property PACKAGE_PIN B14 [ get_ports "c0_ddr4_dqs_t[1]" ]
set_property PACKAGE_PIN B13 [ get_ports "c0_ddr4_dqs_c[1]" ]
set_property PACKAGE_PIN A17 [ get_ports "c0_ddr4_dm_n[1]" ]
set_property PACKAGE_PIN B16 [ get_ports "c0_ddr4_dq[8]" ]
set_property PACKAGE_PIN C13 [ get_ports "c0_ddr4_dq[9]" ]
set_property PACKAGE_PIN A15 [ get_ports "c0_ddr4_dq[10]" ]
set_property PACKAGE_PIN A13 [ get_ports "c0_ddr4_dq[11]" ]
set_property PACKAGE_PIN B15 [ get_ports "c0_ddr4_dq[12]" ]
set_property PACKAGE_PIN A12 [ get_ports "c0_ddr4_dq[13]" ]
set_property PACKAGE_PIN A14 [ get_ports "c0_ddr4_dq[14]" ]
set_property PACKAGE_PIN C12 [ get_ports "c0_ddr4_dq[15]" ]

set_property PACKAGE_PIN H18 [ get_ports "c0_ddr4_dqs_t[2]" ]
set_property PACKAGE_PIN H17 [ get_ports "c0_ddr4_dqs_c[2]" ]
set_property PACKAGE_PIN F17 [ get_ports "c0_ddr4_dm_n[2]" ]
set_property PACKAGE_PIN H19 [ get_ports "c0_ddr4_dq[16]" ]
set_property PACKAGE_PIN H16 [ get_ports "c0_ddr4_dq[17]" ]
set_property PACKAGE_PIN G18 [ get_ports "c0_ddr4_dq[18]" ]
set_property PACKAGE_PIN G16 [ get_ports "c0_ddr4_dq[19]" ]
set_property PACKAGE_PIN G19 [ get_ports "c0_ddr4_dq[20]" ]
set_property PACKAGE_PIN F15 [ get_ports "c0_ddr4_dq[21]" ]
set_property PACKAGE_PIN F18 [ get_ports "c0_ddr4_dq[22]" ]
set_property PACKAGE_PIN G15 [ get_ports "c0_ddr4_dq[23]" ]

set_property PACKAGE_PIN L15 [ get_ports "c0_ddr4_dqs_t[3]" ]
set_property PACKAGE_PIN K15 [ get_ports "c0_ddr4_dqs_c[3]" ]
set_property PACKAGE_PIN L20 [ get_ports "c0_ddr4_dm_n[3]" ]
set_property PACKAGE_PIN L16 [ get_ports "c0_ddr4_dq[24]" ]
set_property PACKAGE_PIN J17 [ get_ports "c0_ddr4_dq[25]" ]
set_property PACKAGE_PIN K19 [ get_ports "c0_ddr4_dq[26]" ]
set_property PACKAGE_PIN K17 [ get_ports "c0_ddr4_dq[27]" ]
set_property PACKAGE_PIN L17 [ get_ports "c0_ddr4_dq[28]" ]
set_property PACKAGE_PIN J16 [ get_ports "c0_ddr4_dq[29]" ]
set_property PACKAGE_PIN K18 [ get_ports "c0_ddr4_dq[30]" ]
set_property PACKAGE_PIN J15 [ get_ports "c0_ddr4_dq[31]" ]

set_property PACKAGE_PIN D11 [ get_ports "c0_ddr4_dqs_t[4]" ]
set_property PACKAGE_PIN D10 [ get_ports "c0_ddr4_dqs_c[4]" ]
set_property PACKAGE_PIN H11 [ get_ports "c0_ddr4_dm_n[4]" ]
set_property PACKAGE_PIN C11 [ get_ports "c0_ddr4_dq[32]" ]
set_property PACKAGE_PIN F12 [ get_ports "c0_ddr4_dq[33]" ]
set_property PACKAGE_PIN E12 [ get_ports "c0_ddr4_dq[34]" ]
set_property PACKAGE_PIN F11 [ get_ports "c0_ddr4_dq[35]" ]
set_property PACKAGE_PIN D12 [ get_ports "c0_ddr4_dq[36]" ]
set_property PACKAGE_PIN H12 [ get_ports "c0_ddr4_dq[37]" ]
set_property PACKAGE_PIN H13 [ get_ports "c0_ddr4_dq[38]" ]
set_property PACKAGE_PIN E10 [ get_ports "c0_ddr4_dq[39]" ]
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

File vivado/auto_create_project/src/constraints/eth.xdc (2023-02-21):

 
set_property PACKAGE_PIN AN16 [get_ports {mdio_mdc                    }] 
set_property PACKAGE_PIN AN17 [get_ports {mdio_mdio_io            }] 
set_property PACKAGE_PIN AG23 [get_ports {phy_reset_n                  }] 
set_property PACKAGE_PIN AH22 [get_ports {rgmii_rxc                  }] 
set_property PACKAGE_PIN AN19 [get_ports {rgmii_rx_ctl            }] 
set_property PACKAGE_PIN AM19 [get_ports {rgmii_rd[0]              }] 
set_property PACKAGE_PIN AE24 [get_ports {rgmii_rd[1]              }] 
set_property PACKAGE_PIN AE23 [get_ports {rgmii_rd[2]              }] 
set_property PACKAGE_PIN AA19 [get_ports {rgmii_rd[3]              }] 
set_property PACKAGE_PIN AP22 [get_ports {rgmii_txc                  }] 
set_property PACKAGE_PIN AF23 [get_ports {rgmii_tx_ctl            }] 
set_property PACKAGE_PIN AM23 [get_ports {rgmii_td[0]              }] 
set_property PACKAGE_PIN AN23 [get_ports {rgmii_td[1]              }] 
set_property PACKAGE_PIN AH23 [get_ports {rgmii_td[2]              }] 
set_property PACKAGE_PIN AP21 [get_ports {rgmii_td[3]              }] 
 
set_property IOSTANDARD LVCMOS18 [get_ports {mdio_mdc                    }] 
set_property IOSTANDARD LVCMOS18 [get_ports {mdio_mdio_io            }] 
set_property IOSTANDARD LVCMOS18 [get_ports {phy_reset_n                  }] 
set_property IOSTANDARD LVCMOS18 [get_ports {rgmii_rxc                  }] 
set_property IOSTANDARD LVCMOS18 [get_ports {rgmii_rx_ctl            }] 
set_property IOSTANDARD LVCMOS18 [get_ports {rgmii_rd[0]              }] 
set_property IOSTANDARD LVCMOS18 [get_ports {rgmii_rd[1]              }] 
set_property IOSTANDARD LVCMOS18 [get_ports {rgmii_rd[2]              }] 
set_property IOSTANDARD LVCMOS18 [get_ports {rgmii_rd[3]              }] 
set_property IOSTANDARD LVCMOS18 [get_ports {rgmii_txc                  }] 
set_property IOSTANDARD LVCMOS18 [get_ports {rgmii_tx_ctl            }] 
set_property IOSTANDARD LVCMOS18 [get_ports {rgmii_td[0]              }] 
set_property IOSTANDARD LVCMOS18 [get_ports {rgmii_td[1]              }] 
set_property IOSTANDARD LVCMOS18 [get_ports {rgmii_td[2]              }] 
set_property IOSTANDARD LVCMOS18 [get_ports {rgmii_td[3]              }] 

set_property UNAVAILABLE_DURING_CALIBRATION TRUE [get_ports mdio_mdio_io]
set_property UNAVAILABLE_DURING_CALIBRATION TRUE [get_ports rgmii_tx_ctl]


set_property IODELAY_GROUP rgmii_group [get_cells design_1_i/gmii_to_rgmii_0/U0/i_design_1_gmii_to_rgmii_0_0_idelayctrl]
set_property IODELAY_GROUP rgmii_group [get_cells design_1_i/gmii_to_rgmii_0/U0/i_gmii_to_rgmii_block/design_1_gmii_to_rgmii_0_0_core/i_gmii_to_rgmii/i_gmii_to_rgmii/gen_rgmii_rx_zqup.delay_rgmii_rx_ctl]
set_property IODELAY_GROUP rgmii_group [get_cells design_1_i/gmii_to_rgmii_0/U0/i_gmii_to_rgmii_block/design_1_gmii_to_rgmii_0_0_core/i_gmii_to_rgmii/i_gmii_to_rgmii/gen_rgmii_rx_zqup.rxdata_bus[*].delay_rgmii_rxd]
set_property DELAY_VALUE 150 [get_cells design_1_i/gmii_to_rgmii_0/U0/i_gmii_to_rgmii_block/design_1_gmii_to_rgmii_0_0_core/i_gmii_to_rgmii/i_gmii_to_rgmii/gen_rgmii_rx_zqup.delay_rgmii_rx_ctl]
set_property DELAY_VALUE 150 [get_cells design_1_i/gmii_to_rgmii_0/U0/i_gmii_to_rgmii_block/design_1_gmii_to_rgmii_0_0_core/i_gmii_to_rgmii/i_gmii_to_rgmii/gen_rgmii_rx_zqup.rxdata_bus[*].delay_rgmii_rxd]
set_property UNAVAILABLE_DURING_CALIBRATION TRUE [get_ports rgmii_td[2]]

#idelay
#set_property DELAY_VALUE 100 [get_cells ps_block/design_1_i/axi_ethernet_0/inst/mac/inst/tri_mode_ethernet_mac_i/rgmii_interface/delay_rgmii_rx_ctl]
#set_property DELAY_VALUE 100 [get_cells {ps_block/design_1_i/axi_ethernet_0/inst/mac/inst/tri_mode_ethernet_mac_i/rgmii_interface/rxdata_bus[0].delay_rgmii_rxd}]
#set_property DELAY_VALUE 100 [get_cells {ps_block/design_1_i/axi_ethernet_0/inst/mac/inst/tri_mode_ethernet_mac_i/rgmii_interface/rxdata_bus[1].delay_rgmii_rxd}]
#set_property DELAY_VALUE 100 [get_cells {ps_block/design_1_i/axi_ethernet_0/inst/mac/inst/tri_mode_ethernet_mac_i/rgmii_interface/rxdata_bus[2].delay_rgmii_rxd}]
#set_property DELAY_VALUE 100 [get_cells {ps_block/design_1_i/axi_ethernet_0/inst/mac/inst/tri_mode_ethernet_mac_i/rgmii_interface/rxdata_bus[3].delay_rgmii_rxd}]

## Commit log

2023-03-16 add linux
    [bsp.cfg, devtool-fragment.cfg]
2023-04-14 add hardware
    [ACU7EV.stp, ACU7EV_size_structure.dxf, Z7-P.stp]
